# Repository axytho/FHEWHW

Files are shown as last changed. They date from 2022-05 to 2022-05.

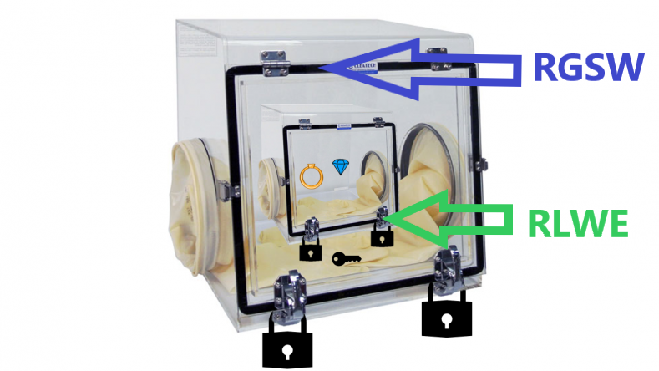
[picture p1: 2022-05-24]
ThesisProjectGit/Papers/graphicsDM/RLWERGSW.png

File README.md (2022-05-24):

# Parametric NTT/INTT Hardware

This repository provides the baseline version of Verilog code for parametric NTT/INTT hardware published in "<a href="https://ieeexplore.ieee.org/document/9171507">An Extensive Study of Flexible Design Methods for the Number Theoretic Transform</a>".

You have to set three parameters defined in `defines.v`:
* `DATA_SIZE_ARB`: bit-size of coefficient modulus *q* (constrained to the values between 8-64 for practical implementations)
* `RING_SIZE`: degree of ring polynomial, namely *n* in *x^n+1* (needs to be a power of 2)
* `PE_NUMBER`: number of processing elements (*butterfly units*) (needs to be a power of 2 and `PE_NUMBER` <= `RING_SIZE`/2)

Other versions of the hardware generator and documentation will be available soon.

If you use this work in your research/study, please cite our work:

```
@ARTICLE{9171507,
  author={A. C. {Mert} and E. {Karabulut} and E. {Ozturk} and E. {Savas} and A. {Aysu}},
  journal={IEEE Transactions on Computers}, 
  title={An Extensive Study of Flexible Design Methods for the Number Theoretic Transform}, 
  year={2020},
  volume={},
  number={},
  pages={1-1},
  doi={10.1109/TC.2020.3017930}}
```

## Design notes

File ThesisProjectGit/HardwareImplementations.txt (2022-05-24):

Hardware libraries:

Sujoy Roy's Coprocessor:
paper: https://www.iacr.org/archive/ches2014/87310183/87310183.pdf
hardware: https://github.com/sujoyetc/Ring-LWE-Cryptoprocessor

Tim Fritzmann's PQC accelerator:
paper: https://eprint.iacr.org/2020/446.pdf RISQ-V: Tightly Coupled RISC-V Accelerators for Post-Quantum Cryptography
Hardware: https://gitlab.lrz.de/tueisec/post-quantum-crypto
notes: ~10 times speedup of NewHope, 512 coefficient NTT in ~10 000 cycles

Parameterized Hardware Accelerators for Lattice-Based Cryptographyand Their Application to the HW/SW Co-Design of qTESLA
paper: https://caslab.csl.yale.edu/publications/wang2020parametrized.pdf
hardware: https://caslab.csl.yale.edu/code/qtesla-hw-sw-platform/
notes:  unified CT-GS-NTT algorithm specifically designed for polynomial multiplication (where you are doing NTT-1(NTT(A)*¨NTT(B)) )
for n=1024 and q = 343576577,  11455 cycles on ARtix-7

paper: https://ascslab.org/research/pqcp/index.html
hardware access: requesting it via e-mail

paper: http://www.cs.haifa.ac.il/~orrd/LC17/paper51.pdf
hardware access: https://www.seceng.ruhr-uni-bochum.de/research/publications/implementing-newhope-simple-key-exchange-low-cost-/

paper: https://eprint.iacr.org/2017/690.pdf
hardware access: cannot find a link, but I'll send a mail

ISA Extensions for Finite Field Arithmetic
%https://eprint.iacr.org/2020/049.pdf
source code?

FPGA-based High-Performance Parallel Architecture for Homomorphic Computing on Encrypted Data
https://github.com/KULeuven-COSIC/HEAT
HW can be requested

GPU implementation:
https://ieeexplore.ieee.org/stamp/stamp.jsp?tp=&arnumber=8855710
https://ieeexplore.ieee.org/stamp/stamp.jsp?tp=&arnumber=7245720

and full introduction on the NTT algorithm:
http://etd.lib.metu.edu.tr/upload/12625145/index.pdf

High performance NTT's!!!!! 
https://digitalcommons.wpi.edu/cgi/viewcontent.cgi?article=8433&context=mqp-all
THIS IS INTERESTING

Reuse one CRT block of the FV HEWS paper 			Check... (talk about it)
Modular reduction									check

Make look-up table which rotates through the accumulator  	check

Cut on the FV part.											check

Make clear that FV has bootstrapping but 								check
Just say you used SEAL and struggled a bit but don't go into detail.	check

Focus on the NTT diagram				check
Make mathematical part smaller			check
Focus on high level operation			check
No mathematical details					check

2 LWE cipher texts, you get another LWE.														uhm... somewhatcheck. 
You implement this by initializing a Look up table and then rotate this Look up table.			check
Cut slides.

One big table instead of slides																	check
Introduction slide of what NTT does and why it does don't explain Cooley Tukey: NTT is FFT on finite field. We need a very efficient 
Not going to do it from scratch																			check
These are open source, we will select one and impelement it
One final slide for plan, write a plannign table
Put changed planning on slide.

Present FHEW and don't talk about parameters yet
In the slides where you do matrix vector multiplication, these should be the parameters.
These are large polynomials, we need efficient polynomial multiplication

Don't show full algorithm!!! it makes no sense!
Look up tables. You rotate with matrix vector multiplication. At the end you'll have the correct value.
Focus on high-level.
Don't read from the paper.

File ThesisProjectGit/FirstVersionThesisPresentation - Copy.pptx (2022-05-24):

## Fastest Homomorphic Encryption in the West Hardware Acceleration

Master thesis presentation Jonas Bertels

## Selecting the scheme: (B)FV vs. FHEW

- Second Generation vs. Third generation

Faculty of Engineering Sciences, ESAT, COSIC

## Somewhat homomorphic encryption

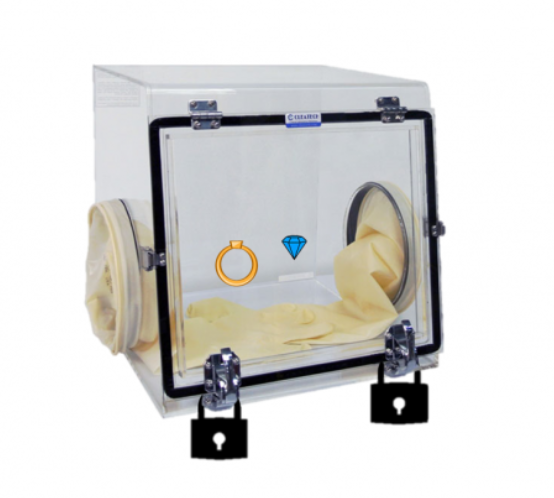
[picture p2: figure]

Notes: NOTE: IF EVERYONE KNOWS HOW HOMOMORPHIC ENCRYPTION WORKS, SKIP
The first major component of this thesis was selecting what homomorphic encryption scheme to implement. Before I go on, I first have to ask, is everyone here familiar with the basics of homomorphic encryption and bootstrapping?
If not:
Homomorphic encryption means encryption on which functions can still be executed. In 2009 Gentry showed that Fully Homomorphic encryption, doing an arbitrary amount of operations on encrypted data is possible. He later explained this using an analogy: imagine a jeweler Alice who wants to let her workers work on precious gems without them being able to steal the gems. She creates a box that allows the workers to manipulate the jewels, like this one. This box would Somewhat Homomorphic Encryption, because while the workers can do some operations, eventually the gloves break down and the workers have to bring the box back to Alice so that she can unlock the box, retrieve the finished jewels.

## Fully Homomorphic encryption: bootstrapping

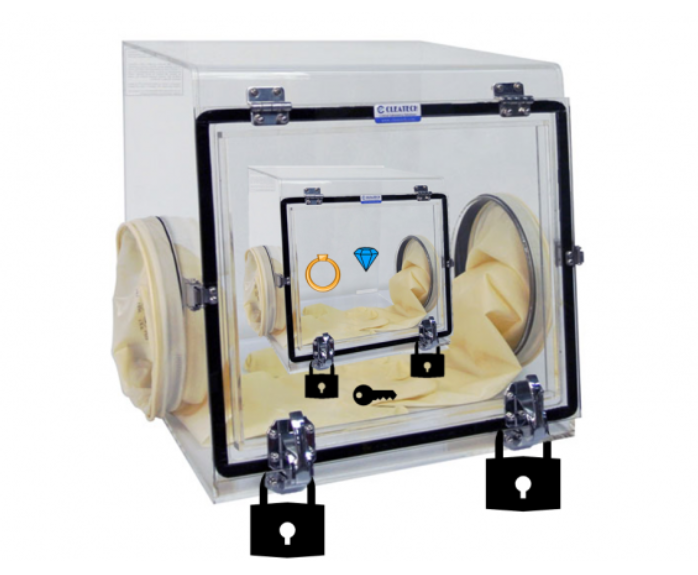
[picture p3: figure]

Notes: The idea behind bootstrapping is to turn Somewhat Homomorphic Encryption in to Fully homomorphic encryption by performing the decryption, i.e. the unlocking of the box, while everything is under another encryption. In our analogy, this would be like locking our box, in another box which already has a key for our box inside of it. (Since we using public/private key encryption, we place things into a locked box with the public key). Then our workers can open the inner box and continue working on the jewels. For an arbitrary amount of boxes, we can thus compute an arbitrary amount of functions on data that stays encrypted. The fact that gloves wear out in our analogy is representative of the fact that the homomorphic encryption schemes uses some form of numerical noise to mask the message. As we do addition, and especially multiplication, the amount of noise increases. At some point, decryption (whose last step is usually a sort of rounding operation to remove noise) will no longer return the correct answer.

## (R)LWE

For many vectors (ai,bi) ϵ (Rq, Rq), bi = ai * s+ ei with
- ei being a randomly sample error term
- s being our secret key
- ai being a randomly sampled but known vector
… it is not possible to find s (“not computationally feasible” (Roy et al.))
So good public key

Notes: Just for clarity, I am going to call the person with secret key who encrypted the data originally the user, and the person executing the function on the encrypted data the server.

An example of homomorphic encryption can be seen in the Fan-Vercauteren scheme. This is based on the Ring Learning With Errors Problem, which states the following. For many vectors (ai,bi) ϵ (Rq, Rq), bi = ai * s+ ei with ei being a randomly sample error term and s being our secret key and ai being a randomly sampled but known vector, it is not possible to find s (“not computationally feasible” (Roy et al.))

So in other words, we can use this term as a good public key for s since we can’t reverse engineer the secret from the public key. And this is the case if the server spends all day requesting public keys from the user to be able to guess the secret key.

## Scheme (simplified)

- Public key: ((-a*s-e)modq, a)
- Cipher text: ((-a*s-e)modq)*u+e1+m, a*u+e2) with u randomly sampled
- Then decryption can be done by multiplying the second part of the cipher text with s and adding it to the first part.

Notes: Now this is an extremely simplified version of the Fan Vercauteren scheme, just to give an idea: we generate our cipher text from our public key and our message, in such a way that we can get our message back by multiplying the second part of the cipher text with s and adding it to the first part.

## Homomorphic addition/multiplication

- Ct1 + ct2 = (2*(-a*s-e)modq)*u+e11+e12+m1+m2, 2*a*u+e21+e22) = m1+m2, with some error to be rounded off
- A multiplication also gives:
- The correct result + large error term + some factors multiplied by q.
- Now the result usually needs to be rescaled
- And polymial*polynomial = larger order polynomial, so linearization is necessary

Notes: Now why do we use this scheme? Because if we add the 2 ciphertexts or multiply the 2 cipherteksts, we still get the correct value after decryption! (if we’ve taken our modulus high enough).
Addition is the most straightforward: when we add, we add the 2 errors of the ciphertexts together and error growth is minimal.
Multiplication is much less straightforward. I did not write down all the terms of the multiplication, but to summarize: afterwards we need to rescale with a certain factor, and relinearize.

## Homomorphic multiplication

- As we’ve multiplied (cp1[0], cp1[1]) and (cp2[0], cp2[1]) together (remembering that cp1[0] + cp1[1]*s = message), can see m1 *m2 = cp1[0]*cp2[0] + cp1[0] *cp2[1]*s + cp1[1]*cp2[0]*s + cp1[1]*cp2[1] *s²
- So now a method to remove s² is also required
- And bootstrapping with this algorithm is not practical…

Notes: We need to rescale because the actual algorithm is scaling with a certain factor, and if you multiply 2 values scaled with a factor delta, the result will be scaled by a factor delta² and thus we need to divide back by delta to get our original scaling.
Secondly, we need to be able to remove the secret key squared term from our result. We call this the linearization step, but I will not go into details here.

## FV in SEAL

- Microsoft SEAL is a homomorphic encryption library that contains FV
- Tried implementing Arcsin(X/1500) *1/2 with arcsin(x) = x+x^3/6+3x^5/40
- Bootstrapping is not a thing, so not trivial to implement

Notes: To understand how FV actually worked and get an idea for the size of the parameters I was going to be working with, I installed micrsoft SEAL, a library for homomorphic encryption. I tried implementing a simple function (for calculating the angle you have to fire something at to reach a certain distance, which means calculating an arcsin, which can be approximated using a taylor expansion). Because there is no bootstrapping, it is necessary to determine in advance what size of polynomial coefficients will be for every multiplication done to calculate the polynomial series. Additionally, as the TA’s told me and I also found out by trying, it is hard to floating point operations with integers, when rescaling has to be done after every multiplication, requiring another multiplication with a constant factor.

## CKKS steps

- Choose coefficient
- Choose scale
- Generate public, private and relin keys

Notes: Therefore I switched to CKKS, which can be seen as a similar scheme designed for floating point operations.
To give an idea of what needs to be done: Firstly, the coefficient modulus of the polynomials must be chosen, so that there is enough noise budget to allow for the function that you want to execute. Then the scale (i.e. the precision of the floating point numbers) must also be chosen. Then public, private and realinerisation keys must be generated. Finally we can start doing multiplications and addition, but after every multiplication we must rescale and relinearize, and we need to do modulus switching as we go through the list of coefficient modulus primes that we generated to do our calculation.

## CKKS?

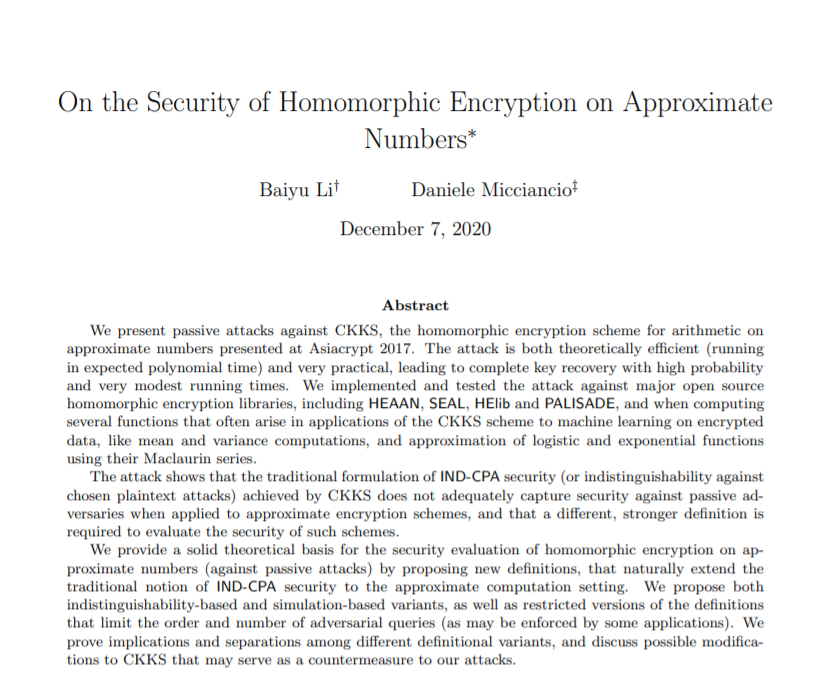
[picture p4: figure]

## Summary

- Good for SIMD
- Not good for depth of multiplications
- Somewhat inflexible

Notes: This required about a 100 lines of code for a rather simpel formula. It executed fairly quickly, and both FV and CKKS are good at allowing Single Instruction, Multiple Data, but as can be seen from this example, they only allow for a limited amount of computations, and algorithms that are already out there and require a lot of instructions will thus not easily translate in to programs that can homomorphically execute data.

They are however good at doing homomorphic encryptions for a given, low-depth application. This can also be seen in a hardware acceleration for the Fan-Vercauteren scheme done by COSIC in 2018. This implementation could do FV very quickly, at 400 homomorphic multiplications per second, but is limited to a multiplicative depth of 4. This is enough for a lot of applications, but can limit its flexibillity in a general role.

## FHEW (Fastest Homomorphic Encryption in the West)

- One NAND gate
- Bootstrap immediately
- 137ms for 128 bit security for 1 NAND + bootstrap
- No limit on function execution

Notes: FHEW, called that way as a reference to the Fastest Fourier Transform in the West library, is part of the so-called third generation schemes. It attempts to tackle the long length of the bootstrapping process by only executing one NAND gate (other simple gate functions are also possible) and then immediately bootstrapping.This makes it a true fully homomorphic scheme, as the bootstrapping can actually be done within a reasonable amount of time, namely 137miliseconds for NAND + bootstrap for 128 bit security on a intel i7. In other words, while only one NAND gate can be done at a time (later papers show parellisation is possible), there is no limit on the depth of our circuit, and as all functions can be written as a combination of logic gates, no limit on the functions that can be executed.

## Based on RLWE (from Ducas/Micciancio)

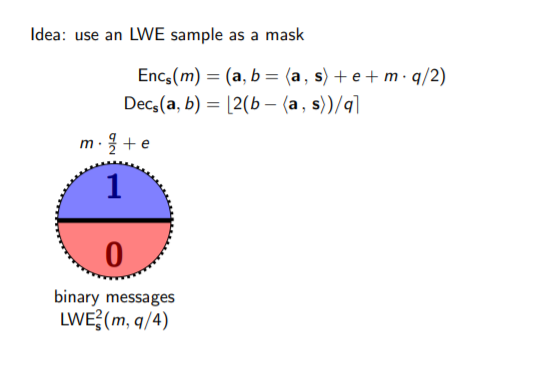
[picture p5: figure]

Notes: FHEW is also based on RLWE. The slides I’m about to show are taken from a excellent, very visual presentation by the creators of FHEW, Léo Ducas and Daniele Micciancio. Our message is a single bit. If it is 0, we could represent it as some error, if it is 1, we could represent it as 256 with some error added to it. (512 is a usual value for q). In this case our maximum error is equal to +/- 128.

## Based on RLWE (from Ducas/Micciancio)

- q = 512 so you can look at this as: if m = 0, we are in the lower half with e, if m=1, then we are in the upper half with 256 + e

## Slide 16

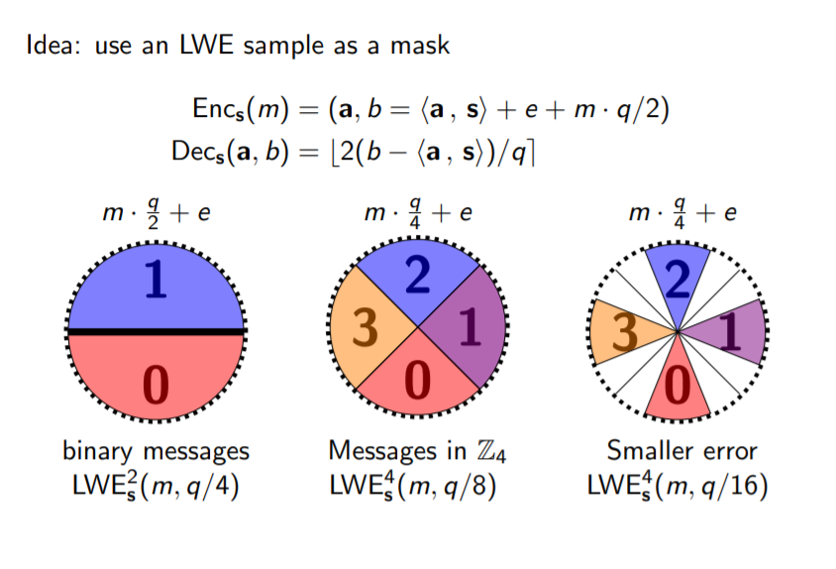
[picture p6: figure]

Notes: Now the representation that we use is one where there are 4 possible messages, with the message being multiplied by 128, or ¼ of the modulus q. We also have a smaller error of value 64 or q/8, so that there are values that are never reached by a given message and error. (these white spaces).

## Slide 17

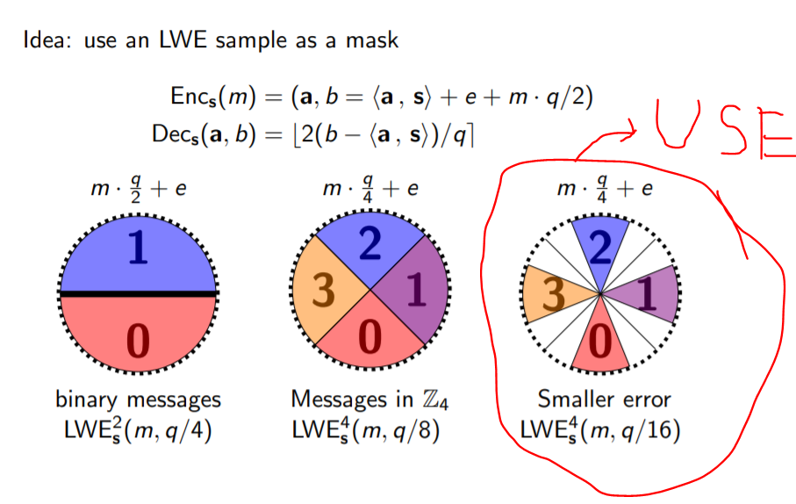
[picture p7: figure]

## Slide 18

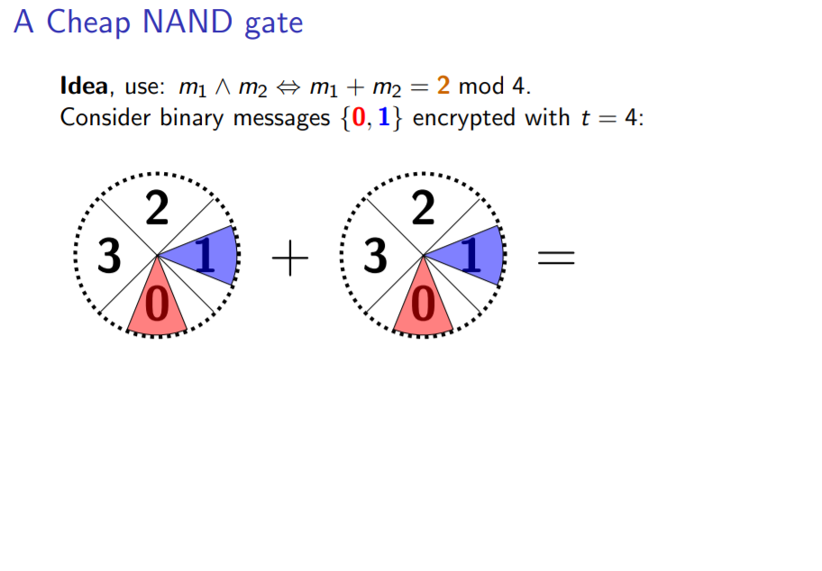
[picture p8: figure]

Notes: We can use this for addition. As you can see, the result now has more error than the beginning. Now if we consider every on the top left to be 1 and everything on the bottom right to be 0, we have a AND gate. To make this a NAND, we rotate by 5q/8, in other words we consider the bottom right to be 1 and the other 0 and this results in the results that we expect from a NAND gate for given input values.

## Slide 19

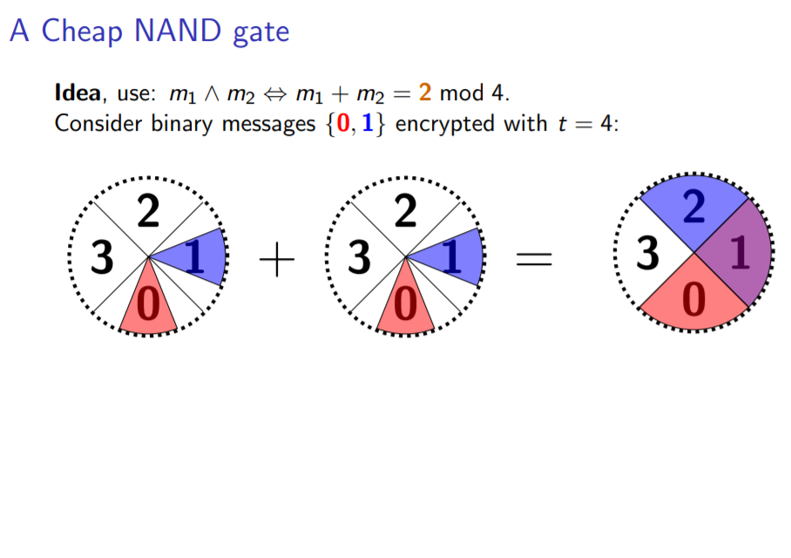
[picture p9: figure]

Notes: We can use this for addition. As you can see, the result now has more error than the beginning. Now if we consider every on the top left to be 1 and everything on the bottom right to be 0, we have a AND gate. To make this a NAND, we rotate by 5q/8, in other words we consider the bottom right to be 1 and the other 0 and this results in the results that we expect from a NAND gate for given input values.

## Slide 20

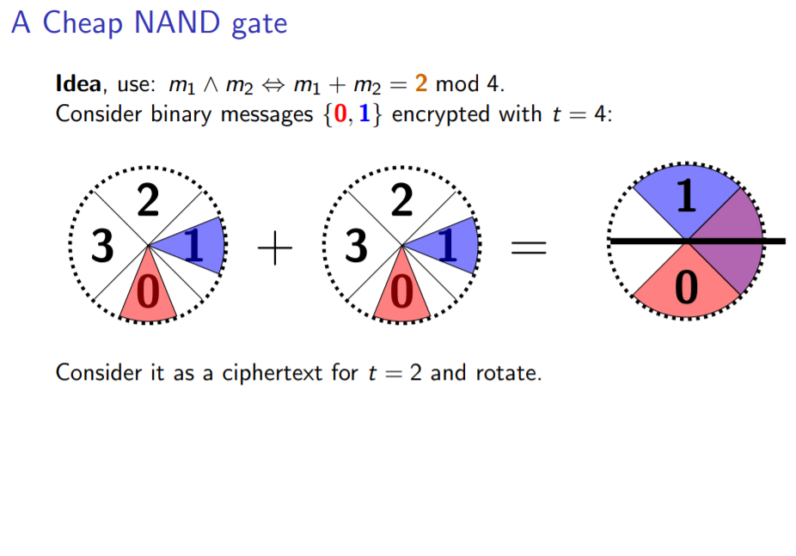
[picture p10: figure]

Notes: We can use this for addition. As you can see, the result now has more error than the beginning. Now if we consider every on the top left to be 1 and everything on the bottom right to be 0, we have a AND gate. To make this a NAND, we rotate by 5q/8, in other words we consider the bottom right to be 1 and the other 0 and this results in the results that we expect from a NAND gate for given input values.

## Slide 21

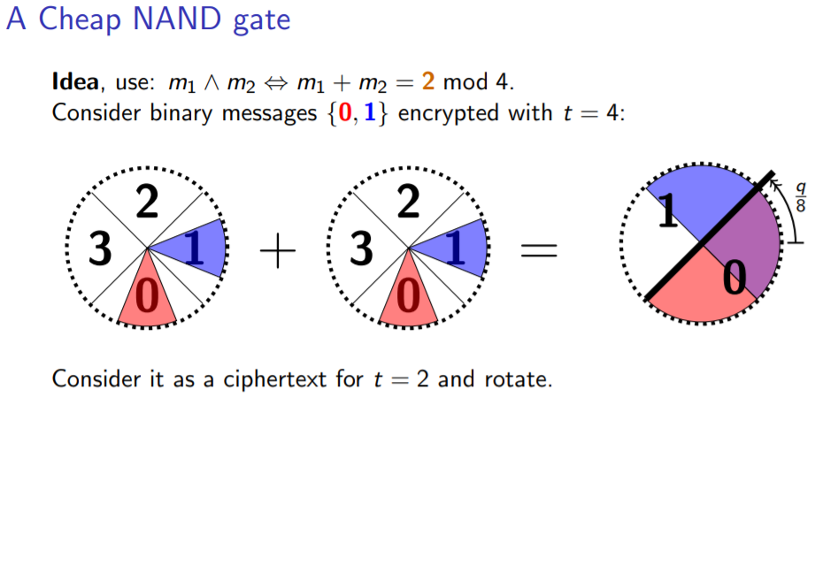
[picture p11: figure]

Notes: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

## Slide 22

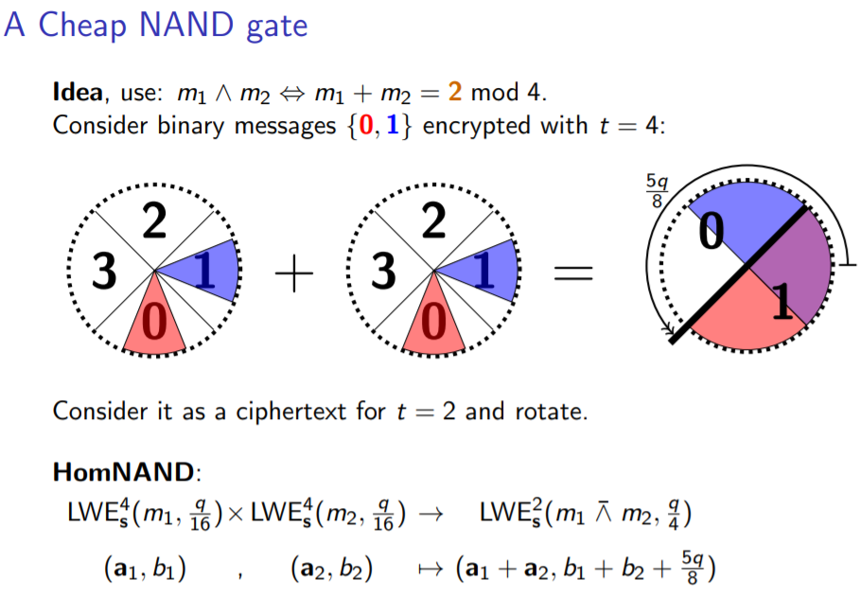
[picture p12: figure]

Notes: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

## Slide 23

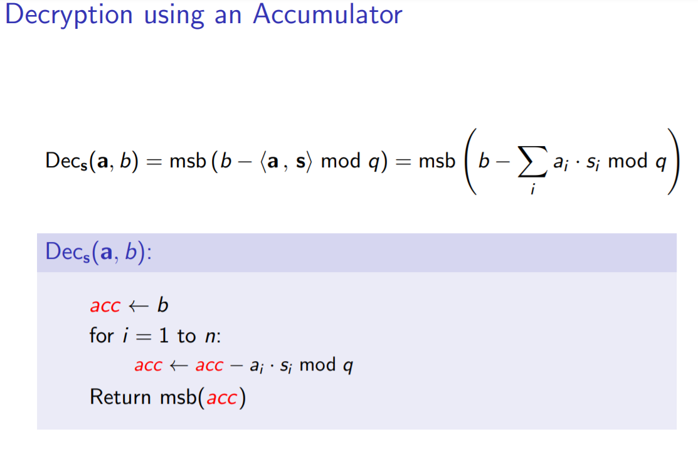
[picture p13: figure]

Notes: Then we need to bootstrap: remember, bootstrappping is doing decryption operations homomorphically, i.e. doing the decryption operations with an encrypted secret key. This reduces the noise back down to the original level, completing our algorithm.

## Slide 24

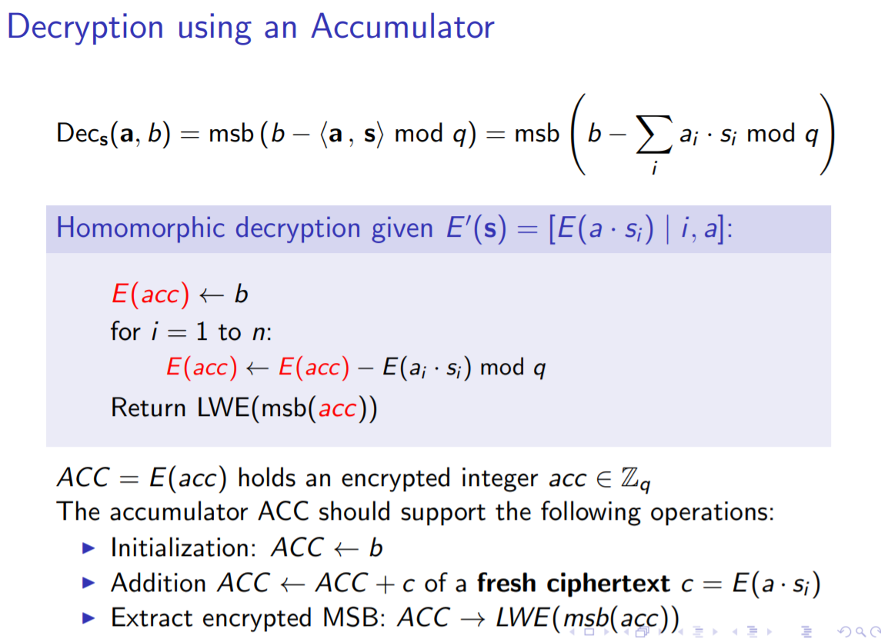
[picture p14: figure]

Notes: Then we need to bootstrap: remember, bootstrappping is doing decryption operations homomorphically, i.e. doing the decryption operations with an encrypted secret key. This reduces the noise back down to the original level, completing our algorithm.

## Intermezzo: why am I choosing this?

- Flexible because fully homomorphic
- Speed up is necessary
- No hardware implementation yet (for FHEW or TFHE)
- GPU implementations have been made

## LWE

- LWE ciphertexts: (a, b) with
- With q = 512 and n = 512, so a is a 512x1 vector with elements modulo 512 and b is an integer modulo 512

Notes: LWE ciphertexts look as follows and standard parameters are given. If we simply wanted to decrypt, we would calculate b-<a,s> and retreive our message through rounding, but this requires a secret key and gives us our result, which the server isn’t supposed to have.

## LWE decryption

- Now we want to decrypt our message (to remove noise)… BUT (decryption is b-a*s)
- We still want our message to be a secret so we need to do the decryption under another encryption, which does not have to be the same scheme

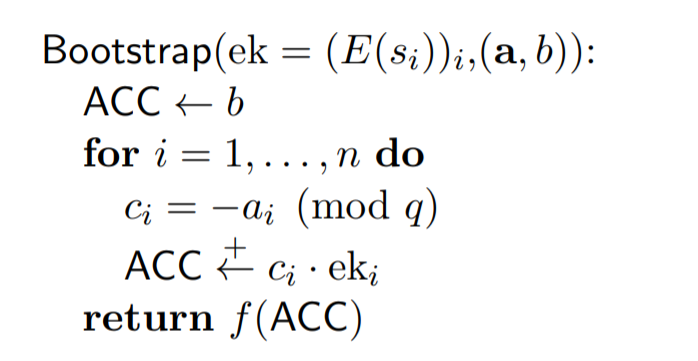
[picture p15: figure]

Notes: Instead, we want to encrypt this scheme under another scheme so we can decrypt the LWE ciphertext and gain the benefits, namely noise removal from our ciphertext due to rounding, without making security pointless. Remember

## Change LWE input to RLWE

- RLWE is more efficient so we take our LWE input → RLWE
- Our Secret Keys are encrypted in yet another scheme: RGSW

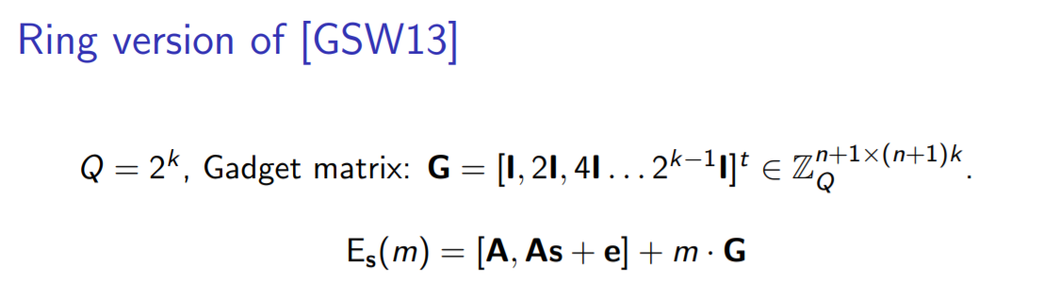
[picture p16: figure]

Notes: Now LWE is less efficient than RLWE so we take the input and turn it into RLWE. We also encrypt our secret keys using RGSW, which is a scheme that encrypts a message as 27 RLWE encryptions of 0, with message multiplied with shifted unity matrix 27 times. Q is a 27 bit prime. In our scheme, rather than multiplication with 2, we are multiplying with Br =23, but this is simply an optimization and you can forget that.

## Initialization

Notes: If our input is a LWE value called v, then it becomes an encrypted X^v RLWE value. To compute a rounding function f (which also does our rotation for our NAND), we store all the function output for given the function inputs 0 to 255, and we choose our rounding function so that the output for a value more that 255 is equal to the negative output of value minus 255. Then we can initialize our accumulator to a polynomial with the function outputs as coefficients.

## Initialization (q=512), m=0 or 1

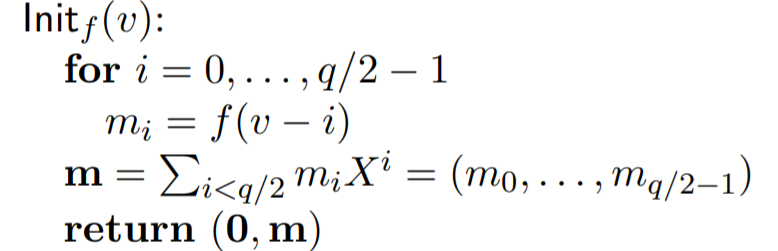
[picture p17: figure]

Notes: What we return, namely (0, m) is a noiseless RLWE with an a that’s equal to 0. But it is an RLWE encryption so we can do operations with this and add noise.

## Accumulation

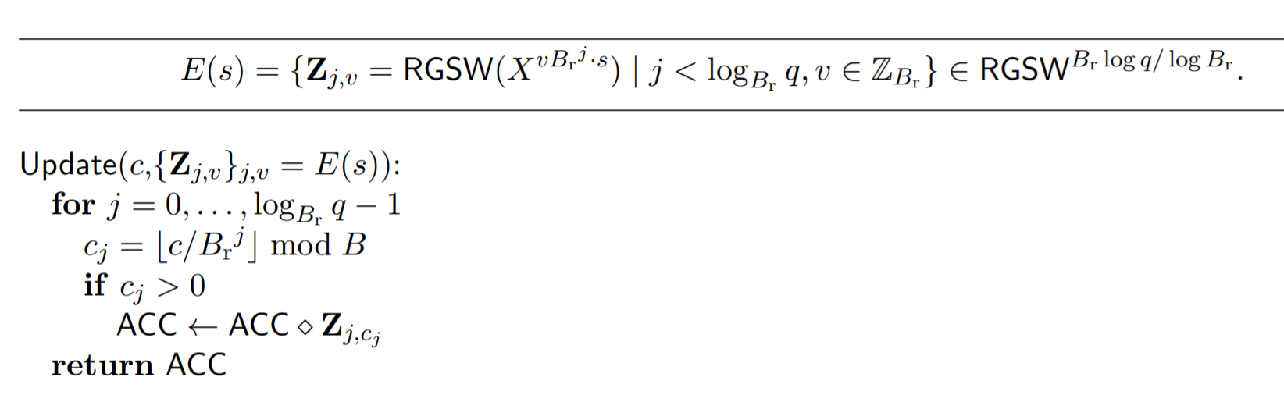
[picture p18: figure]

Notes: Now we come to accumulation. Seen from the LWE standpoint, we’re now going to subtract the inner product of a*s from our b. a is public and in plaintext, but we are allowed to multiply a RGSW value by a plaintext a. We then “subtract” this ai*si to our Accumulator by multiplying the RGSW and RLWE encryptions together. This is done via a special multiplicatio which returns an RLWE encryption of the Accumulator which, from a RLWE standpoint, rotates the functions by ai*si , and which, from a LWE standpoint, looks like an subtraction with ai * si. We then extract our result by taking the first value of our rotated functions, which is going to be our decrypted LWE whose error has been rounded of by our functions (and which has been rotated as required in advance). We would then have to do a key switching operation to complete our algorithm but… (continued)

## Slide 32

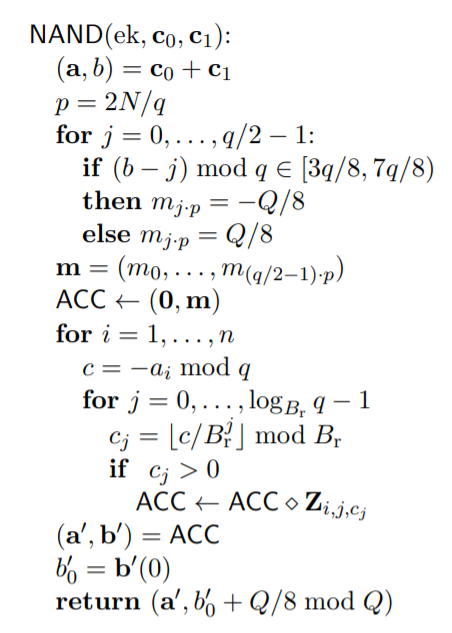
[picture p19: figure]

NAND->

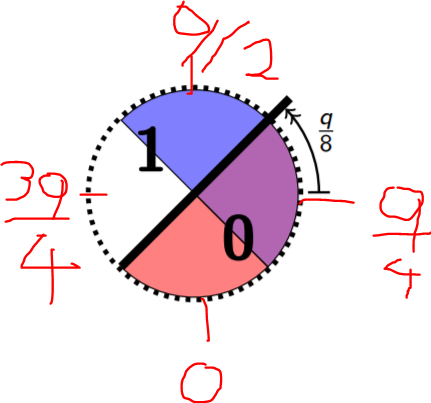
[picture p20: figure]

q = 512
Q ~ 2^27
Br = 23

Noiseless RLWE ->

LWE decrypted, but encrypted as RLWE->

Return LWE of RLWE (not under same key)>

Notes: The most performance challenging part for the server is of course the accumulation step. Every RLWE times RGSW operation is a vector times matrix operation.

## NTT multiplication

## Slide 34

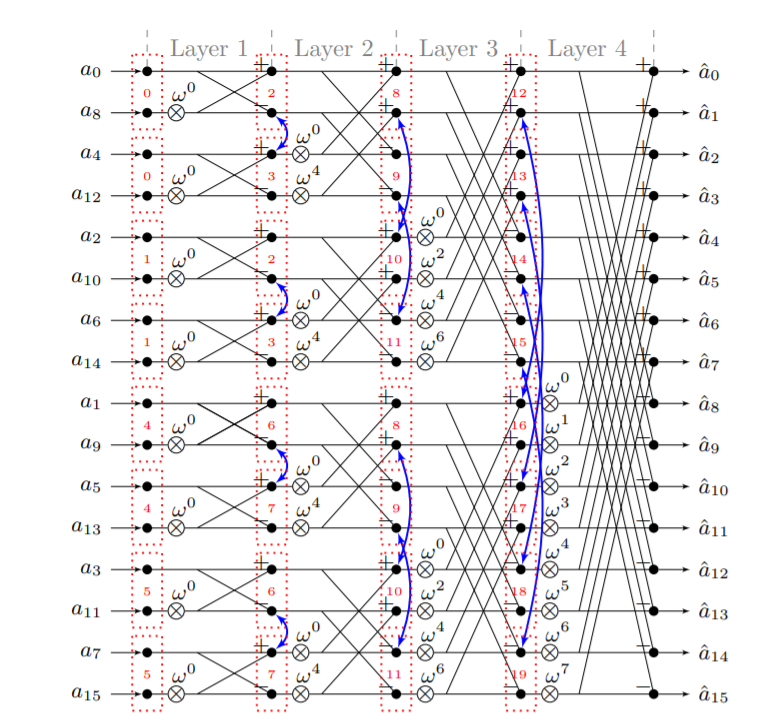
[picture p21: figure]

## Parameterized Hardware Accelerators for Lattice-Based Cryptography and Their Application to the HW/SW Co-Design of qTESLA (2020)

- Artix-7
- CS-NTT and GS-NTT⁻¹ but unify in one HW block
- n/2 · log2 (n) per NTT
- (n, q)= (1024, 343576577)
- 11, 455 cycles @ 126 MHz for 1 polynomial multiplication

## Parameterized Hardware Accelerators for Lattice-Based Cryptography and Their Application to the HW/SW Co-Design of qTESLA

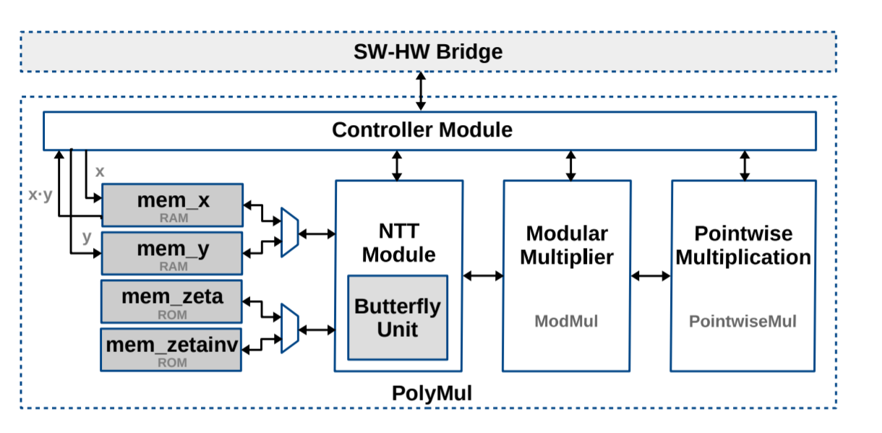
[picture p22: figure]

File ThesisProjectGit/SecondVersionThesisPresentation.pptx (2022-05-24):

## Fastest Homomorphic Encryption in the West Hardware Acceleration

Master thesis presentation Jonas Bertels

## Selecting the scheme: (B)FV vs. FHEW

- Second Generation vs. Third generation

Faculty of Engineering Sciences, ESAT, COSIC

## Somewhat homomorphic encryption


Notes: Somewhat Homomorphic encryption explanation

## Fully Homomorphic encryption: bootstrapping


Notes: Fully homomorphic encryption explanation

## (R)LWE

For many vectors (ai,bi) ϵ (Rq, Rq), bi = ai * s+ ei with
- ei being a randomly sample error term
- s being our secret key
- ai being a randomly sampled but known vector
… it is not possible to find s (“not computationally feasible” (Roy et al.))
So good public key

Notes: So in other words, we can use this term as a good public key for s since we can’t reverse engineer the secret from the public key. And this is the case if the server spends all day requesting public keys from the user to be able to guess the secret key.

## Second generation schemes (FV)

- Addition: simple
- Multiplication: not so simple
- The correct result + large error term + some factors multiplied by q.
- Now the result usually needs to be rescaled
- And polymial*polynomial = larger order polynomial, so linearization is necessary

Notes: Now why do we use this scheme? Because if we add the 2 ciphertexts or multiply the 2 cipherteksts, we still get the correct value after decryption! (if we’ve taken our modulus high enough).
Addition is the most straightforward: when we add, we add the 2 errors of the ciphertexts together and error growth is minimal.
Multiplication is much less straightforward. I did not write down all the terms of the multiplication, but to summarize: afterwards we need to rescale with a certain factor, and relinearize.

## FV in SEAL

- Microsoft SEAL is a homomorphic encryption library that contains FV
- Tried implementing Arcsin(X/1500) *1/2 with arcsin(x) = x+x^3/6+3x^5/40
- Went to CKKS

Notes: To understand how FV actually worked and get an idea for the size of the parameters I was going to be working with, I installed micrsoft SEAL, a library for homomorphic encryption. I tried implementing a simple function (for calculating the angle you have to fire something at to reach a certain distance, which means calculating an arcsin, which can be approximated using a taylor expansion). Because there is no bootstrapping, it is necessary to determine in advance what size of polynomial coefficients will be for every multiplication done to calculate the polynomial series. Additionally, as the TA’s told me and I also found out by trying, it is hard to floating point operations with integers, when rescaling has to be done after every multiplication, requiring another multiplication with a constant factor.

## Summary

- Good for SIMD
- Not good for depth of multiplications
- Somewhat inflexible
- Bootstrapping exists, but not practical to implement (i.e. bootstrapping in less than a second does not seem to exist for second generation)

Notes: This required about a 100 lines of code for a rather simpel formula. It executed fairly quickly, and both FV and CKKS are good at allowing Single Instruction, Multiple Data, but as can be seen from this example, they only allow for a limited amount of computations, and algorithms that are already out there and require a lot of instructions will thus not easily translate in to programs that can homomorphically execute data.

They are however good at doing homomorphic encryptions for a given, low-depth application. This can also be seen in a hardware acceleration for the Fan-Vercauteren scheme done by COSIC in 2018. This implementation could do FV very quickly, at 400 homomorphic multiplications per second, but is limited to a multiplicative depth of 4. This is enough for a lot of applications, but can limit its flexibillity in a general role.

## FHEW (Fastest Homomorphic Encryption in the West)

- One NAND gate
- Bootstrap immediately
- 137ms for 128 bit security for 1 NAND + bootstrap
- No limit on function execution

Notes: FHEW, called that way as a reference to the Fastest Fourier Transform in the West library, is part of the so-called third generation schemes. It attempts to tackle the long length of the bootstrapping process by only executing one NAND gate (other simple gate functions are also possible) and then immediately bootstrapping.This makes it a true fully homomorphic scheme, as the bootstrapping can actually be done within a reasonable amount of time, namely 137miliseconds for NAND + bootstrap for 128 bit security on a intel i7. In other words, while only one NAND gate can be done at a time (later papers show parellisation is possible), there is no limit on the depth of our circuit, and as all functions can be written as a combination of logic gates, no limit on the functions that can be executed.

## LWE

- LWE ciphertexts: (a, b) with
- With q = 512 and n = 512, so a is a 512x1 vector with elements modulo 512 and b is an integer modulo 512
- Start with 2 LWE ciphertexts, end with 1 LWE

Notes: LWE ciphertexts look as follows and standard parameters are given. If we simply wanted to decrypt, we would calculate b-<a,s> and retreive our message through rounding, but this requires a secret key and gives us our result, which the server isn’t supposed to have.

## High level explanation

- We start with a ciphertext encrypted under a certain scheme (like LWE)
- We decrypt the scheme to remove the noise (rounding removes noise)
- But while we decrypt, we encrypt it under another scheme (RLWE) using encrypted secret keys

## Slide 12


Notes: Then we need to bootstrap: remember, bootstrappping is doing decryption operations homomorphically, i.e. doing the decryption operations with an encrypted secret key. This reduces the noise back down to the original level, completing our algorithm.

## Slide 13


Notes: Then we need to bootstrap: remember, bootstrappping is doing decryption operations homomorphically, i.e. doing the decryption operations with an encrypted secret key. This reduces the noise back down to the original level, completing our algorithm.

## Intermezzo: why am I choosing this?

- Flexible because fully homomorphic
- Speed up is necessary
- No hardware implementation yet (for FHEW or TFHE)
- GPU implementations have been made (NNT implementations: 0.35 ms/bit for TFHE)

## RGSW (a matrix)

- Our Secret Keys are encrypted in yet another scheme: RGSW


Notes: Now LWE is less efficient than RLWE so we take the input and turn it into RLWE. We also encrypt our secret keys using RGSW, which is a scheme that encrypts a message as 27 RLWE encryptions of 0, with message multiplied with shifted unity matrix 27 times. Q is a 27 bit prime. In our scheme, rather than multiplication with 2, we are multiplying with Br =23, but this is simply an optimization and you can forget that.

## Initialize as encrypted Look-up table

9 | 8 | 7 | 6 | 5 | 4 | 3 | 2 | 1 | 0
0 | 0 | 0 | 0 | 0 | -f(4) | f(0) | f(1) | f(2) | f(3)

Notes: Our function f is a rounding function that also computer part of the NAND gate before it rounds. We create a look-up table which represents our function. , so we can still do operations on the table such as rotations.

The v that you see here is the LWE value that we are decrypting.

## Accumulation

9 | 8 | 7 | 6 | 5 | 4 | 3 | 2 | 1 | 0
0 | 0 | 0 | 0 | 0 | -f(4) | f(0) | f(1) | f(2) | f(3)

9 | 8 | 7 | 6 | 5 | 4 | 3 | 2 | 1 | 0
0 | 0 | -f(4) | f(0) | f(1) | f(2) | f(3) | 0 | 0 | 0

We rotate the RLWE encryption of the LUT by multiplying with the secret key matrix.

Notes: What we return, namely (0, m) is a noiseless RLWE with an a that’s equal to 0. But it is an RLWE encryption so we can do operations with this and add noise.

## Parameters

- Most challenging: matrix-vector polynomial ring multiplication
- Matrix: 1025x(3075)
- Vector: 1025
- Modulus Q: 27 bit prime
- A case for NTT (2*(1-1/23)*512*2*(3+1)) = 7836 NTT’s

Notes: With the matrix in this case having dimension 1025*6150 and the vector having dimension 1025. The only way to do this efficiently is to use the numerical fourier transform and the modulus of the values we’re multiplying being 27 bit.

The Br in this slide might become larger, as it increases the size of the bootstrapping key and the memory overhead from the bootstrapping key might become more important than the impact of doing a few more NTT. (If questions: dr = log(q)/log(Br) and dg = log(dg) / log(Bg)

## Hardware implementation changes

- “SignedDigitDecompose is a bottleneck operation”
- As an optimization, FHEW can decompose RGSW in base Br = 23 or another base
- Base Br breaks integers mod Q into digits
- Easier in HW with Br = 2^n
- Lower Br means lower size bootstrapping key but more NTT’s
- The tradeoff will shift after NTT becomes faster, so set Br = 2

## NTT multiplication

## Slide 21


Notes: Numeric-Theoretic Transform is a number theory variant of the fast fourier transform that allows us to do polynomial multiplications in n/2log(n) time.

## Latest NTT hardware implementations

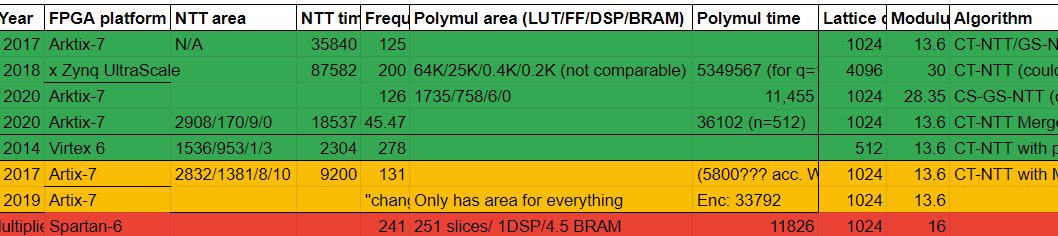
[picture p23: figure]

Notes: We’re looking for a lattice constant of 1024

Not going to do it from scratch
These are open source, we select the one which works for a modulus constant large enough, namely 28.65 bit, and implement that

## Parameterized Hardware Accelerators for Lattice-Based Cryptography and Their Application to the HW/SW Co-Design of qTESLA (2020)

- Artix-7
- CS-NTT and GS-NTT⁻¹ but unify (no bit reversal)
- n/2 · log2 (n) per NTT
- (n, q)= (1024, 343576577)
- 11, 455 cycles @ 126 MHz for 1 polynomial multiplication
- Uses Roy’s 2014 memory optimization
- Very parametrized, so allows be used for multiple parameter sets

## Parameterized Hardware Accelerators for Lattice-Based Cryptography and Their Application to the HW/SW Co-Design of qTESLA

- Modulus reduction can be optimized (works for any q = 1mod 2n, uses Montgomery reduction)
- Used 32 bit memory interface bus (very conservative)
- “users can also improve the performance further by using a specialized bus or interconnect”

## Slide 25

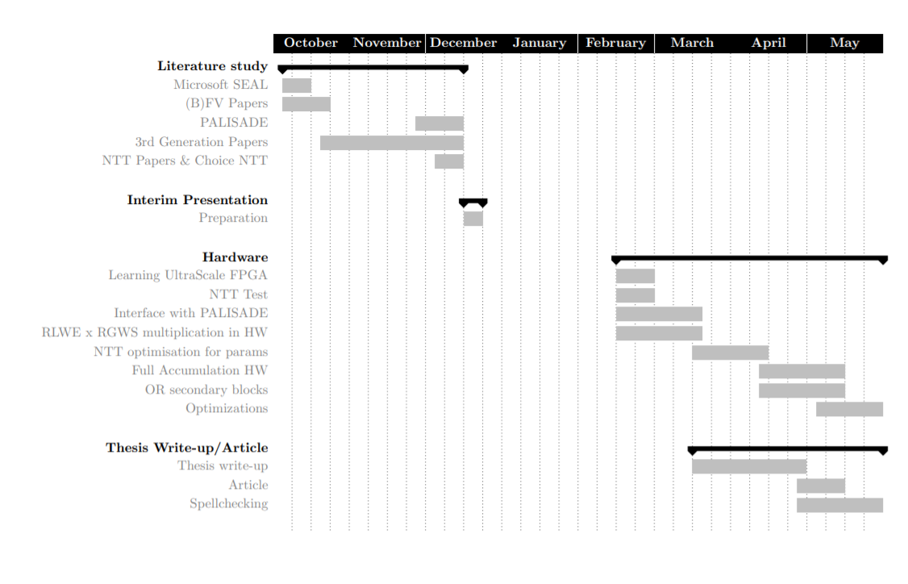
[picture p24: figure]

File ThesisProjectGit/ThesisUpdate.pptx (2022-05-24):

## Compact Ring-LWE Cryptoprocessor

Jonas Bertels

## My Design

- Protecting the channel and considering the user to also be the attacker

Faculty of Engineering Sciences, ESAT, COSIC

## The old model: but attacker has quantum computer

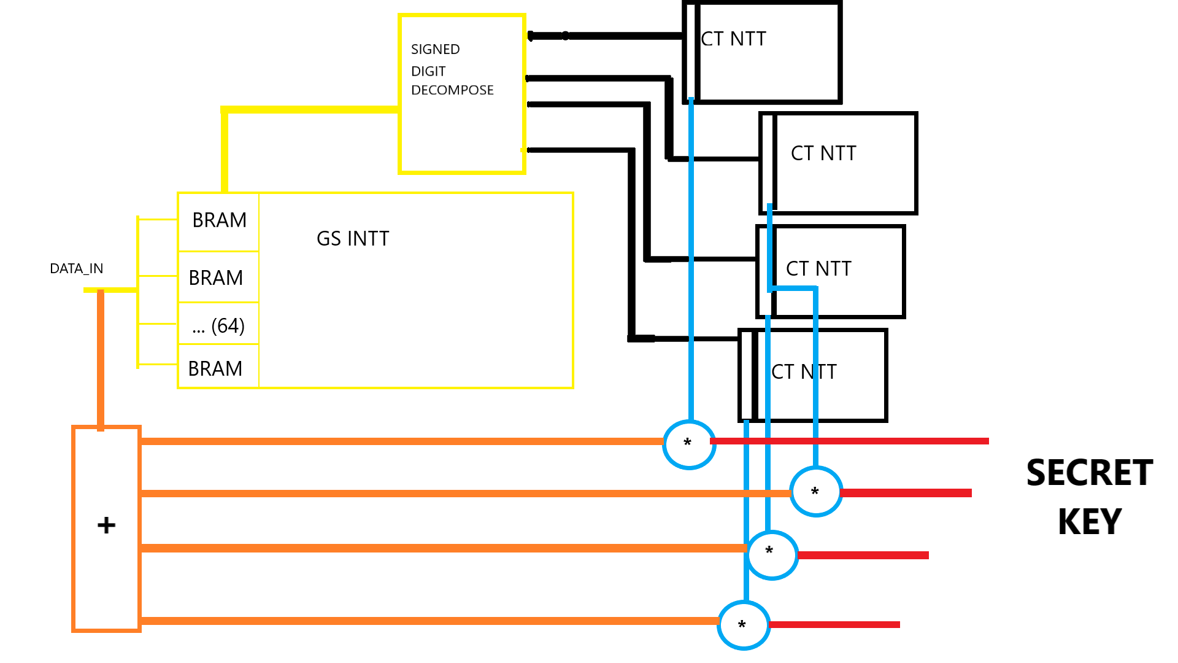
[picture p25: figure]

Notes: 2 big reasons for RLWE right now:

1) RLWE is resistant to attacks by quantum computers, as opposed to classical cryptographic schemes, where this is not the case. It can be proven that to break cryptography based on LWE or RLWE, an attacker would also be able to break other more fundamental problems, and we assume that since the latter cannot be broken the former can also not be broken.£

Don’t prove hardness, but prove that it is equally hard as some know hard problem.

Examples are NewHope. We call these application Post-Quantum cryptography because they are meant to guarantee the future of crypto after quantum computers become strong enough to break standard cryptograpy.

## BRAM TWICE AS LARGE?

## BRAM: 1 PE, RINGT_DEPTH=3


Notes: We use a variant of LWE called Ring LWE, because this provides more efficient calculations.

The problem we are now faced with when using LWE is that we need to do very large polynomial multiplications.

If we want our fancy cryptography schemes to be used in the real world, we need to make them energy efficient and fast.
The hardware designers here will now that to make something efficient you can trade off the flexibility of a CPU for the efficiency of a custom coprocessor.
This allows you to benefit maximally from the inherent parallelism of doing operations like multiplication with large polynomials.

In this case the coprocessor was implemented on a FPGA.

## BRAM: 2 PE’s: RING_DEPTH = 3


## BRAM itself?


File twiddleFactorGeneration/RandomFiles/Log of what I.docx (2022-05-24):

# Log of what I’m doing:

# Got Working license:


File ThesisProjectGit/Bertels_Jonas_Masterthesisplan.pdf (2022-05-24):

# Planning and Timeline for my Master Thesis on Hardware Acceleration of Homomorphic Encryption

Jonas Bertels

October 2020

## 1 Introduction

This document lays out the planning for my master thesis on hardware acceleration of Homomorphic Encryption.

”Fully homomorphic encryption (FHE) is a class of encryption algorithms that support any computation on encrypted messages without revealing anything about these messages in unencrypted form except for their maximal size. Using FHE, a party that owns private data can securely outsource computations on this data to another party. Due to this functionality, FHE finds many applications both in practice (e.g. cloud computing) and in the design of new cryptographic algorithms.” [1]

However, current algorithms are not efficient enough to be truly applicable which is why there is significant interest in hardware acceleration of these FHE schemes.

## 2 Planning

The thesis proposal suggested the following distribution of work:
- 20% on literature
- 20% on theoretical work
- 60% on the hardware implementation

In terms of my Individual Study Program (ISP), 9 study points were allocated to the first semester and 15 to the second semester. The FPGA on which the hardware implementation will be created will only be available in the second semester, and obviously most of the literature and theoretical work should be done before the hardware implementation. More specifically, these are the main tasks that must be finished:

1

### 2.1 Milestones

1. Determination of the scheme (by 26-10-2020) Before being able to implement a scheme, the scheme (or part of a scheme) that is to be implemented must be chosen. Therefore several papers on the available schemes must be read, both theoretical papers and papers outlining how these schemes can be implemented into hardware.
2. Deeper investigation into the chosen scheme (by 09-11-2020) After the scheme or part of the scheme to be accelerated is chosen, the different parts of the scheme must be broken down into modules that can be implemented piece by piece. This can only be done properly after the scheme is chosen, but for the purpose of this planning, we have assumed we would implement the FV scheme.
3. Hardware (by 03-05-2020) This can be broken down into several parts: learning to work with the UltraScale+ architecture, building the hardware modules, simulating to verify correctness and writing the required SW part. Once the FPGA is available, the design can then be implemented.
4. Thesis write-up (written by 01-05-2020, spell-checked by 31-05-2020) As the thesis will mirror my work done, this could be broken down in a literature survey, theoretical work and hardware section, but should mainly feature the latter.
5. Article (written by 16-05-2020, spell-checked by 31-05-2020) Writing the article after the thesis is finished should be a relatively straightforward task. While the article is being written, time can also be spent on the last milestone, namely further optimizing the HW and SW implementation.
6. Further optimizations (by 31-05-2020)

## 3 Gantt Chart

2

3

Literature study; Microsoft SEAL; (B)FV Papers; PALISADE; 3rd Generation Papers; Deeper investigation; Sorting modules in SW/HW; High-level module design; Interim Presentation; Preparation; Hardware; Learning UltraScale FPGA; HW block 1 sim. (i.e. NTT); HW block 2 sim. (i.e. Lift); HW block 1 impl. (i.e. NTT); HW block 2 impl. (i.e. Lift); Secondary HW blocks sim/impl; SW part 1; Optimizations; Thesis Write-up/Article; Thesis write-up; Article; Spellchecking

October November December January February March April May

4

## References

[1] Ilia Iliashenko. Optimisations of fully homomorphic encryption. PhD thesis, KU Leuven, May 2019.

5

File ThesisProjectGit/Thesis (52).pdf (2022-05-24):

Jonas Bertels; Thesis supervisor:; Mentors:; Academic year 2021 – 2022

Fastest Homomorphic Encryption in the
West Made Faster

Thesis submitted for the degree of

Master of Science in

Electrical Engineering, option
Electronics and Chip Design

Prof. dr. ir. Ingrid Verbauwhede

Ir. Michiel Van Beirendonck

Ir. Furkan Turan

Ir. Jose Maria Bermudo Mera
Dr. ir. Angshuman Karmakar

© Copyright KU Leuven

Without written permission of the thesis supervisor and the author it is forbidden to reproduce or adapt in any form or by any means any part of this publication. Requests for obtaining the right to reproduce or utilize parts of this publication should be addressed to Departement Elektrotechniek, Kasteelpark Arenberg 10 postbus 2440, B-3001 Heverlee, +32-16-321130 or by email info@esat.kuleuven.be.

A written permission of the thesis supervisor is also required to use the methods, products, schematics and programmes described in this work for industrial or commercial use, and for submitting this publication in scientific contests.

# Preface

I’d like to extend many thanks to Michiel van Beirendonck for the patient explanations, insights and corrections he made over the course of this year. His help accelerated my insight into the algorithm I set out to accelerate. Secondly, many thanks to Furkan Turan for explaining the many ways to interface, for his help with the hardware aspects of the thesis and for his general guidance on working with the relevant hardware. Many thanks go to Angshuman Karmakar and Jose Maria Bermudo Mera for providing feedback on this thesis, and to Prof. dr. ir. Ingrid Verbauwhede for providing me with this interesting topic.

Jonas Bertels

i

# Contents

Preface | i
Abstract | iv
List of Abbreviations | v
1 Introduction to Homomorphic Encryption | 1
1.4 Encryption Libraries and Homomorphic Encryption Schemes . . . . | 5
2 Preliminaries | 9
3 The Number Theoretic Transform | 21
4 Hardware Implementation | 31
5 Conclusion | 47

ii

Contents

A FHEW Algorithm flowchart | 51
B Paper | 53
Bibliography | 61

iii

# Abstract

Fully Homomorphic Encryption is encryption that allows operations to be done on encrypted data indefinitely. It is often considered the holy grail of cryptography for its wide-ranging applications. Both Fully Homomorphic and Somewhat Homomorphic schemes exist and are already in somewhat limited use, but the slow computation time, especially of Fully Homomorphic Encryption schemes, limits their adoption. More specifically, Fully Homomorphic Encryption schemes are often based on schemes such as Learning With Errors, where messages are masked by adding numerical noise. This noise grows as operations are performed, and bootstrapping removes it, but usually at a steep computational cost.
In this thesis, we accelerate FHEW bootstrapping in hardware. By modifying a fast hardware NTT implementation [23], we were able to increase the execution speed of FHEW bootstrapping by a factor of 7.5, provided that a fast interface to the FHEW bootstrapping key is available.

iv

# List of Abbreviations

## Abbreviations

ASIC | Application Specific Integrated Circuit
BRAM | Block RAM
CC | Clock Cycle
CT | Cooley-Tukey
FFT | Fast Fourier Transform
FHEW | Fastest Homomorphic Encryption in the West
FPGA | Field Programmable Gate Array
FV | Fan-Vercauteren
GS | Gentleman-Sande
INTT | Inverse NTT
LWE | Learning With Errors
NTT | Number Theoretic Transform
(R)GSW (Ring) Gentry-Sahai-Waters
TFHE Fully Homomorphic Encryption over the Torus

v

# Chapter 1

# Introduction to Homomorphic Encryption

## 1.1 An Introduction to Encryption

Let’s say it’s 1943 and you are the head of a resistance movement that helps downed pilots escape. To get the pilots out of Europe, you need to communicate with Great Britain to be able to arrange a pick-up in Spain. The only way to do this quickly and reliably is via radio. However, you are met with a serious problem: anyone can listen in to your broadcast. Therefore you need to send your message in a code. The British Special Operations Executive provided booklets called "one-time pads". These contained long rows of letters, as seen in Figure 1.1 and were used to turn the message, which we call "plain-text" into a jumble of seemingly meaningless letters. This process of turning plain-text messages into messages that cannot be understood by eavesdroppers is called encryption. Only the receiver in Britain, with the only copy of the one-time pad in the world, would be able to turn the encrypted message back into the original message.

What has been described is called symmetric key encryption, because both the sender and receiver are using the same booklet, which is called a "key" in cryptography. The use of it in WW2 posed certain problems: records were kept of all intercepted messages by the occupying forces, even when they were not understood. This way, when a radio operator and his one-time pad were captured, earlier messages could still be deciphered. Secondly, some way had to be found to provide radio operators with the one-time pad booklet, and a new booklet had to be created for every radio operator.

How to provide a user with a key without accidentally giving an eavesdropper the opportunity to acquire this key has always been a problem. To solve this, public-key cryptography was created. In public-key cryptography, there is both a secret and a public key. The receiver (we’ll call her Alice) makes her public key available to anyone who wants it, including potential eavesdroppers. However, the public key

1

1. Introduction to Homomorphic Encryption


Figure 1.1: One Time Pad [32]

can only be used to encrypt the data. Once a potential sender (we’ll call him Bob) has encrypted his message using the public key, he cannot reverse this process.

It is as if Alice had sent every person in the world a safe with a lock but without a key. If someone like Bob wants to send Alice a message, they simply take the safe, place their message inside of it, and lock the safe. Bob can’t unlock the safe anymore, but he can send the safe to Alice. Alice has a key that fits for all the safes she sent out, so she can unlock the safe and retrieve Bob’s message, without an eavesdropper (who we’ll call Eve from now on) being able to read the message, even if Eve has full access to the safe which contains Bob’s message.

## 1.2 An Introduction to Learning With Errors

Because there are many uses for cryptography, from securing messages to securing bank accounts, there are many cryptographic schemes, i.e., ways of encrypting and decrypting information. As previously mentioned, public/secret key schemes need to have a public key (i.e., a safe in which a sender can store information) and a secret key (i.e., a key to that safe that the receiver can use). If you are the receiver and you’ve chosen a secret key, you should be able to create a public key from this secret key. However, the opposite should obviously be impossible. After all, the public key is being given away to anyone and should not give (much) information about the secret key. Given enough time, you might be able to reverse engineer the public key into a secret key, so we call a scheme "secure" (i.e., good enough) if it takes so long and requires so many resources that it might as well be impossible. Impossible meaning that the required time to break the secret key is in the order of a small country dedicating all its computers for millennia for high enough security needs.

2

1.3. Homomorphic Encryption

These schemes have been in use for the past 50 years. However, quantum computers, which may become a commercial reality in the future, could speed up the process of breaking these schemes massively. This means that there is a pressing need for new schemes that are based on public keys that cannot be reverse-engineered into their secret keys.

Learning With Errors is a basis for many of these new schemes. In addition to being resistant to quantum attacks, LWE has another interesting feature: it can be used for Homomorphic Encryption.

## 1.3 Homomorphic Encryption

Homomorphic encryption means encryption where we can still do operations on encrypted data. If you encrypt the value 3 and you encrypt the value 5, you can send both these encrypted values to a server and ask the server to add them together, then return the result. Normally, the decrypted result would be some useless random value. Under a homomorphic encryption scheme, however, the result after decryption would actually be 8. Fast-working homomorphic encryption would have a wide-ranging impact on the financial sector, the web services sector and many other sectors in which a company in need of computation cannot trust the providers of computation to access their data.

There are two types of homomorphic encryption: Leveled Homomorphic Encryption and Fully Homomorphic Encryption. Leveled Homomorphic Encryption allows for a limited number of computations, Fully Homomorphic Encryption allows for an infinite number of computations. In 2009 Gentry [14] showed that Fully Homomorphic Encryption, i.e., doing an arbitrary amount of operations on encrypted data, is possible.

Gentry explained this using an analogy: imagine a jeweler, Alice, who wants to let her workers work on precious gems without them being able to steal the gems [1]. She creates a box that allows the workers to manipulate the jewels. This box represents Leveled Homomorphic Encryption, because while the workers can do some operations, eventually the gloves stop working (so that the workers can no longer continue the work, although the jewels are still safe). Thus, the workers have to bring the box back to Alice so that she can unlock the box and retrieve the finished jewels. If the workers haven’t finished their work yet, she must take the half-finished jewels from the box with the “worn” gloves and place them in a box with new gloves so that the workers can continue their work.

The “box” in this analogy is of course our encryption scheme “Learning With Errors”. “Alice” is the user while the workers represent a server that can do operations

3

1. Introduction to Homomorphic Encryption


Figure 1.2: The jewel box [1]

(such as addition, multiplication or others) on the encrypted data without being able to access it. The fact that gloves wear out in our analogy is representative of the fact that the homomorphic encryption schemes use some form of numerical noise to mask the message. As we do addition, or multiplication, the amount of noise increases. Multiplication increases the noise at a much greater rate than addition. Due to this noise increase, decryption of the data (whose last step is usually a sort of rounding operation to remove noise) will at some point no longer return the correct answer. At that point, our “worker” (i.e., the server which is doing the operations) has to stop or the output he gives will be wrong.

The idea behind "bootstrapping" is to turn Leveled Homomorphic Encryption into Fully Homomorphic Encryption. This can be done by performing the decryption, i.e., the unlocking of the box, while everything is encrypted under another encryption. In our analogy, this would be like locking our box in another box that already has a key for our box inside of it. (Since we are using public/secret key encryption, we can place things into a locked box with the public key without having to unlock said box. This is a feature of public-key encryption).

We call this unlocking while keeping the box locked under a different box "bootstrapping". We call it "bootstrapping" because it allows us to keep working on the encrypted message. Our workers can open the inner box using the secret key which is taped to the inside of the outer box and continue working on the jewels (see Figure 1.2). For an arbitrary amount of boxes, we can thus compute an arbitrary amount of functions on data that stay encrypted.

4

1.4. Encryption Libraries and Homomorphic Encryption Schemes

## 1.4 Encryption Libraries and Homomorphic Encryption Schemes

Several software libraries have been created to provide software developers with the tools required to use schemes in their messenger apps, database programs, financial application software, ...

We can split the homomorphic schemes that are currently the focus of most research into three generations. The first generation consists of older schemes that are so inefficient they are no longer being used. The second generation consists of schemes like the Fan-Vercauteren (FV) [10] scheme, the Brakerski-Gentry-Vaikuntanathan
[2] scheme and the Gentry-Sahai-Waters [15] scheme, which are primarily used for Leveled Homomorphic Encryption. The second-generation schemes allow for multiplication and addition but have a very compute-intensive bootstrapping process. The third-generation schemes such as FHEW [7] and THFE [3] only allow for 1 gate (such as a AND/OR gate), and bootstrap immediately, but the bootstrapping happens relatively fast (≈100ms)[24]. In this master thesis, one of these third-generation schemes is accelerated, namely Fastest Homomorphic Encryption in the West (FHEW) but it is still worth to first consider the Fan-Vercautren scheme.

### 1.4.1 Fan-Vercauteren: Leveled Homomorphic Encryption

FV has been the subject of hardware acceleration by multiple groups [25, 38, 35]. It is also implemented in the homomorphic encryption libraries SEAL [6] and PALISADE
[5] among others.
The problem with the second-generation schemes as previously mentioned is that bootstrapping takes so long the schemes usually forgo the bootstrapping for practical reasons. This means that any user of the libraries has a limited number of multiplications to work with (as we have seen, the limited noise growth of additions is usually negligible). This imposes constraints on the programmer.

In summary then: second-generation schemes execute fairly quickly, and as such schemes like FV are good for a certain class of programs with a limited amount of operations but a large amount of data. However, they only allow for a limited number of computations, and algorithms that are already out there and require a lot of instructions will thus not easily translate into programs that can homomorphically execute data. This can also be seen in a hardware acceleration for the Fan-Vercauteren scheme done by COSIC in 2019 [35]. This implementation could do FV very quickly, at 400 homomorphic multiplications per second, but is limited to a multiplicative depth of 4. Although this is enough for a lot of applications, it can limit its flexibility in a general role.

5

1. Introduction to Homomorphic Encryption

## 1.5 FHEW (Fastest Homomorphic Encryption in the West)

FHEW (the name is a reference to the Fastest Fourier Transform in the West library [11]) is part of the so-called third-generation schemes[7, 3]. It attempts to tackle the long length of the bootstrapping process by only executing one NAND gate (other simple gate functions are also possible) and then immediately bootstrapping. This makes it a true fully homomorphic scheme, as the bootstrapping can be done within a reasonable amount of time, namely 137 milliseconds for NAND + bootstrap for 128-bit security on an Intel(R) Core(TM) i7-9700 CPU [24]. In other words, while only one NAND gate can be done at a time (later papers show parallelisation is possible), there is no limit on the depth of our circuit, and as all functions can be written as a combination of logic gates, there is no limit on the functions that can be executed.

Because of its flexibility, a FHEW implementation that operated fast enough would have a large advantage in usability over a Leveled Homomorphic Encryption scheme. Programmers using FHEW do not need to worry about the noise growth of the scheme they are using, or when they should return their data to the client. The entire FHEW scheme provides the programmer with the basic binary gates, and as such, the programmer only has to worry about building their program from these binary gates. The programmer does not have to worry about the internal noise growth when using a Fully Homomorphic Scheme. It is for this reason that this scheme was chosen to be accelerated.

## 1.6 Hardware Acceleration

We have previously mentioned the term Hardware Acceleration when talking about an implementation of Fan-Vercauteren. Hardware acceleration means building a specialized electronic circuit to make a certain function run faster (in less time) or using less energy. Electronics built for one function only are faster than electronics built to execute software. The reason for this is simple: Specialized circuits can dedicate all their resources to executing very specific operations and as such the surfeit of resources can be dedicated to doing as many operations in parallel as possible. This increasing parallelism means increasing speed, as long as the algorithm itself can be implemented in parallel. In this thesis, we use an FPGA, which is a form of programmable electronics, where different electrical components are wired together according to a netlist that can be programmed from a computer. The other option for hardware acceleration would be to create an ASIC, which is an Application Specific Integrated Circuit. An ASIC can provide much higher speed gains than an FPGA, but it is significantly more expensive to create, as new hardware has to be physically created for it, and it is also much less flexible. Once created, in most cases it cannot be reprogrammed.

The main advantage of FPGAs is that they can provide a speed-up of a factor

6

1.6. Hardware Acceleration

10 to a factor 100 for a scheme like FHEW.[35] This is a smaller speed-up than an ASIC implementing the same algorithm would provide, as an ASIC does not dedicate resources to reprogrammability, but it is still a great improvement. Nonetheless, FPGAs are still specialized electronics. Once an implementation is shown to work well and is accepted to be worth it, an ASIC based on the FPGA’s implementation might one day end up in a consumer device, such as a laptop, a smartphone, or in the case of homomorphic encryption, a server, but this is unlikely to occur soon and requires significant investment.

In other words, Hardware Acceleration requires a new chip to become part of the server hardware when we use an ASIC, or for cloud servers to already contain an FPGA. Additionally, the encryption schemes which are hardware accelerated are still in flux, and there is no guarantee that a much faster scheme isn’t just over the horizon, rendering the investments in a specially built ASIC pointless. Software is much easier to deploy and requires no expensive investment. However, recently web hosting companies such as Amazon Web Services have started making servers with programmable FPGAs available [37], which makes deploying hardware almost as easy as deploying software. Given that the computational bottlenecks for Homomorphic Encryption schemes mainly lie at the server-side, hardware acceleration becomes a perfect solution to the speed problems faced by the Homomorphic Encryption schemes.

7

# Chapter 2

# Preliminaries

## 2.1 Definitions

We define Zq as the ring of integers modulo q, and Z
n

q as n elements x so that x ∈ Zq. Lattice-based cryptography uses polynomial rings for various optimizations. The polynomials rings we use are defined as R = Z[x]/f(x). In practice, a popular choice for f(x) is the 2d-th cyclotomic polynomial, with f(x) = x

d + 1 and d = 2m with
m ∈ N. We also define Rq = R/qR = Zq[x]/f(x), where again f(x) = x
d + 1 and
d = 2m.

We consider the discrete Gaussian sampling function DZ,σ. From this Discrete Gaussian function, we can sample values χ = Dd
Z,σ.

We define as the element-wise multiplication between two different vectors or polynomials.

## 2.2 Learning With Errors

In this section, we consider LWE, which is the basis for many homomorphic encryption schemes [31].

### 2.2.1 Definition of LWE

Three parameters are used : the dimension n, the message modulus t ≥ 2 and the ciphertext modulus q. We also define a randomized rounding function χ : R → Z with error with e being a randomly sampled error term from χ [8]. The secret key s is a vector and the secret key space is Z
n
q

, and the secret key may be chosen uniformly from this space.

We now define the LWE distribution (a, b) by defining (a, b) ∈ Z
n

q × Zq, with a
being a randomly sampled but known vector, and:
b = a s + e | (2.1)
| 9

2. Preliminaries

There are primarily two problems based on LWE [29]: search-LWE and decision-LWE. From k independent samples (ai

, bi) ∈ Z
n

q × Zq, it is not computationally feasible to find s. This is the search-LWE problem, which is thus hard. If we consider the problem from the case of the server: we cannot reverse engineer (a, b) into s, even if we have a very large quantity of a’s and b’s. The decision-LWE problem attempts to distinguish between a uniformly sampled vector and a valid LWE-distribution (a, b) given k independent samples (ai

, bi) ∈ Z
n

q × Zq which can be either. This problem is also hard. A symmetric encryption scheme can then be based on these problems.

### 2.2.2 LWE Symmetric Encryption Scheme

Our actual message m is a bit, not an integer. To encrypt a message m from the plaintext space Zt

, we first encode m into the ciphertext space Zq as m˜ =

q
t

∗ m with
q as always our modulus (=512, see parameter set STD128 in Table 2.5 [24]) and t being dependent on which LWE scheme we use (we therefore use the notation LWEt
s

).

Using these definitions for the message, we define the LWE encryption of a message bit m, so that q∗m
t = m˜ ∈ Z
n
q with a secret key s and a parameter t as: [24]

LWEt
s

( ˜m, E) = LWEt
s

(

q ∗ m
t
, E) = (a, a s + e + ˜m) = (a, b + ˜m) | (2.2)

with a ← Z
n
q

randomly sampled and e ← χ < E with χ as previously defined, a discrete Gaussian distribution with σ as parameter. The secret key s can be sampled from Z
n
q or from a smaller distribution. For the purpose of this work, we focus on Gaussian (i.e., the most general) secret keys.

Figure 2.1 shows a representation of such a message. From the representation, it is immediately obvious that the error should not exceed q
4 = 128.
We can now define our decryption function as:

LWE⁻¹
s
(a, b + ˜m) = b + ˜m − a ∗ s = ˜m + e | (2.3)

We can then recover m from m˜ by multiplying with t
q

and rounding the error away.

### 2.2.3 RLWE

We also define RLWE, for a message m˜ ∈ Rq under a secret key s ∈ R as [24]:

RLWEs( ˜m) = (a, as + e + ˜m) | (2.4)

with a ← Rq (chosen uniformly at random) and e ← χ.

We define RLWE because it is more efficient [21]. Lyubashevsky, Peikert and Regev [21] list two reasons. First of all, each product in RLWE contains d "simultaneously pseudorandom values" over Zq, as opposed to the one scalar given

10

2.2. Learning With Errors

in LWE. However, because the product is the result of polynomial multiplication, the computational cost is only on the order of O(n log(n)). Secondly, a sample (a, as + e + ˜m) ∈ Rq × Rq from RLWE can replace d samples of (a, b) ∈ Z
n

q × Zq.

### 2.2.4 Homomorphic Addition and Multiplication

We briefly consider a simplified Fan-Vercauteren scheme as an example of a homomorphic scheme which supports addition and multiplication and is created using RLWE [10].

We again form the RLWEs( ˜m) ciphertext as:

ct = RLWEs( ˜m) = (a, b = a · s + e + ˜m) | (2.5)

with
a ← Rq, s ← Rq and e ← χ | (2.6)

We can add two ciphertexts encrypted under the same secret key:

ct⁰ = HomAdd(ct0, ct1) = (ct0[0] + ct1[0], ct0[1] + ct1[1])

= (a0 + a1,(a0 + a1) · s + (e0 + e1) + ( ˜m0 + ˜m1))

(2.7)

Such that RLWE⁻¹
s

(ct⁰
) = ( ˜m0 + ˜m1) + (e0 + e1). When we multiply two ciphertexts, we take their tensor product.

ct⁰ = HomMul(ct0, ct1) = (ct0[0] · ct1[0], ct0[0] · ct1[1] + ct0[1] · ct1[0], ct0[1] · ct1[1]) (2.8)
It can then be shown [10] that ct⁰
is a ciphertext encrypting the product of m˜ 0 and m˜ 1. Note that because m˜ =

q
t

∗ m, our product m˜ 0 · m˜ 1 = q

2/t²
- m0m1. Each
multiplication will thus increase the size of the message we are encrypting. We would prefer to encrypt q/t · m0m1. Secondly, our ciphertext ct⁰ has three elements as opposed to the original two elements of ct0 and ct1. To solve these issues, second-generation schemes like FV have a rescaling and relinearisation option, respectively. FHEW takes a different approach, which we will focus on in this thesis.

### 2.2.5 RLWE’ and RGSW

We now introduce two more definitions based on RLWE, which we need when discussing FHEW. RLWE’ is defined as [8] [24]:

RLWE⁰
s
(m) = (RLWEs(m), RLWEs(Bg ∗m), RLWEs(B

2
g ∗m), ..., RLWEs(B

k−1
g | ∗m))
| (2.9)
with Bk
g = q. (In our parameter set, Bg = 128 = 2⁷
). The reason for this definition is that we want a system that creates as little noise as possible when operations are
| 11

2. Preliminaries

completed. By breaking RGSW into bases, less noise is generated ([24], see section 5.1). Multiplications with a d ∈ Rq so that d =
P

i Bi
gdi are defined as:

() : R×RLWE⁰ → RLWE : d ∈ R, c ∈ RLWE⁰ : d(c0, ..., ck−1) = X

i

dici (2.10)

We can extend this multiplication definition to a multiplication that results in RLWE’:

(

0

) : R×RLWE⁰ → RLWE⁰
: dC = ((B

0
g ∗d)C,(B

1
g ∗d)C, ...,(B

k−1
g | ∗d)C)
| (2.11)
And finally, using these definitions, the RGSW scheme can also be defined, which will allow multiplication of ciphertexts. We need this ability if we want to run the RLWE decryption while everything is encrypted under RGSW (this will be explained in-depth in the bootstrapping section).

RGSWs(m) = (RLWE⁰
s

(−s ∗ m), RLWE⁰
s
(m)) | (2.12)

To be able to use our secret key s encrypted under RGSW, we can multiply an RGSW ciphertext RGSW(m1) = (c, c’) with an RLWE’ ciphertext RLWEs(m0, e0) = (a, b) and get a result that when decrypted gives the product of the 2 messages [24]:

(a, b) (c, c’) = h(a, b),(c, c’)i = a c + b c

0 | (2.13)
= a RLWE’s(−s ∗ m1) + b RLWE’s(m1) | (2.14)
= RLWEs((b − a ∗ s) ∗ m1) = RLWEs((m0 + e0) ∗ m1) | (2.15)

This RGSW×RLWE⁰ → RLWE can be turned into a RGSW×RLWE⁰ → RLWE⁰
In Chapter 4 in Algorithm 3, we will see how this multiplication is implemented. We will also see how the RGSWs(m) = (RLWE⁰
s

(−s ∗ m), RLWE⁰
s

(m)) is created
through Algorithm 4. Briefly, each coefficient of the polynomial is broken down through a signed digit decomposition. Then a multiplication with an RLWE’ vector occurs. As mentioned at the start of the section, using RLWE’ instead of RLWE for the multiplication reduces the generated noise. Once the multiplication is completed, the results are summed.

## 2.3 FHEW (Fastest Homomorphic Encryption in the West)

We now consider, FHEW, the algorithm for which we design a hardware accelerator. FHEW uses LWE²
s

(see equation 2.2), where our original message is a single bit. If it is 0, we could represent it as some error, if it is 1, we could represent it as q
| 2 (= 256)
with some error added to it, as shown in Figure 2.1. For LWEt
s with t = 2, our
maximum error is equal to ±

q
2t = 128. We can now present LWE⁴
s

(see equation 2.2).
This representation allows for 4 possible messages, with the message being multiplied by q

t = 128, which is q
4

(Figure 2.2). Our maximum error value, in this case, is

12

2.3. FHEW (Fastest Homomorphic Encryption in the West)


Figure 2.1: Binary Message representation of m ∗

q
2 + e in LWE²
s

(m,

q
4

) (taken
| from[9])


Figure 2.2: Messages in LWE⁴
s

(m,

q
8

) [9]


Figure 2.3: Messages in LWE⁴
s

(m,

q
16 ) with smaller error [9]

13

2. Preliminaries
Result of the Sum | 0 | 1 | 2 | 3
Result of a AND gate | False (0) | False (0) | True (1) | N/A

Table 2.1: Creating an AND gate from the sum of 2 bits


Figure 2.4: Result of the addition [9]


Figure 2.5: Creating an AND gate [9]

±

q
8

(= 64). This is written as LWE⁴
s

(m, q/ ˜ 8). The error can be reduced further, as can been seen on the right of Figure 2.3, so that there are values that are never reached by a given message and error (white space in Figure 2.3). This is written as LWE⁴
s

( ˜m, q/16).

We can use LWE⁴
s

(m, q/ ˜ 16) messages for addition (Figure 2.4) (again, see equation 2.2). After addition, the result now has more error than the beginning, because the noise adds up.

Our interest lies in making a functional binary gate, such as a NAND gate. The NAND gate is a universal gate, from which arbitrary circuits can be created. For a NAND gate, consider Table 2.1. We first create an AND gate from the addition of 2 encrypted messages. If the resulting sum’s error stays small enough to decrypt correctly (i.e., if the colours of Figure 2.4 do not shade into each other), we can map a result of 2 to a True outcome of the AND gate, and a result of 0 or 1 to a False outcome of the AND gate.

If we consider everything on the top left to be 1 and everything on the bottom right to be 0, we have an AND gate (Figure 2.5 and Table 2.1). To make this a NAND, we rotate by q
2

, in other words, we consider the bottom right to be 1 and the other half to be a 0, and this results in the results that we expect from a NAND gate for the given input values (Figure 2.6).

14

2.4. Bootstrapping


Figure 2.6: The final NAND gate [9]

If we look at the result of our NAND gate, we immediately see a lot less white space than previously. As previously mentioned, the noise has increased. We originally had two LWE⁴
s

(m, q/ ˜ 16) inputs, and now we have one LWE²
s

(m, q/ ˜ 8) output. Clearly, if we were to use this output as the input of our next binary gate, it is possible that we would no longer decrypt the correct result. As such we need to find some way of reducing the noise.

## 2.4 Bootstrapping

As mentioned in the introduction, the FHEW scheme is motivated by the need for fast bootstrapping [8]. This fast bootstrapping is necessary for "practical" Fully Homomorphic Encryption.

### 2.4.1 Introduction to Bootstrapping in FHEW

What we’ve discussed until now is the underlying encryption system. If we go back to our analogy from the introduction, the LWE scheme is the box that the workers use to assemble the jewels. As we have seen, the gloves on this box are one-use-only (we only do one NAND gate, or a similarly small binary gate operation to go from LWE⁴
s

(m, q/ ˜ 16) to LWE²
s

(m, q/ ˜ 8)). The workers now need a larger box in which they can put this LWE box, so that they can unlock the LWE box and put the jewels in a new (small, LWE) box with new gloves (in other words, with reduced maximum error q/16). This (larger) box will be provided by RGSW. By encrypting our secret keys under RGSW, we can safely send them to the server without breaking security by giving the server the means to decipher the LWE ciphertext into plain text.

As mentioned before this process is called bootstrapping. Bootstrapping is done by executing decryption operations homomorphically, i.e., doing the decryption operations with an encrypted secret key. This reduces the noise back down to the original level, completing our algorithm.

### 2.4.2 Bootstrapping Algorithm

We now turn our attention to the bootstrapping process itself, first formally using the algorithm described in [24]. The bootstrapping consists of 3 steps: Initialization (see Algorithm 1), Accumulation (Algorithm 2) and Extraction (which simply consists of

15

2. Preliminaries


Figure 2.7: The LWE ciphertext is encrypted under an RGSW ciphertext so that it can be decrypted using LWE secret keys, which themselves have been encrypted under RGSW

taking the first value of the second part of the RGSW result).

Algorithm 1: Initialization[24]
Data: b such that (a, b) = c0 + c1 with c0 and c1 encrypted input of NAND Result: ACCf [b] = RLWEPq/2−1
i=0 f(b − i) ∗ Xi
∈ R²
q

### 1 begin 2 for i = 0, 1, ...q/2 − 1 do

3 mi = f(b − i);

### 4 Note that f is our lookup table 5 end 6 m =

P

i<q/2 mi ∗ Xi = (m0, m1, ..., mq/2−1 );
7 Return (0, m);

### 8 end

Initialisation

We implement the rounding function and NAND gate described in the previous section as a lookup table. In a lookup table, the result of an input i is stored at index i and executing the function thus simply requires looking at the value at index
i. For example, we can turn a NAND gate into a lookup table by first calculating the sum of the 2 inputs, a and b. For index a+b, we then have the results in Table 2.2.

In FHEW, a polynomial is used as a lookup table. The value at index i in the table is given by the coefficient of Xi
in the polynomial. To explain our scheme, we will use tables rather than polynomials, and reduce the length of the table/polynomial from n = 512 to n = 8.

16

2.4. Bootstrapping

Algorithm 2: A Single Accumulation Step[24]
Data: ACC, an RGSW ciphertext and E(s) = {Zj,v = RGSW(Xv∗Bs
r ∗s
|j <
logBr

(q), v ∈ ZBr } ∈ RGSWBr∗logBr

(q)
Result: ACC, updated with ai ∗ si

### 1 begin 2 for j = 0, 1, ... logBr

(q) − 1 do

### 3 cj = bc/Bj

r

c mod B;

### 4 if cj > 0 then 5 ACC ← ACC Zj,cj

;

### 6 end 7 end

8 Return ACC;

### 9 end

a + b = 3 (not possible) | a + b = 2 | a + b = 1 | a + b = 0
N/A | 0 | 1 | 1

Table 2.2: Initial polynomial for v=1 and n=8

Index of Coefficient | 7 | 6 | 5 | 4 | 3 | 2 | 1 | 0
Value of Coefficient | 0 | 0 | 0 | 0 | f(-2) = f(2) | f(-1) = f(3) | f(0) | f(1)

Table 2.3: Initial polynomial for v=1 and n=8

Our lookup table is initialized to the formula seen in Algorithm 1 (see Table 2.3). This LUT is an implementation of our binary gate (our NAND for instance) and our rounding function (which is the final step in a LWE decryption, after the subtraction of ai

- si for all i). The only operation that we will from now on perform on this lookup table is to rotate the indices. With rotation, we mean that we change the lookup table so for index i
i → i + r (mod LUT size) | (2.16)

Rotating a lookup table is the same as adding or subtracting from the input index of the lookup table. It does not affect the function that the lookup table represents, only the index.

When we initialize our lookup table, we give it an initial rotation, so that the result of g(LWEt
s

(m, q ˜ )), with g(x) our combined NAND and rounding function, is found under the index 0. We can also see this LUT as an RLWE ciphertext, as described in Algorithm 1. That the LUT is also an RLWE ciphertext is important in the accumulation step.

| 17

2. Preliminaries
Index of Coefficient | 7 | 6 | 5 | 4 | 3 | 2 | 1 | 0
Value of Coefficient | 0 | 0 | f(-2) = f(2) | f(-1) = f(3) | f(0) | f(1) | 0 | 0

Table 2.4: Results after subtraction by ai ∗ si = 2

n | q | N | Q | Bg | Br
512 | 512 | 1024 | 27 134215681< 2 | 128 | 23

Table 2.5: Parameters for STD128

Accumulation

Another way to look at the LUT is as a noiseless RLWE encryption of a polynomial. In this case the coefficients are the results of the rounding+NAND function (Table 2.3). A rotation of the lookup table by a value is an addition of that value to the index. Addition on the LWE level is then performed using multiplication on the RGSW level. The reason for this is again our lookup table. When we rotate the lookup table leftward, from the LWE perspective we are subtracting aj ∗ sj from the index (which was originally v). From an RGSW or RLWE perspective, a rotation by a value aj · sj is a multiplication of the polynomial with a value Xaj ·sj

Now that we know we can do additions on the LWE⁴
s

(m, q/ ˜ 8), we know we can decrypt it. So, we simply perform a series of RGSW ⁰ RLWE⁰ → RLWE⁰ multiplications to perform the decryption b − a ∗ s. Table 2.4 shows one rotation through a lookup table.

Extraction

After extracting the correct value from the polynomial (i.e., the coefficient of X⁰ ),
which is the constant term or the rightmost value in our table, a key-switching step occurs to change from the keys used in the Accumulator back to the keys of the RLWE. This step does not concern this thesis as we are mainly interested in resolving the bottleneck operation of FHEW, which is in the accumulator loop.

The full bootstrapping algorithm can be found in flowchart form in Appendix A. The parameters for which our hardware implementation was designed are given in Table 2.5.

## 2.5 Notes on Previous Optimisations

The version that is accelerated in this thesis is an optimized variant ([24]) of the FHEW scheme originally introduced in 2014 [8]. The only optimisation paper on this scheme yet was an effort to make FHEW run on multicore CPU and GPU’s, where

18

2.6. Conclusion

they achieved a speed-up of about 2.2 using CUDA on the 2015 version of FHEW [18].

Another optimisation paper introduced NuFHE [26], which uses another third-generation scheme called TFHE with GPU acceleration and succeeded in executing about a 100 times faster than the original scheme, bringing the cost of homomorphic encryption down to 0.13 ms/bit for binary gates (for FFT implementation). For implementations using the NTT, it is 0.35 ms/bit. However, this scheme implemented full adders and took advantage of the fact that multiple bits can be packed into one cipher text, then divided the total bootstrapping speed by the number of bits in one adder. No attempt at packing is made in this thesis.

## 2.6 Conclusion

By understanding the working of the FHEW scheme, it is possible to understand the bottleneck operations, and from this gain understanding of how to best accelerate the scheme. The accumulation, which consists of n RGSW × RLWE⁰ → RLWE multiplications, is the bottleneck of the FHEW algorithm. Therefore, it is best to focus on the acceleration of this part. More specifically, an efficient multiplication module will be key to accelerating FHEW. An important algorithm for efficient polynomial multiplication, the Number Theoretic Transform, will be explained in the next chapter.

19

# Chapter 3

# The Number Theoretic Transform

## 3.1 Introduction to Number Theoretic Transform

The Number Theoretic Transform [4] [20] [30] is an algorithm for performing polynomial (ring) multiplication. Multiplying two polynomials is effectively a convolution between two coefficient vectors. Consider that we take a polynomial a and a polynomial b with coefficients a0, a1, ..., aN , b0, b1, ..., bN . We can define these as a vector a and b so that a[i] = ai and b[i] = bi
. We define a vector c so that:

c[i] =

N

X⁻¹

k=0

ak ∗ bi−k | where bl = 0 for all 0 ≤ l < N | (3.1)

If we now define a polynomial c so that ci = c[i], we see that this polynomial is the product of polynomial multiplication between a and b. We also see that the process for calculating the full multiplication will take N² multiplications.
To reduce the cost of polynomial multiplication, we can use the Discrete Fourier Transform, which has the following property:
FT(c) = FT(a) FT(b) | (3.2)

where is the pointwise multiplication.

Most variants of NTT are almost identical to the Fast Fourier Transform, which is a form of the Fourier Transform that executes quickly (in O(

N
2
| log N) time). The
idea of using the algorithm is thus to transform a polynomial into a form that allows polynomial multiplication to be done as point-wise multiplication, which executes in linear time. Then the result is transformed back into polynomial form. Given that executing the addition of one ai ∗ si secret key to our accumulator requires dr ∗ 2 ∗ dg(= 16) NTT’s, and we perform this step n = 512 times, it is obvious why high performance for the NTT implementation is necessary.
| 21

3. The Number Theoretic Transform


Figure 3.1: Cooley Tukey FFT/NTT butterfly [4]


Figure 3.2: Gentleman Sande FFT/NTT butterfly [4]

### 3.1.1 Mathematics Behind NTT

We can see the NTT as a Discrete Fourier Transform with the twiddle factor changed from a complex number so that ω

N = 1 to a ω ∈ ZQ with again ω n = 1, where ω is
a primitive root of unity (ω

N/2 = −1)
The discrete Fourier is given by the expression ([4], equation 3.1).

Xr =

N

X⁻¹

l=0

xlω

rl | (3.3)

As always, N is our ring size (=1024 for our parameters) and Q is the modulus of the coefficients (= a 27-bit number)). The expression for the NTT is identical, but with ω ∈ Zq. We also define our N-th root of unity as ωN = ω, because as previously mentioned, ω

N
N = 1.

There are now 2 methods that we consider for performing the radix-2 FFT/NTT: The Cooley-Tukey and the Gentleman Sande. We show how these work via two butterfly diagrams (Figure 3.1 and Figure 3.2).

22

3.1. Introduction to Number Theoretic Transform

The Cooley-Tukey Butterfly

First we split equation 3.3 into an even and an odd part:

Xr =

N
2X⁻¹

k=0

x2kω

2rk
N + ω

r
N

N
2X⁻¹

k=0

x2k+1ω

2rk
N | (3.4)

Let us define the following:

Yr =

N
2X⁻¹

k=0

ykω

rk
N
2
, yk = x2k | (3.5)

Zr =

N
2X⁻¹

k=0

zkω

rk
N
2
, zk = x2k+1 | (3.6)

As such we can write the equation as:

Xr = Yr + ω

r
N ∗ Zr | (3.7)

Now we can consider the result of this equation for 2 cases: for the case that r ∈ [0,

N
2 − 1] and r ∈ [

N
2

, N − 1]. In the first case, the equation does not vary, in the

second case, because ω

r+N/2
N = −ω

r
N and because ω

r+N/2
N
2

= ω

r
N
2

so that Yr+N/2 = Yr

and Zr+N/2 = Zr ,we can write the following:

Xr+N/2 = Yr+N/2 + ω

r+N/2
N | ∗ Zr+N/2 = Yr − ω

r
N ∗ Zr | (3.8)

Note that we use ω

2
instead of ω for calculating these NTT’s.

The Gentleman-Sande Butterfly

The Gentleman-Sande works by splitting 3.3 into a first half and second half:

Xr =

N
2X⁻¹

k=0

xkω

rk
N +

N

X⁻¹

k= N
2

ω

rk
N =

N
2X⁻¹

k=0

(xk + xk+ N

2

ω

r

N
2

N )ω

rk
N | (3.9)

For even r = 2 ∗ l, we have ω

r

N
2
N = ω

2∗l∗

N
2
N = 1, so this equation becomes:

X2l =

N
2X⁻¹

k=0

(xl + xl+ N

2

)ω

2kl
N | (3.10)

and for odd r = 2 ∗ l + 1 we have ω

r

N
2
N = ω

(2∗l+1)∗

N
2
N | = −1 so:

X2l+1 =

N
2X⁻¹

k=0

(xl − xl+ N

2

)ω

(2l+1)k
N | (3.11)

23

3. The Number Theoretic Transform

### 3.1.2 The Polynomial Multiplication

To perform the polynomial multiplication, we must not just perform an NTT but also an INTT. Luckily, the INTT is defined as: [4]

Xr = N

−1

N

X⁻¹

l=0

xlω

−rl | (3.12)

Therefore, the INTT can be performed as an NTT by simply changing the ω’s to their inverse and performing multiplication with the modular inverse of N. (N ⁻¹ ∗ N = 1 (mod q)).

Most implementations of NTT result in an output with bit-reversed indices [4]. This means that to find the correct value, it is necessary to take the index of that value, write it in binary form for log2 N, and "flip" this index in such a way that for example 1010000000 become 0000000101. Then we use this flipped index to find the correct value. Indeed, in the PALISADE library’s implementation, the NTT implementation takes a normally-order polynomial and returns a bit-reversed, transformed polynomial. The INTT does the opposite. As such, in the PALISADE library implementation, there is no need for extra steps to undo this bit-reversal.

### 3.1.3 Negative Wrapped Convolution

In a standard polynomial multiplication of two polynomials with ring size N using NTT, we use two polynomials of ring size 2N with half of the inputs being zeros. This way we can do our coefficient-wise multiplication after our NTT, which is followed by a reduction step of the polynomial modulo XN + 1 [30].
There is however an optimisation that can be applied to avoid the reduction step and do the multiplication with polynomials of size N instead. This optimisation is the negative wrapped convolution [30], where we use a ψ so that ψ

2 = ω (mod q),
and we calculate

â = (a[0], a[1] ∗ ψ, a[2] ∗ ψ

2
, ..., a[n − 1] ∗ ψ

n−1
) | (3.13)

and
ˆb = (b[0], b[1] ∗ ψ, b[2] ∗ ψ
2
, ..., b[n − 1] ∗ ψ

n−1
) | (3.14)

We can then calculate

cˆ = INTT(NTT(â) ◦ NTT(

ˆb)) | (3.15)

and it turns out that for

c = a ∗ b (mod XN + 1) | (3.16)

we have
c = (ĉ[0], cˆ[1] ∗ ψ

−1
, cˆ[2] ∗ ψ

−2
, ..., cˆ[n − 1] ∗ ψ
−(n−1)) | (3.17)

24

3.2. Hardware Implementations of NTT

This multiplication with ψ or ψ

−1
can be integrated in our multiplication with the ω factors [30]. How this is done depends on how the algorithm is implemented, and as such, we first have to determine which implementation of NTT to choose from.

## 3.2 Hardware Implementations of NTT

Because the NTT is widely used in cryptographical applications, there are many papers discussing hardware designs of the NTT. As such, there is no point in creating a new NTT hardware accelerator from scratch. Additionally, many hardware papers make their source code available. Table 3.1 lists open-source implementations (in green), but closed source implementations (in red) can also be interesting as they often describe the optimisations that make them successful.

The table was compiled to find the NTT implementation that would best fill the needs of a FHEW hardware accelerator. For each design, it lists the platform on which it was created (we are designing for the UltraScale family, but most should be interchangeable). It also lists either the area the NTT implementation took up or the area the full polynomial multiplication implementation took up. Likewise, the number of clock cycles required to complete either, and the clock frequency are listed. Finally, we list the parameters for which the NTT was designed. The design parameters of our implementation are N = 1024 and Q = 27. NTT implementations that don’t exactly match our modulus size aren’t automatically excluded, as the modulus size is usually parametric, but using a design with a different ring size would be more difficult.

### 3.2.1 NTT Execution Time

The primary purpose of our hardware acceleration is to accelerate. Therefore it is vital that the FHEW is performed faster than the 137 ms currently achieved on an Intel-i7.

The design that stands out for this characteristic is Mert et al.’s [23] parametric NTT implementation, with its 250 clock cycle run-time at 125 MHz for the largest implementation parameters that the paper lists and for the design parameters set that we are targeting. If only one NTT core is used, this means our run time would be (for the 10240 NTT’s that must be executed):

Trun =

250 ∗ 10240
125 ∗ 10⁶
= 20.5ms | (3.18)

This run-time is in the order to be fast enough to justify hardware acceleration. Moreover, the design is highly parametric, so the run-time can be decreased further at the cost of increasing area.

25

# 3. The Number Theoretic Transform Author Year FPGA NTT Area #CC NTT Frequency

c

=

a

b Area #CC

c

=

a

b

### N log2 Q

Oder et al. 2017 Arktix-7 N/A 35840 125 1024 13.6
Roy et al. 2018 UltraScale 87582 200 64K/25K/0.4K/0.2K 5349567 4096 180

Wang et al. 2020 Arktix-7 126 1735/758/6/0 11,455 1024 28.35
Fritzmann et al. 2020 Arktix-7 2908/170/9/0 18537 45.47 36,102 1024 13.6

Roy et al. 2014 Virtex 6 1536/953/1/3 2304 278 512 13.6

Kuo et al. 2017 Artix-7 2832/1381/8/10 2616 131 1024 13.6

Rashmi et al. 2019 Artix-7 0.1 no area for NTT 33792 1024 13.6
Du et al. 2016 Spartan-6 241 251slice/1/4.5 11826 1024 16

Hartshorn et al. 2020 Virtex 7 9233/8585/128/8 1294 179 1936 1024 N/A
Mert et al. 2019 Virtex 7 211.5 1208/556/14/14 7970 1024 32

Mert et al. 2020 Virtex-7 575/0/3/11 5160 125 1024 14

Mert et al. 2020 Virtex-7 2584/0/24/16 680 125 1024 14

Mert et al. 2020 Virtex-7 17188/0/96/48 200 125 1024 14

Mert et al. 2020 Virtex-7 38093/0/224/48 250 125 1024 29

Table 3.1: Hardware implementations of NTT (green is open source, yellow is open source (to be released) and red is closed source)

26

3.2. Hardware Implementations of NTT
Name | Paper | Source
Oder et al. | [28] | [27]
Roy et al. (2018) | [39] | [33]
Wang et al. | [41] | [40]
Fritzmann et al. | [13] | [12]
Roy et al. (2014) | [36] | [34]
Mert et al. | [23] | [22]

Table 3.2: Paper and code Source for the HW implementations

If we used the next fastest implementation instead (Liu et al’s [19], which is closed source), it would take 1294 clock cycles at 179 MHz to perform one NTT. For 10240 NTT’s, this means:

Trun =

1294 ∗ 10240
179 ∗ 10⁶
= 74 ms | (3.19)

If Liu et al’s implementation were to be used, the final execution time would be less than half of simply running FHEW on (unoptimized) software. The reason for this slow execution speed of many NTT implementations is that area is often an important concern. Since the bootstrapping algorithm for FHEW runs on large servers, and any hardware acceleration is likely to be done on large data center accelerator cards, such as the Alveo U280 FPGA, the primary concern when accelerating FHEW is the execution time, not the area taken up by the design.

In our previous calculation, we have assumed all NTT’s are done in series. During FHEW, we are able to perform certain NTT’s (up to 2 INTT’s and 2 ∗ dr(= 8) forward NTT’s) in parallel. Taking full advantage of this with Mert’s implementation would give an execution time of 8.2 ms, which is almost 20 times faster than the 137 ms time on an Intel i7. Moreover, Mert’s design is open source, and the execution time and area listed in Table 3.1 are given for a modulus size close to the one we are targeting.

### 3.2.2 Number of NTT’s per Data Accelerator Card

While the first concern of any hardware acceleration is to accelerate the algorithm in question, it is also important to consider how much area the implementation takes up, because, for small implementations, we can run many instances in parallel. Nonetheless, it is better to have a design that takes up twice as much area but runs twice as fast, than having two designs running in parallel. They both have the same throughput, but the former has a latency that is twice as good as the latter. Therefore, we should only go for a lower area implementation if the area scales down significantly faster than the NTT execution time.
To be able to judge the merits of the different implementations for their use in the

27

3. The Number Theoretic Transform
Resource Name | LUT | FF | DSP | BRAM
Amount | 1304000 | 2607000 | 9024 | 1490

Table 3.3: Resources for the U280

Name | Year | log2 Q | N | Figure Of Merit
Wang | 2020 | 28.35 | 1024 | 12.1
Fritzmann | 2020 | 13.6 | 1024 | 181.8
Roy, Vercauteren | 2014 | 13.6 | 512 | 3.3
Kuo | 2017 | 13.6 | 1024 | 26.8
Hartshorn | 2020 | N/A | 1024 | 20.5
Mert | 2019 | 32 | 1024 | 35.4
Mert | 2020 | 14 | 1024 | 61.0
Mert | 2020 | 14 | 1024 | 11.7
Mert | 2020 | 14 | 1024 | 10.3
Mert | 2020 | 29 | 1024 | 12.9

Table 3.4: FOM’s for the different implementations when considering the U280 as target (lower is better)

Alveo U280, the following figure of merit was devised:

C ∗ maxi(µi)
fc/(200MHz)

(3.20)

Here, C is the number of clock cycles to perform 1 NTT. µi

is the ratio of the
resources one NTT implementation takes up (for example 48 BRAMS), to the total amount of BRAMS available on a U280 (1490 BRAM’s). fc is the clock frequency of the NTT implementation, which is normalized to 200 MHz in our figure of merit. The total amount of resources given in Table 3.3.

Our FOM for the different implementations is then given in Table 3.4. The figure of merit effectively measures how many cycles it would take on average to do 1 NTT if the hardware implementations scaled up perfectly, with the frequency being normalized to 200 MHz to give a fair comparison.A lower FOM is better.
We see that Roy et al’s 2014 NTT implementation scores very well, but this is because it works for only half the ring size. The required area or required number of cycles will more than double with a doubling of the ring size because the NTT is a O(n
2

log n) process. Mert et al’s implementation doesn’t just achieve fast execution but is very area-efficient as well.

## 3.3 Conclusion

As the efficiency of the multiplication is key to the efficiency of the overall hardware implementation, a good understanding of the Number Theoretic Transform and how

28

3.3. Conclusion

it can be used in fast polynomial multiplication is important. Using the information, an NTT hardware implementation that would succeed in accelerating the FHEW accumulation step was chosen, and used in our hardware implementation.

29

# Chapter 4

# Hardware Implementation

The current FHEW (software) implementation provided in the PALISADE library can execute one binary gate in approximately 140 ms [24]. For many applications, 7 binary gates per second is too slow to be practical, especially when an entire CPU must be dedicated to one binary gate. In comparison, ENIAC, a very early digital computer built in 1945, could do 5000 additions or subtractions per second [16]. This motivates the hardware acceleration done in this thesis.

## 4.1 Hardware Acceleration

Hardware Acceleration is the creation or modification of a special-purpose circuit for the purpose of reducing the execution time of a given algorithm. The special-purpose circuit used in this thesis is an FPGA. We target Xilinx’s Zynq Ultrascale+ FPGA found on Xilinx’s ZCU102 Development Board. The algorithm we specifically accelerate in hardware is the accumulation step given by Algorithm 2. The rest of the FHEW scheme is then performed in "software". Just as the exact "hardware" targeted differs on the device, so does the "software". On the ZCU102, the "software" runs on the Arm Cortex-A53.

### 4.1.1 Hardware Acceleration Device Choice

The device targeted for this thesis was the ZCU102 prototype board, although an Alveo U280 data center accelerator card would be more suitable for applications using FHEW. The former was chosen because it simplified design and implementation. The ZCU102 is powerful enough to allow for a significant, almost 8-fold, speed-up of the accumulation algorithm. However, this requires a fast DDR4 (memory) interface to provide the bootstrapping key (which is the RGSW encryption of the secret key) in time with the hardware implementation. The latter was not implemented in this thesis as the focus lay on creating the general processing logic rather than a memory interface for a specific device.

31

4. Hardware Implementation

### 4.1.2 Hardware and Software

As mentioned in Chapter 1, the bootstrapping step takes up 137 ms on an "Intel(R) Core(TM) i7-9700 CPU @ 3.00GHz and 64 GB of RAM, running Ubuntu 18.04 LTS" [24]. The second most computationally intensive step (i.e., the step which takes the second most execution time for our purposes) is the key-switching step, which takes slightly less than 1 ms on the same processor. For this reason, we focus on the hardware acceleration of the bootstrapping only. In fact, we don’t accelerate the full bootstrapping process, but only the accumulation step, as the initialisation step and extraction step take up a negligible amount of execution time [24].

To understand our hardware implementation, it is easier to consider the PAL-ISADE source code [5], which we have written in pseudo-code in Algorithm 3, rather than Algorithm 2 [24]. Algorithm 2 is the more abstract accumulation algorithm found in Micciancio et al.’s paper comparing FHEW and TFHE [24].

## 4.2 An Overview of the Hardware Implementation

We now consider Algorithm 3, which is also described in flow chart form in Appendix
A. We can split the flow of the algorithm into 2 parts: the outer RLWE loop (lines 1-5 in Algorithm 3), and the inner RGSW loop (lines 6-22).

### 4.2.1 The Outer Control Loop

The outer LWE loop is fairly trivial to implement in hardware, and one modular subtraction (see line 4 in Algorithm 3) is computed in software for 1024 values. From both an area and performance perspective, it makes barely any difference whether one sends the n(= 512) values of a (each log2

(q)(= 9) bits) to the accelerator core, or the n ∗ dr values of cj (line 4) (each log2

(Br) = log2

(23) = 5 bits). These values are thus calculated in advance, and will only be used for determining which part of the bootstrapping key is used to rotate the RGSW Accumulator.

### 4.2.2 The Inner Control Loop

The most performance-sensitive part of the algorithm lies in the inner control loop (lines 6-22). The inner loop can be broken up into 4 parts: two INTT’s (line 7), Signed Digit Decomposition (line 8), eight (= 2 ∗ dg) NTT’s (line 10) and RGSW bootstrapping key multiplication (line 17).

Counter-intuitively, the INTT is performed first. The reason for this is that we start with an accumulator on which the NTT has already been performed. We start this way because we wish to begin and end with ciphertext that allows for easy polynomial multiplication ("EVALUATION" state in the PALISADE library). After performing this INTT to bring the accumulator back to the "normal" state("COEFFICIENT"

32

4.2. An Overview of the Hardware Implementation

Algorithm 3: Accumulation described in Algorithm 2 from an implementation perspective
Note: This describes the full algorithm, and is equal to Algorithm 2 being executed n (= 512) times
Data: ACC, made up of 2 vectors size N, secretKey, an array of drBr ∗ 2 ∗ (2dg) values, a = {a0, a1, ..., an−1}
Result: ACC, updated with ai ∗ si for i = 0...n − 1

### 1 begin 2 for i = 0, 1, ...n − 1 do 3 for j = 0, 1, ... logBr

(q) − 1 do

### 4 cj = bai/Bj

r

c mod B;

### 5 if cj > 0 then 6 for k = 0, 1 do

7 CoefACC[k] = INTT(ACC[k]);
8 {dcmp[k][dg],.., dcmp[k][1], dcmp[k][0]} = SignedDigitDecompose(CoefACC[k]);

### 9 for l = 0, 1, ...dg do

10 evalACC[k][l] = NTT(dcmp[k][l]);

### 11 end 12 end 13 for k = 0, 1 do

14 ACC[k] = 0;

### 15 for l = 0, 1, ...dg − 1 do 16 for m = 0, 1 do 17 secretProduct = evalACC[m][l] *

secretKey[k][l][m];
18 ACC[k] = ACC[k] + secretProduct;

### 19 end 20 end 21 end 22 end 23 end 24 end

25 Return ACC;

### 26 end

33

4. Hardware Implementation

state in the PALISADE library), we perform the signed digit decompose (see Algorithm 4). This is a simple algorithm that breaks the values of the Accumulator into values between [−Bg/2, Bg/2). This creates 2 ∗ dg = 2 ∗ logBg

(Q) = 2 ∗ 4 polynomials.
Doing our bootstrapping key multiplication in this fashion decreases the noise growth [24], as shown in Chapter 2. Thirdly, an NTT is performed to bring the polynomials back to the "EVALUATION" form. This allows us to in the last step multiply with the bootstrapping key, resulting in 2 ∗ 2 ∗ dg = (16) multiplications, and 2 ∗ dg additions for each new RGSW part, for a total of 2 ∗ 2 ∗ dg = 16 additions. (See Appendix A and lines 16-19 in Algorithm 3).

Algorithm 4: Signed Digit Decompose
Data: CoefACC, a vector of size N
Result: dcmp[dg], ..., dcmp[1], dcmp[0], which is the signed decomposition of each value in CoefACC

### 1 begin 2 for i = 0, 1, ...N − 1 do

### 3 if CoefACC[i] ≥ Q/2 then

4 d = CoefACC[i] − Q ;

### 5 end 6 else

7 d = CoefACC[i];

### 8 end 9 for j = 0, 1, ...dr do

10 r = d (mod B)g;

### 11 if r ≥ Bg/2 then

12 r = r − Bg ;

### 13 end

14 d = d − r;
15 d = bd/Brc;

### 16 if r ≥ 0 then

17 dcmp[j] = r ;

### 18 end 19 else

20 dcmp[j] = Q − r ;

### 21 end 22 end 23 end

24 Return ACC;

### 25 end

34

4.3. Mert et al.’s NTT Implementation


Figure 4.1: Diagram of the RGSW accumulator implementation

## 4.3 Mert et al.’s NTT Implementation

### 4.3.1 Implementation Advantages and Disadvantages

To the best of our knowledge, Mert et al.’s design is the only open-source hardware implementation with high enough performance for the FHEW implementation (see Chapter 3). It can provide this because the design is customizable with a parameter set. In other words, if required, one could also create a very low-area implementation using the exact same implementation. However, this comes at a flexibility cost: only the Gentleman Sande version of the NTT algorithm is implemented [11], with outputs using bit-reversed indices compared to the inputs (see Chapter 3). This means that the resulting coefficients of the NTT should be re-organized in memory before they can be used in the following INTT operation. Note that the reorganization in memory (=an index bit-reversal step), is costly in software, and is also difficult to achieve efficiently in hardware, especially when the coefficients are contained in multiple, separate, BRAMs with single read/write ports for each BRAM.

A second disadvantage of Mert et al’s design is that there is no support for the negatively wrapped convolution described in Chapter 3. Thirdly, there is only one Q (= 27)-bit input port to the NTT module and Q (= 27)-bit output port. So, while the NTT (or INTT) is executed in 250 clock cycles, it takes N(= 1024) cycles to

35

4. Hardware Implementation


Figure 4.2: Mert et al.’s datapath [23]

load values into the BRAMs and N(= 1024) cycles to output. Using Mert et al’s design without modification would result in a 2250 CC execution time, where most of the time is spent on data transfers rather than calculations.

Finally, under the original design, the values would have to be output after executing every NTT or INTT, then placed back into the design, each step taking N clock cycles. The reason for this is that the output coefficients and input coefficients are stored in a different manner in the BRAMs. How the storage of inputs and outputs differs is explained in detail later.

### 4.3.2 Implementation Details

Before continuing to discuss this implementation, the basics of Mert et al.’s design must be considered. It allows for 3 parameters to be set:

- Ring Size N = 1024
- Modulus Size Q < 2

27

- Processing Elements P E = 32

The ring size and modulus size are found in the parameter set STD128 (see Table 2.5). The number of processing elements determines the speed and (to a degree) the area of the design.

For the purpose of this implementation, we chose a PE number of 32, but we kept everything parametric to the greatest extent possible. In hindsight, it would have been slightly more optimal to have chosen a PE number of 16 for the ZCU102 (with a PE number of 32, the design cannot fully fit on the ZCU102) and a PE number of 64 or higher for the U280. The number of 32 was chosen because it was the largest parameter set mentioned in [23].

For each PE element, there are 2 BRAMs to store the coefficients which will go through the GS datapath, and 1 BRAM to hold the twiddle factors (Figure 4.2).

36

4.4. Leveraging the NTT for FHEW


Figure 4.3: Mert et al.’s implementation of GS NTT and INTT for a ring size N of 8

Under the original design, the twiddle factors have to be loaded in at runtime as well, but to reduce the complexity of interfacing, and to save some area, the BRAMs for the twiddle factors were implemented as ROMs, the content of which is initialized at design time.

As we have 64 BRAMs for storing the coefficients for each NTT accelerator, there are logically N/(2 ∗ P E) = 16 values in each (coefficient) BRAM at the start of the execution. The Gentleman-Sande NTT algorithm has multiple stages (log2 N = 10 )[30]. After each stage, the values must be written back to new BRAMs, as a PE block can only use the 2 BRAMs adjacent to it to calculate the results for a given stage.

A stage is the execution of one butterfly on every pair of elements in the polynomial. In Figure 4.3, we can see an example of log2

(N) =3 stages with a ring size of N = 8. The twiddle factors which are used in the original multiplier are given by:

ω

2

(stage)∗k
(4.1)

with k being a counter modulo 2

(2−stage)

## 4.4 Leveraging the NTT for FHEW

Now that we have seen what Mert et al.’s design provides, we will discuss how we modified this design to support FHEW. These modifications can be split into three logical parts: the modification of the GS INTT to support negatively wrapped convolution and index bit-reversal, the modification of Mert et al.’s GS design into a CT design, and the integration of the bootstrapping key multiplication into this CT

37

4. Hardware Implementation


Figure 4.4: Poppelmann et al.’s representation of the GS and CT NTT [30]

design.

Note that these modifications are done for two reasons: Firstly, Mert et Al.’s design does not support the execution of more than one NTT or INTT by itself. Secondly, naive modifications to extend this support would be very inefficient, as noted in the previous section.
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

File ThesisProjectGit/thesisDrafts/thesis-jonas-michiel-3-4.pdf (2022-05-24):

Jonas Bertels; Thesis supervisor:; Mentors:; Academic year 2020 – 2021

Fastest Homomorphic Encryption in the
West Made Faster

Thesis submitted for the degree of

Master of Science in

Electrical Engineering, option
Electronics and Chip Design

Prof. dr. ir. Ingrid Verbauwhede

Ir. Michiel Van Beirendonck

Ir. Furkan Turan

Ir. Jose Maria Bermudo Mera
Ir. Angshuman Karmakar

© Copyright KU Leuven

Without written permission of the thesis supervisor and the author it is forbidden to reproduce or adapt in any form or by any means any part of this publication. Requests for obtaining the right to reproduce or utilize parts of this publication should be addressed to Departement Elektrotechniek, Kasteelpark Arenberg 10 postbus 2440, B-3001 Heverlee, +32-16-321130 or by email info@esat.kuleuven.be.
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

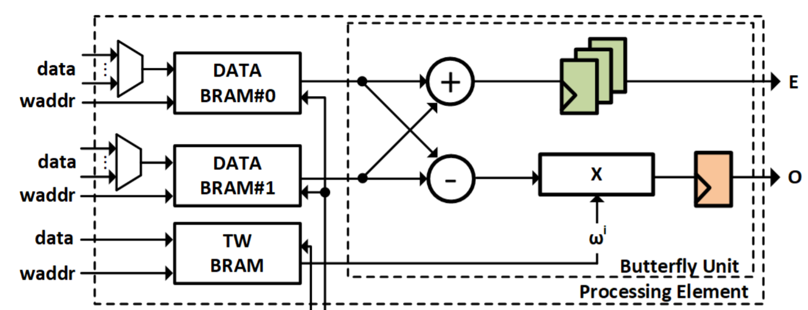
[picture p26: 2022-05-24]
ThesisProjectGit/Papers/graphicsDM/MertDatapath.PNG

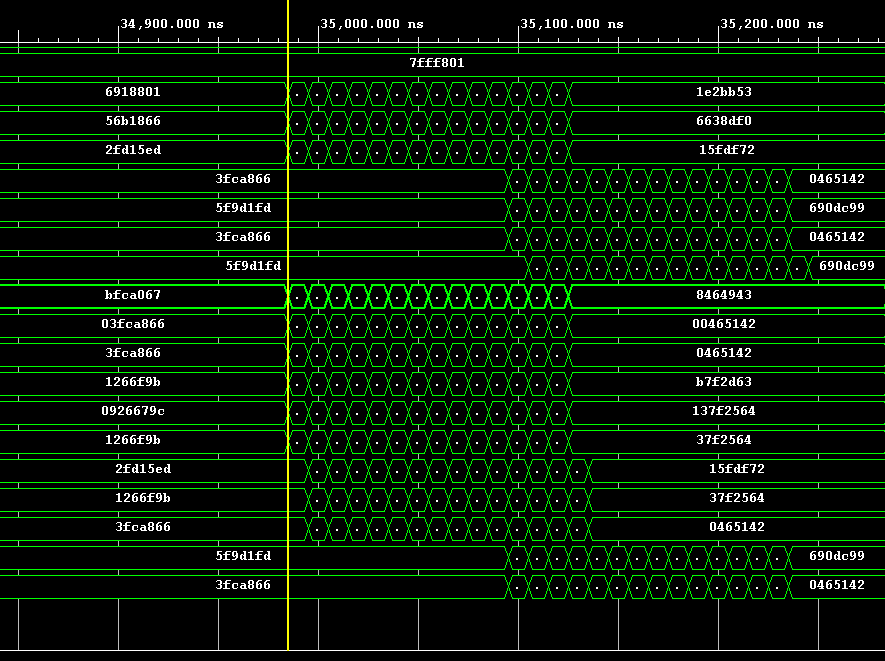
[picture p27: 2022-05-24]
ThesisProjectGit/waveForms/NTT2.PNG

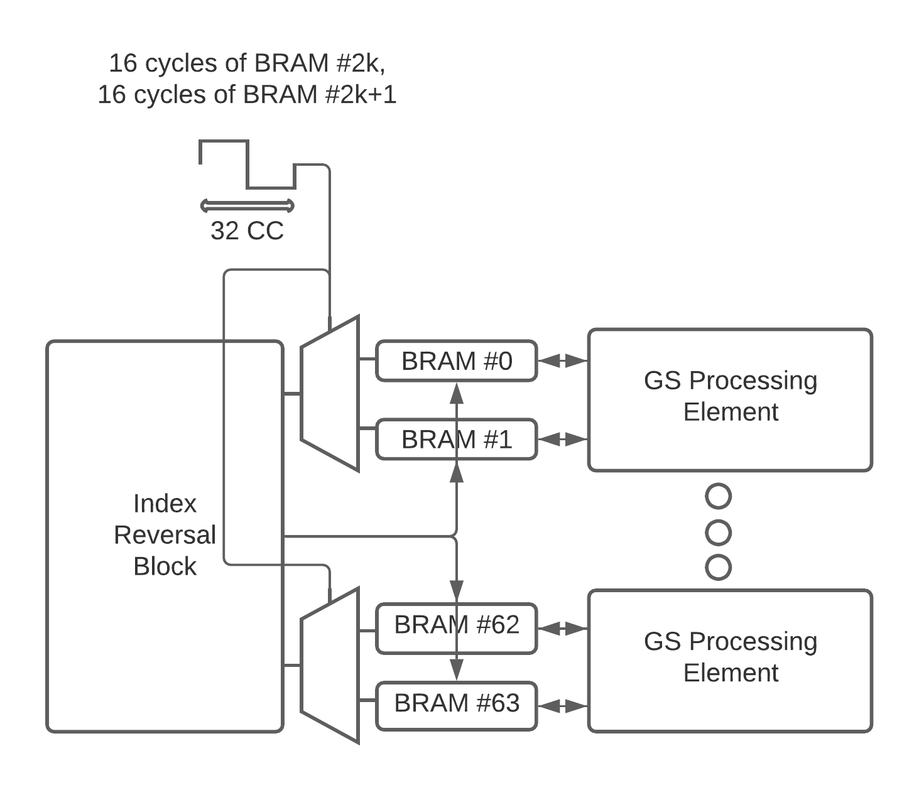
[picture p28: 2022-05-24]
ThesisProjectGit/Papers/graphicsDM/GSINTTLatex.png

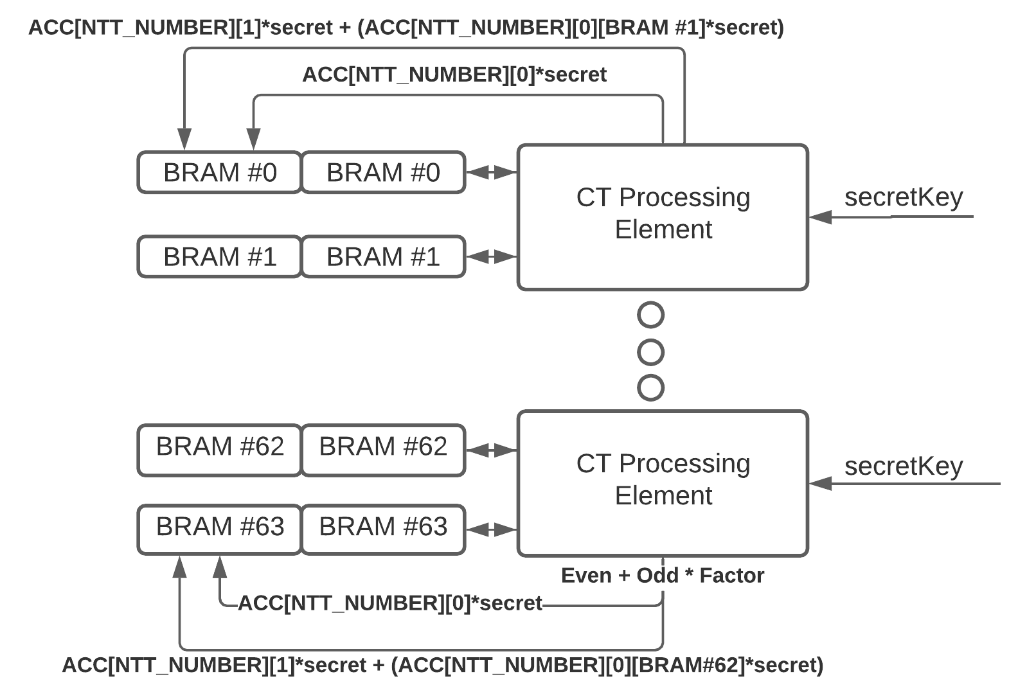
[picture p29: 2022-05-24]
ThesisProjectGit/Papers/graphicsDM/CTNTT_LATEX.png

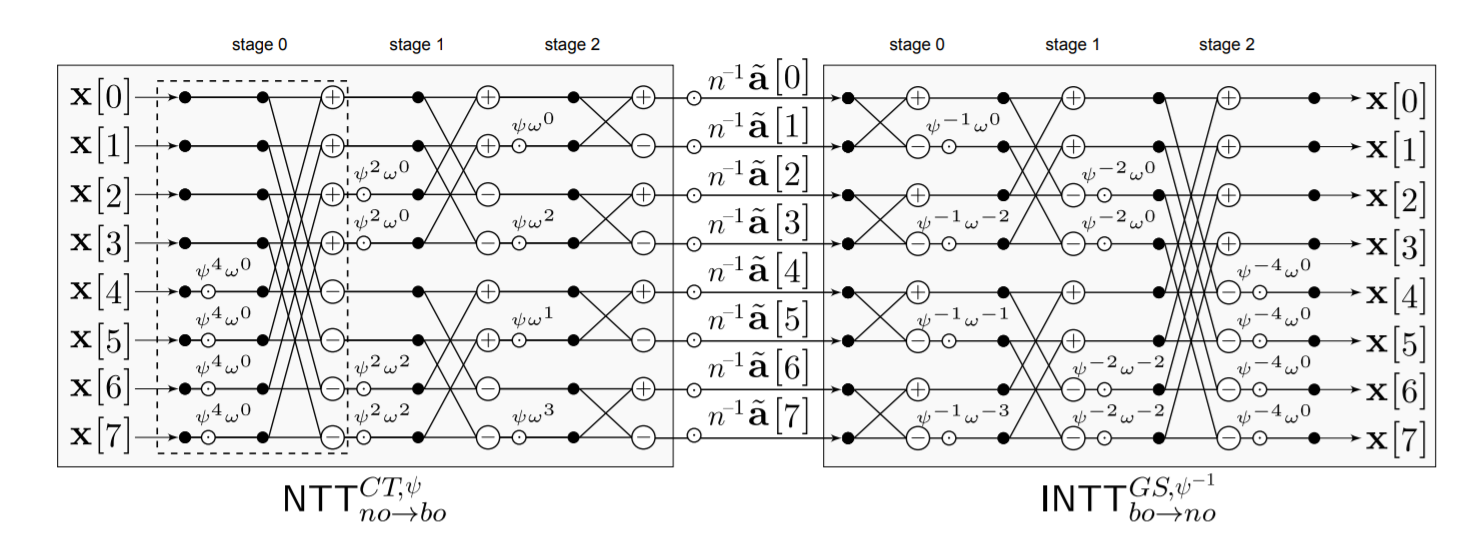
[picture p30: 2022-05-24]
ThesisProjectGit/Papers/graphicsDM/PoppelmannNTT.PNG

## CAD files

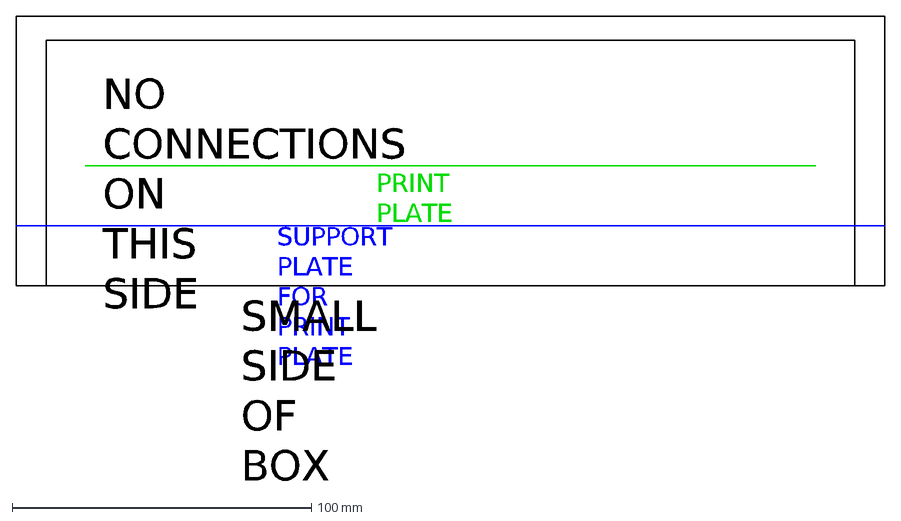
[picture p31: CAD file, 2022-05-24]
ThesisProjectGit/TechnicalIssueScreenshots/SmallSideDrawingAndHeightPrintPlate.dxf
SUPPORT PLATE FOR PRINT PLATE
SMALL SIDE OF BOX
PRINT PLATE
NO CONNECTIONS ON THIS SIDE

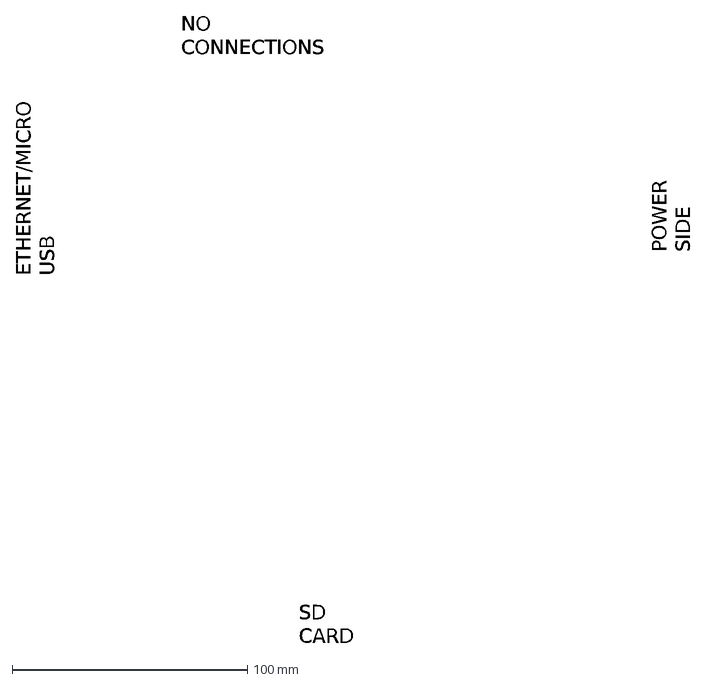
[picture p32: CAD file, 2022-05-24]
ThesisProjectGit/TechnicalIssueScreenshots/drawing.dxf
POWER SIDE
ETHERNET/MICRO USB
NO CONNECTIONS
SD CARD

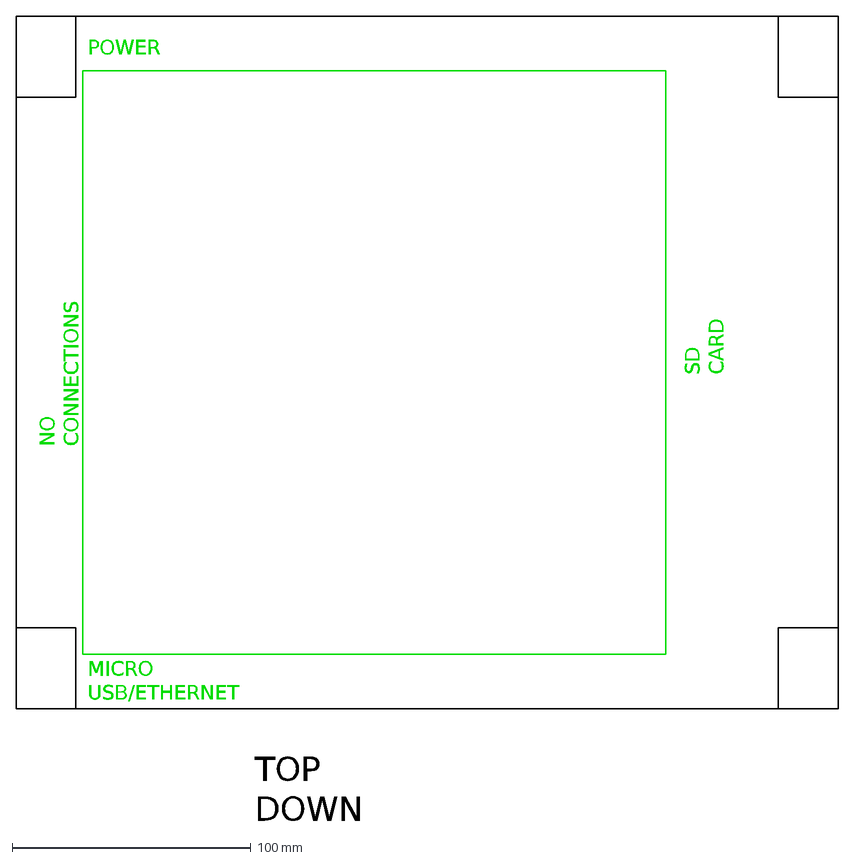
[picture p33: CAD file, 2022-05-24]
ThesisProjectGit/TechnicalIssueScreenshots/topDownDrawing.dxf
TOP DOWN
MICRO USB/ETHERNET
POWER
NO CONNECTIONS
SD CARD

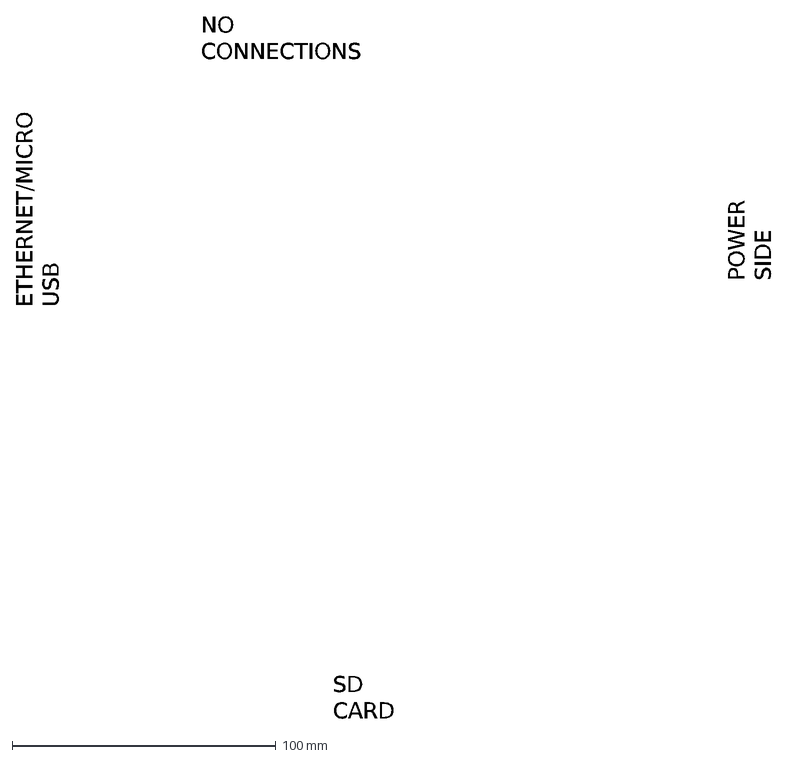
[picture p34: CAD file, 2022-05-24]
ThesisProjectGit/TechnicalIssueScreenshots/UndersideAttachmentToBox.dxf
POWER SIDE
ETHERNET/MICRO USB
NO CONNECTIONS
SD CARD

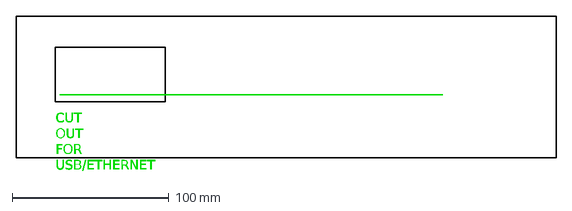
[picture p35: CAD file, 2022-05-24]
ThesisProjectGit/TechnicalIssueScreenshots/USBEthernetSide.dxf
CUT OUT FOR USB/ETHERNET

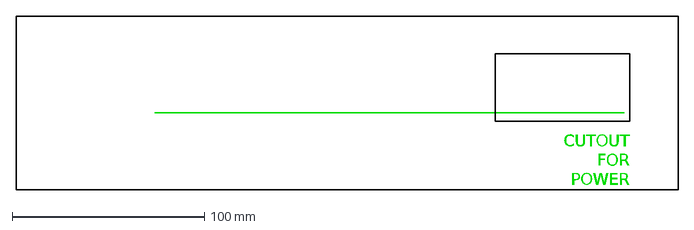
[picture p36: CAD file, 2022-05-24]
ThesisProjectGit/TechnicalIssueScreenshots/PowerSide.dxf
CUTOUT FOR POWER

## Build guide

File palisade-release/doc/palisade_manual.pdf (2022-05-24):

# PALISADE Lattice Cryptography Library User Manual (v1.10.5)

### Yuriy Polyakov¹,2, Kurt Rohloff¹,2, Gerard W. Ryan²

### , and Dave Cousins¹,2

1Duality Technologies, Newark, NJ, 07102, USA.

### {ypolyakov,krohloff,dcousins}@dualitytech.com

2Cybersecurity Research Center, New Jersey Institute of Technology (NJIT),

### Newark, NJ, 07102, USA. {polyakov,rohloff,dcousins}@njit.edu

### October 1, 2020

Abstract

This document is the manual for the PALISADE lattice cryptography library. This manual provides an introduction to the library by describing the library architecture and cataloging its capabilities. We focus on the PALISADE library’s ability to support homomorphic encryption capabilities to evaluate arithmetic operations on data while encrypted. We do not explicitly provide an introduction to lattice cryptography, but we provide an overview of notation and terminology necessary to use the PALISADE library. In addition to providing code samples for the use of the PALISADE library, we also discuss the library programming style for developers who wish to read library code or even add to the library. We also provide an overview of common pitfalls in the use of PALISADE.

## Contents

1 Document Overview | 5
2 Introduction | 6
3 A Brief Overview of Lattice Cryptography | 8
4 Library Architecture | 10
5 Capabilities | 13
6 PALISADE Directory Structure | 20
7 Terminology and Notation | 22
8 Sample Implementations: PKE Module | 31

8.4 Decryption | | 40
8.5 Re-Encryption | | 41
8.6 Serialization and Deserialization | | 42
8.7 Homomorphic Addition of Ciphertexts | | 43
8.8 Homomorphic Multiplication of Ciphertexts | | 45
9 Sample Implementations: FHE | 47
9.1 Integer arithmetic | | 47
9.2 Real-number arithmetic | | 47
9.3 Boolean Circuit Arithmetic | | 49
10 Sample Implementations: ABE | 50
10.1 Creating an ABEContext | | 50
10.2 Generating Master Keys | | 50
10.3 Creating Access Policies | | 50
10.4 Key Generation | | 51
10.5 Encryption | | 52
10.6 Decryption | | 52
11 Sample Implementations: Digital Signature | 53
11.1 Creating a SignatureContext | | 53
11.2 Key Generation | | 53
11.3 Signing | | 53
11.4 Verification | | 54
12 Building and Installing PALISADE | 55
13 Programming Style | 56
Appendix A PALISADE License | 57
Appendix B Support | 58

## Listings

1 | Directory structure for PALISADE source code | | 20
2 | Values in Plaintext | | 26
3 | Creating a CryptoContext with parameters | | 32
4 | Creating a CryptoContext with parameter generation | | 34
5 | Creating a preconfigured CryptoContext | | 34
6 | Creating a CryptoContext using standard paranerers | | 36
7 | Creating a CryptoContext from a serialization | | 36
8 | Creating a Scalar Plaintext | | 37
9 | Creating an Integer Plaintext | | 37
10 | Creating a Fractional Plaintext | | 38

11 | Creating a CoefPackedEncoding Plaintext | | 38
12 | Creating a PackedEncoding Plaintext | | 39
13 | Creating a CKKSPackedEncoding Plaintext | | 39
14 | Creating a String Plaintext | | 39
15 | Encrypting | | 40
16 | Decrypting | | 40
17 | Re-Encrypting | | 42
18 | Adding Ciphertexts | | 44
19 | Multiplying Ciphertexts | | 46
20 | List of arguments of CKKS context generation method | | 48
21 | Creating a CKKS plaintext | | 48
22 | Creating a ABEContext with Security Level | | 50
23 | Creating a ABEContext with Parameters | | 50
24 | Generating Master Public Key Pair with ABEContext | | 50
25 | Creating a User Identifier with GPV IBE ABEContext | | 51
26 | Creating a User Attribute Set/Access Policy with CP-ABE ABEContext . . | 51
27 | Generating a Secret Key with ABEContext | | 51
28 | Generating a Secret Key with ABEContext (Offline Phase - Perturbation Gen-
| eration) | | 51
29 | Generating a Secret Key with ABEContext (Online Phase - Key Generation) | 52
30 | Encryption with CP-ABE ABEContext | | 52
31 | Decryption with CP-ABE ABEContext | | 52
32 | Decryption with GPV IBE ABEContext | | 53
33 | Creating a SignatureContext with Parameters | | 53
34 | Key Generation with SignatureContext | | 53
35 | Signing with SignatureContext | | 54
36 | Signing with SignatureContext (Offline Phase - Perturbation Generation) . . | 54
37 | Signing with SignatureContext (Online Phase - Signing) | | 54
38 | Verification with SignatureContext | | 55

## 1 Document Overview

This manuscript is a working document to introduce users to the PALISADE lattice cryptography library. The most recent copy of this document is available for download from the PALISADE library website. (https://palisade-crypto.org) Copies of this document may be available for download from PALISADE contributors’ websites, but the version available for download on the PALISADE library website should be considered authoritative.

The manual is organized as follows;

- An introduction to the library is provided in Section 2.
- Section 3 provides a basic introduction to lattice cryptography.
- The library architecture is discussed in Section 4.
- The library capabilities are discussed in Section 5.
- Section 6 provides an overview of the PALISADE library directory structure.
- Section 7 provides an overview of notation and terminology used in the library and this manual.
- Section 8 provides codes samples for the Public Key Encryption (PKE) module.
- Section 9 provides codes samples covering FHE for integer arithmetic, real-number arithmetic, and Boolean circuits.
- Section 10 provides codes samples for Attribute-based Encryption (ABE).
- Section 11 provides codes samples for Digital Signatures (Signature).
- Section 12 describes how to build the library in a generic Linux environment.
- Section 13 describes the programming style we maintain in the library for those users who wish to contribute code to the library.

In addition, we provide the following appendices:

- Appendix A reproduces the library’s BSD 2-clause license.
- The PALISADE library has been made possible by the generous support of our sponsors. A listing of the PALISADE library sponsors can been seen in Appendix B.

The public version of the PALISADE Lattice Cryptography library can be found on The PALISADE Git Repository. (https://gitlab.com/palisade/palisade-release)

The listed authors of this document are the current primary maintainers of the PALISADE library repository.

## 2 Introduction

Lattice cryptography has received considerable attention because of its capability to support both post-quantum public-key encryption and the ability to compute on data while encrypted via homomorphic encryption. Lattice cryptography also provides other powerful capabilities such as proxy re-encryption and attribute-based encryption. The PALISADE library provides implementations of the building blocks for lattice cryptography capabilities along with end-to-end implementations of advanced lattice cryptography protocols for public-key encryption, proxy re-encryption, homomorphic encryption and others. PALISADE provides both an experimental platform for researchers to design and evaluate new lattice cryptography capabilities, while at the same time providing implementations of known protocols that can be integrated into applications. In this manual we describe PALISADE and discuss how it can be used.

The PALISADE library is designed to address the following inherent challenges of lattice cryptography implementation:

- The complexity of algebraic constructions makes it hard for non-experts to leverage, let alone implement, algebraic constructions used as the building blocks of lattice cryptography.
- Lattice cryptography implementations are often purpose-built. Rapid deployment on new hardware systems is difficult to support with these existing implementations.
- Parameter selection for security and performance takes very sophisticated understanding, and this is nontrivial even for experts - up to a dozen parameters may be needed to be set for some schemes.
- Security assumptions are evolving, and it has been difficult to adapt prior implementations. See for example the recent sub-field lattice attacks against LTV which required re-design of libraries that previously used this scheme.
- Application integration has been challenging, without easy methods to efficiently perform operations on non-trivial data types, such as rationals, complex numbers, etc.

As a result of these identified challenges, we design PALISADE to achieve the following design goals:

- Create an extensible and adaptable library for lattice cryptography. Lattice crypto uses several computational primitives. We allow for new protocols that mix-and-match these primitives to avoid the need for expert low-level knowledge. This has been a major advance in the PALISADE library, and we are still refining these features of PALISADE as we support more capabilities.
- Provide a modular structure to mix and match components. This allows for systemoptimized arithmetic and lattice “back-ends”/plugins. We currently support multiple implementations of big integer math that have various performance trade offs and bit length limitations. Multiple sets of math back-ends can be selected at compile time. The PALISADE library is thus designed to be highly portable into commodity computing and hardware environments, including Windows, Linux, MacOS and Android environments (though Android it experimental). The ability to support multiple hardware accelerators is a work in progress in PALISADE.
- Offer (semi-)automated parameter selection. This reduces the need to tune an overwhelming number of parameters. This is still a major research topic and is a work in progress in PALISADE.
- Develop common crypto APIs. Common crypto APIs across multiple schemes and back-ends “hide” complex details of lattice constructions / parameterization from application developers, allowing developers to focus on their areas of interest while integrating and replacing components to maintain security and performance. This is another major feature of PALISADE that we continue to refine.
- Deliver good software engineering with focus on usability. This permits standardsbased design and style. Unit tests and bench-marking environments are supported for evaluation and tuning of integrated applications. We aim to provide documentation, clean code and useful examples that reduce effort for new developers.

Our identification of these goals in PALISADE is informed by industry experience integrating PALISADE into multi-organizational large software engineering projects. As a result of these identified challenges and the resulting engineering goals we set for ourselves in the design of PALISADE, we designed PALISADE to be highly modular, with a core library of lattice cryptography primitives that support multiple protocols for public-key encryption, homomorphic encryption, digital signature schemes, proxy re-encryption and program obfuscation.

## 3 A Brief Overview of Lattice Cryptography

In the following discussion, objects and functions that are directly supported by PALISADE are printed in this type.

At a high intuitive level, encryption is a computational process wherein Data is Encoded as Plaintext and then encrypted into Ciphertext according to some Encryption algorithm. Conversely, Decryption is a corresponding computational process wherein the Plaintext can be recovered from the Ciphertext through the use of a corresponding Decryption algorithm.

These algorithms use cryptographic Keys to perform the Encryption and Decryption operations. Intuitively, an encryption scheme is secure if it prevents an adversary from recovering Plaintext (or information about a Plaintext) from Ciphertext when the adversary does not have the corresponding decryption key.

A “symmetric key” protocol uses the same key to perform both encryption and decryption. A “public key” or “assymmetric” protocol uses a pair of Public and Secret keys, respectively, for encryption and decryption. A Secret key is sometimes called a Private
key .

In practice symmetric keys and secret keys are kept secret because they can be used to access protected information. Public keys are often widely distributed and often published on the open Internet. The intended use of a public key is that one can encrypt data with a downloaded public key corresponding to an intended recipient, encrypt sensitive information for the recipient with the public key, and send that encrypted sensitive information to the recipient. The recipient can use her secret key to decrypt and recover the protected information encoded in the plaintext.

Cryptographic algorithms are designed around computational hardness assumptions so that the difficulty of recovering information about plaintext is at least as hard as some provable computationally hard problem. Thus, it is theoretically possible to break such a system, but it is assumed infeasible to do so by any known practical means. Different computationally hard problems define different classes of encryption systems. PALISADE focuses on lattice-based cryptography. The security of lattice cryptography is based on the hardness of variants of the Shortest Vector Problem (SVP), Learning With Errors (LWE), and other hard problems. Lattice cryptography has both symmetric and public key variants, but we generally focus on the public key lattice cryptography variants in the PALISADE library and this manual.

Homomorphic Encryption (HE) or Fully Homomorphic Encryption (FHE) refer to a class of encryption methods envisioned by Rivest, Adleman, and Dertouzos in 1978. HE differs from basic encryption methods in that it allows computation to be performed directly on encrypted data without requiring access to a secret key. The result of such a computation remains in an encrypted form, and can at a later point be revealed by the owner of the secret key by decrypting the result.

In 2009 Craig Gentry showed the existence of lattice-based FHE capabilities. Since this initial discovery of a lattice-based FHE protocol, there has been a Renaissance in lattice cryptography, with the discovery of several other increasingly practical HE schemes and variations of HE protocols. Some of the common HE schemes include the Brakerski-Fan-Vercauteren (BFV)

1
, Brakerski-Gentry-Vaikuntanathan (BGV), Cheon-Kim-Kim-Song (CKKS), FHEW, TFHE and Stehle-Steinfeld (StSt) schemes. Other related protocols include:
- Proxy Re-Encryption (PRE), which permits delegation of ciphertext decryption, thus allowing a host to delegate access to encrypted data.
- Somewhat Homomomorphic Encryption (SHE), which permits a limited amount of computation on encrypted data.
- Leveled Somewhat Homomorphic Encryption (Leveled SHE), which permits at least a fixed depth of computation to be performed on encrypted data by using a decreasing ladder (set) of ciphertext moduli.
- Multiparty Homomorphic Encryption, which enables multiple participants to contribute data to a joint computation, without sharing access to the actual data.

The public version of PALISADE supports all of the protocols discussed above, and we are in the process of adding support for more protocols and schemes. From v1.4 and onwards, PALISADE also supports a selection of trapdoor-based schemes: a Gentry-Peikert-Vaikuntanathan (GPV) digital signature scheme, a GPV identity-based encryption (IBE) scheme, and a Zhang-Zhang ciphertext-policy attribute-based encryption (CP-ABE) scheme.

An inherent property of encrypted computing technologies, including the various protocols supported by PALISADE, is that computing on encrypted data is significantly slower and more compute-intensive than computing on plaintext data. As such, debugging the applications of encrypted computing technologies can be a frustrating, slow process. To aid developers in integrating PALISADE implementations of encrypted computing technoligies, we also provide in PALISADE a “Null” scheme which supports the same API as the BFV, BGV, and StSt implementations, but which does not encrypt data and performs all operations on unencrypted plaintext. The Null scheme implementation operates as a light-duty no-security equivalent of the encrypted computing protocols supported by PALISADE. We provide the Null scheme so developers can test the correctness their PALISADE program more easily without the overhead or frustration of testing operations with slower more compute-intensive workloads engendered by encrypted computing capabilities.

1This scheme is also frequently denoted as the FV scheme, but we choose to call it the BFV scheme.

## 4 Library Architecture

The PALISADE library implements lattice cryptography in C++. The objects that are created by and manipulated within PALISADE are instances of C++ classes.

PALISADE is designed as a layered architecture where each layer provides a set of services to the layer “above” it in the stack, and makes use of services in the layer “below” it in the stack. The interfaces between each of the layers are designed to implement a common API. This permits substituting multiple implementations at any layer for experimental purposes.

The high-level architecture of PALISADE is illustrated in Figure 1.

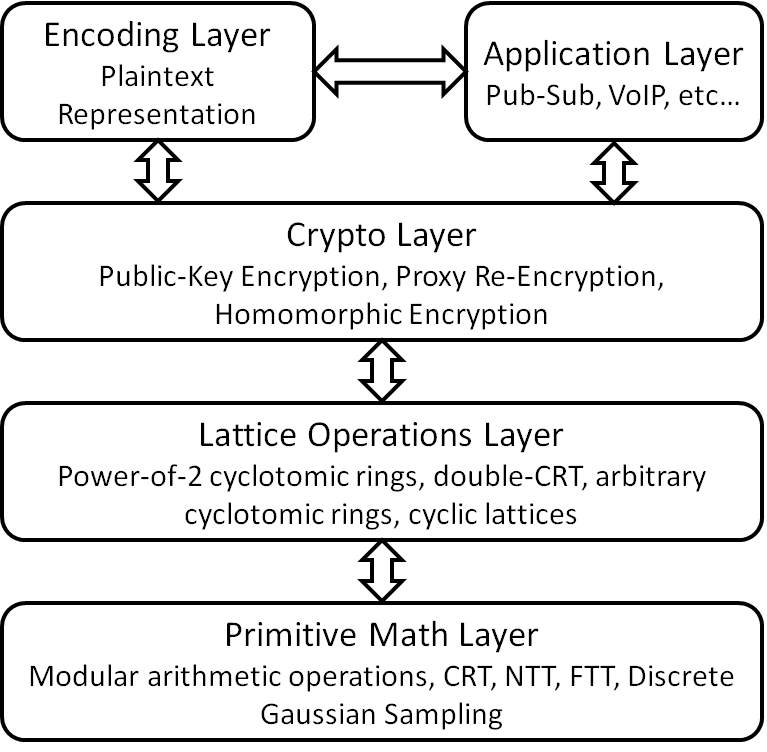
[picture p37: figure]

Figure 1: High-level PALISADE architecture

The layers in PALISADE are as follows:

1. Application: All programs that call the PALISADE library services are in this layer.
2. Encoding: All implementations of methods to encode data are at this layer.
3. Crypto: All implementation of cryptographic protocols are at this layer.
4. Lattice Operations: All higher-level lattice-crypto mathematical building blocks are in this layer.
5. Primitive Math: All low-level generic mathematical operations, such as multi-precision arithmetic implementations, are at this layer.

### 4.1 Application Layer

All programs that make use of the PALISADE library are said to be in the Application layer.

All programs at the Application layer make calls to services exposed in the PALISADE Crypto layer to gain access to PALISADE lattice cryptography functionality. The Application layer also makes use of service at the Encoding layer.

### 4.2 Encoding Layer

The Encoding layer contains all classes needed to provide for the encoding of any supported raw plaintext message data into a Plaintext object, and for decoding back to raw plaintext messages whenever necessary.

The Encoding layer is used to create Plaintext objects. These objects are sometimes created at the request of the Application layer, in which case Crypto layer methods act as a proxy for the Application layer, sometimes at the request of the Crypto layer itself. The interface for Encoding functionality is C++ methods provided by Plaintext.

### 4.3 Crypto Layer

The Crypto layer contains all classes needed to provide all available lattice cryptography functionality for specific cryptographic protocols such as public-key encryption, PRE and SHE schemes, and all included methods such as encryption and decryption, proxy re-encryption and container classes for parameters specific to those schemes.

The interface for Crypto functionality is C++ methods provided by CryptoContext. Therefore the Crypto layer provides various factory methods for creating a CryptoContext along with the context itself. The Crypto layer manipulates Plaintext and Ciphertext objects that are passed to it by the Application layer, and returns the appropriate Plaintext and Ciphertext objects to the Application. Operations on a Matrix of such objects is also provided.

Similar to CryptoContext, the library also provides BinFHEContext, SignatureContext and ABEContext for Boolean-circuit FHE, digital signature and GPV IBE/CP-ABE operations, respectively. However, unlike CryptoContext these contextes have their own implementation of ciphertexts. SignatureContext and BinFHEContext also use their own implementation of plaintexts. The Crypto layer makes use of services provided by the Lattice Operations layer.

### 4.4 Lattice Operations Layer

The Lattice Operations layer provides support for all lattice constructs, including powerof-two cyclotomic rings and arbitrary cyclotomic rings. The Double Chinese Remainder Theorem (Double-CRT) representation of cyclotomic rings is also implemented in the Lattice layer.

With the release of version 1.4.0, the lattice layer also hosts trapdoors and trapdoor sampling. Trapdoors are lattice constructs consisting of two vectors of polynomials. These structures are key parts of the newly added digital signature, identity-based encryption and ciphertext-policy attribute-based encryption schemes. These algorithms require a preimage of the information to be sampled from a discrete Gaussian over a lattice, which is done using the trapdoor sampling algorithms.

The Lattice layer is used to provide an implementation of the various Poly classes, including Poly, NativePoly, and DCRTPoly. These objects are used as building blocks in Plaintext and Ciphertext. The interface for Lattice functionality is the C++ methods provided by the Poly classes.

The Lattice layer performs lattice operations by decomposing operations into primitive arithmetic operations on integers, vectors, and matrices. The Lattice layer makes use of the Primitive Math layer to perform these operations.

### 4.5 Primitive Math Layer

The Primitive Math layer provides support for basic modular arithmetic operations, including multi-precision arithmetic. This layer also includes efficient algorithms for Number-Theoretic Transform (NTT), Fermat-Theoretic Transform (FTT), and discrete Gaussian samplers, among others. The interface for Math functionality is the C++ methods provided by both custom multi-precision libraries, and external imported libraries such as NTL.

### 4.6 Utilities

PALISADE also provides a cross-cutting Utilities module for common utility functions used by all the layers. The primary contents of this layer are tools for basic hashing, serialization and deserialization of objects, efficient memory allocation, debugging, and exception handling.

## 5 Capabilities

One of the goals of PALISADE is to provide straightforward mechanisms to select 1) an encryption protocol, 2) an encryption scheme to support that protocol, 3) encoding mechanisms to represent data with that scheme, 4) math back-ends to support efficient computational operations over that data for the scheme and 5) configuration parameters for that protocol, encoding mechanisms and math back-end. PALISADE provides a broad set of selections for each of these choices, and provides the user with the ability to add their own schemes, encodings, operations, etc. Furthermore, the user of PALISADE can select from multiple lattice layer implementations and math layer implementations, can easily mix-and-match, and can even provide their own implementations at different layers. In this section we describe these choices we make available in PALISADE.

At the highest level, the PALISADE library groups encryption protocols into a set of capabilities that can be selectively enabled by the user at run time. Enabling a particular capability turns on several functions in support that capability. Some capabilities imply other capabilities, such as how SHE, for example, implies PKE capabilities. Thus, in these scenarios, some capabilities are turned “on” automatically.

Capabilities and functions currently supported by PALISADE are listed in Tables 1–5. More detailed information on each function can be found in the PALISADE API specifications published in the gitlab repository (the API specifications are generated using Doxygen).

Table 1: Non-FHE PALISADE Capabilities and Functions
Capability | Description | Functions Supported | Also Enabled
ENCRYPTION | Public/Symmetric Key Encryption | KeyGen Encrypt Decrypt
PRE | Proxy Re-Encryption | ReKeyGen ReEncrypt | PKE

Once an encryption protocol is selected, a user of PALISADE can select from one of multiple schemes:

- BFV variants

– BFV: “textbook“ Fan-Vercauteren variant of Brakerski’s scale invariant scheme [Bra12, FV12, LN14]

– BFVrns: Halevi-Polyakov-Shoup full RNS variant of the BFV scheme [HPS18, BPA⁺18]

– BFVrnsB: Bajard-Eynard-Hasan-Zucca full RNS variant of the BFV scheme [BEHZ16, BPA⁺18]

- BGV variants

– BGV: Brakerski-Gentry-Vaikuntanathan scheme [BGV14, GHS12]

– BGVrns: A full RNS variant of the BGV scheme [KPZ20]

- CKKS: 2 full RNS variants of the Cheon-Kim-Kim-Song scheme [CKKS16] with various RNS optimizations from [CHK⁺18, BGP⁺19, HK19, KPP20]
- StSt: Stehle-Steinfeld scheme [SS11]
- FHEW: FHEW and extended TFHE schemes [DM14, CGGI18, MP20]
- Null: A system with all encryptions removed and all math operations done on Plaintext for development. Emulates BFV* and BGV* schemes (integer arithmetic operations).

Table 6 maps which schemes support which capabilities.

Starting with version 1.7, PALISADE also supports FHEW [DM14, MP20], a scheme for evaluating arbitrary Boolean circuits that runs bootstrapping for each binary gate evaluation. This scheme has very specialized functionality for working with boolean operations. Details on FHEW capabilities are provided in Table 5. Starting with release 1.8, PALISADE also supports FHEW with Gama-Izabachene-Nguyen-Xie (GINX) bootstrapping [GINX16], which is considered as an extended version of the TFHE scheme [MP20].

In addition to the homomorphic encryption schemes, PALISADE supports the following trapdoor-based schemes

- GPV Signature: Gentry-Peikert-Vaikuntanathan Digital Signature Scheme [GPV08, GPR⁺17]
- GPV IBE: Gentry-Peikert-Vaikuntanathan Identity-based Encryption Scheme [GPV08, GPR⁺17]
- CP-ABE: Zhang-Zhang Ciphertext-policy Attribute-based Encryption Scheme [ZZG12, GPR⁺17]

The functions for these schemes are listed in Table 7.

Table 2: PALISADE Operations/Functions included in the SHE capability (the Stehle-Steinfeld scheme is not included here as it supports only very limited/shallow computations). Note: BFV* and BGV* indicate all variants of BFV and BGV, respectively.
Functions Supported | Schemes Supported
EvalAdd
EvalAdd (Scalar)
EvalAdd (Plaintext)
EvalAddMutable(All)
EvalMult
EvalMult (Scalar)
EvalMult (Plaintext)
EvalMultMutable (All)
EvalMultAndRelinearize
EvalSub
EvalSub (Scalar)
EvalSub (Plaintext)
EvalSubMutable (All)
EvalNegate
EvalLinearWSum(Mutable)
EvalAutomorphism
EvalAtIndex
EvalFastRotation
EvalSumRows
EvalSumCols
EvalSum
EvalMerge
EvalAddMany(InPlace)
EvalMultMany
EvalInnerProduct
EvalLinRegression
EvalLinRegressBatched
EvalCrossCorrelation
EvalRightShift

KeySwitch
Relinearize
KeySwitchGen
EvalMultKeyGen
EvalAutomorphismKeyGen
EvalAtIndexKeyGen
EvalSumKeyGen
EvalSumRowsKeyGen
EvalSumColsKeyGen
AdjustLevelWithRescale
EvalFastRotationPrecompute AddRandomNoise

BGV*, BFV*, CKKS
CKKS
BGV*, BFV*, CKKS
CKKS, BGVrns
BGV*, BFV*, CKKS
CKKS, BGVrns
BGV*, BFV*, CKKS
CKKS, BGVrns
BFV*, BGVrns, CKKS
BGV*, BFV*, CKKS
CKKS
BGV*, BFV*, CKKS
CKKS, BGVrns
BGV*, BFV*, CKKS
CKKS, BGVrns
BGV*, BFV*, CKKS
BGV*, BFV*, CKKS
CKKS, BGVrns
CKKS
CKKS
BGV*, BFV*, CKKS
BGV*, BFV*, CKKS
BGV*, BFV*, CKKS
BGV*, BFV*, CKKS
BGV*, BFV*, CKKS
BGV*, BFV*, CKKS
BGV*, BFV*, CKKS
BGV*, BFV*, CKKS
BGV*, BFV*, StSt

BGV*, BFV*, CKKS
CKKS, BGVrns
BGV*, BFV*, CKKS
BGV*, BFV*, CKKS
BGV*, BFV*, CKKS
BGV*, BFV*, CKKSl
BGV*, BFV*, CKKS
CKKS
CKKS
CKKS
CKKS, BGVrns
BGV*, BFV*, CKKS

Table 3: PALISADE Operations/Functions included in the LeveledSHE capability. Note: BGV* indicates all variants of BGV
Functions Supported | Schemes Supported
ModReduce Rescale LevelReduce Compress EvalPoly | BGV*
| CKKS
| CKKS
| BGVrns, CKKS
| CKKS

Table 4: PALISADE Operations/Functions included in the MULTIPARTY (Threshold FHE) capability. Note: BFV* and BGV* indicate all variants of BFV and BGV, respectively
Functions Supported | Schemes Supported
MultiKeySwitchGen
MultiEvalAutomorphismKeyGen
MultiEvalSumKeyGen
MultiEvalAtIndexKeyGen
MultiAddPubKeys
MultiAddEvalKeys
MultiMultEvalKey
MultAddEvalSumKeys
MultiAddEvalAutomorphismKeys MultiAddEvalMultKeys

MultipartyDecryptLead
MultipartyDecryptMain
MultipartyDecryptionFusion

BGV*, BFV*, CKKS
BGV*, BFV*, CKKS
BGV*, BFV*, CKKS
BGV*, BFV*, CKKS
BGV*, BFV*, CKKS
BGV*, BFV*, CKKS
BGV*, BFV*, CKKS
BGV*, BFV*, CKKS
BGV*, BFV*, CKKS

BGV*, BFV*, CKKS
BGV*, BFV*, CKKS
BGV*, BFV*, CKKS
BGV*, BFV*, CKKS

Table 5: PALISADE Capabilities and Functions for Boolean-Circuit FHE (performs bootstrapping for each binary gate evaluation)
Capability | Description | Functions Supported
FHEW | FHE Scheme for Arbitrary Boolean Circuits | KeyGen BTKeyKeyGen Encrypt Decrypt Bootstrap EvalNOT EvalBinGate(OR) EvalBinGate(AND) EvalBinGate(NOR) EvalBinGate(NAND) EvalBinGate(XOR) EvalBinGate(NXOR) EvalBinGate(XOR_FAST) EvalBinGate(NXOR_FAST)

Table 6: PALISADE Implemented Capabilities Matrix
Function/Scheme CKKS | StSt | BGV* BFV* Null
ENCRYPTION | Y | Y | Y | Y | Y
PRE | Y | Up to 2 hops | Y | Y | Y
SHE | Y | Up to 2 levels | Y | Y | Y
LeveledSHE | Y | | Y | | Y
Multiparty | Y | Limited | Y | Y | Y

Table 7: Other PALISADE Capabilities and Functions
Capability | Description | Functions Supported | Also Enabled
CP-ABE | Ciphertext-Policy Attribute-Based Encryption | Setup KeyGen KeyGenOfflinePhase KeyGenOnlinePhase Encrypt Decrypt
GPV Signature | Digital Signature | KeyGen Sign SignOfflinePhase SignOnlinePhase Verify
GPV IBE | Identity-Based Encryption | Setup KeyGen KeyGenOfflinePhase KeyGenOnlinePhase Encrypt Decrypt

After the selection of the scheme, a user can then select how to represent polynomials, among the following polynomial types:

- Poly, which corresponds to representing polynomial coefficients in a multiprecision integer format.
- DCRTPoly, which corresponds to representing polynomial coefficients in a Residue Number System (RNS), a.k.a. Chinese Remainder Theorem (CRT), format using single-precision integers.
- NativePoly, which corresponds to representing polynomial coefficents in a single-precision format (only works up to the word size of 60 bits).

We generally recommend using the DCRTPoly representation of polynomials for performance on commodity computing environments. We include the multiprecision polynomial representation Poly primarily for advanced users and implementers of new schemes who wish to do an initial implementation using the simpler, less efficient Poly representation.

Similar to the polynomial representations, PALISADE also supports multiple big integer math back-ends. The user selects which of the various math back-ends are included at build or compile time 2
. Currently supported multi-precision math back-ends include:
- Multi-precision with fixed bitwidth sizing (MATHBACKEND 2) supporting bit widths up to 3500 by default (this limit can be changed in a header file). This is the default back-end.
- Multi-precision with dynamic bitwidth sizing (MATHBACKEND 4). This back-end is slightly slower than MATHBACKEND 2, but allows for extremely large integers.
- NTL and GMP based multi-precision with variable sizing and optimization for various
platforms (MATHBACKEND 6)

3

Note the numbering of back-ends is due to historical reasons, as various back-ends have been deprecated over time.

Native data types are always available (and used for NativePoly and single-precision integers in DCRTPoly), and we currently support native 64-bit and 128-bit word sizes. This limitation may be lifted in future releases, allowing PALISADE to be used on 32-bit architectures.

2Math back-end selection is controlled at build setup time by adding a cmake flag, e.g.,

-DMATHBACKEND=4, or at compile time by editing src/core/lib/math/backend.h.
3We include the minimum required version of the GMP and NTL distribution with our release.

## 6 PALISADE Directory Structure

The directory structure of the PALISADE source code is shown in Listing 1 and Table 8.

|- benchmark
|- build
|- doc
|- src
| | |- binfhe
| | | | |- include | -- Boolean-circuit FHE header files
| | | | |- lib | -- Boolean-circuit FHE source files
| | |- core
| | | | |- include | -- PALISADE core header files
| | | | |- math
| | | | |- lattice
| | | | |- encoding
| | | | |- util
| | | | |- lib | -- PALISADE core source files
| | | | |- math
| | | | |- lattice
| | | | |- encoding
| | | | |- util
| | |- abe
| | | | |- include | -- Attribute-based encryption crypto layer header files
| | | | |- lib | -- Attribute-based encryption crypto layer source files
| | |- pke
| | | | |- include | -- Homomorphic scheme header files
| | | | |- scheme
| | | | |- bfv -- Original BFV (integ. arithm. - slower than RNS variants)
| | | | |- bfvrns -- HPS RNS variant of BFV scheme (integer arithmetic)
| | | | |- bfvrnsb -- BEHZ RNS variant of BFV scheme (integer arithmetic)
| | | | |- bgv -- BGV scheme (integer arithmetic)
| | | | |- bgvrns -- full RNS variant of BGV scheme (integer arithmetic)
| | | | |- ckks -- CKKS scheme (real-number arithmetic)
| | | | |- null -- NULL scheme (integer arithemtic)
| | | | |- stst -- Stehle-Steinfeld scheme (limited | HE operations)
| | | | |- lib | -- Public key encryption crypto layer source files
| | | | |- scheme
| | | | |- bfv -- Original BFV (integ. arithm. - slower than RNS variants)
| | | | |- bfvrns -- HPS RNS variant of BFV scheme (integer arithmetic)
| | | | |- bfvrnsb -- BEHZ RNS variant of BFV scheme (integer arithmetic)
| | | | |- bgv -- BGV scheme (integer arithmetic)
| | | | |- bgvrns -- full RNS variant of BGV scheme (integer arithmetic)
| | | | |- ckks -- CKKS scheme (real-number arithmetic)
| | | | |- null -- NULL scheme (integer arithemtic)
| | | | |- stst -- Stehle-Steinfeld scheme (limited | HE operations)
| | |- signature
| | |- include | -- Signature crypto layer header files
| | |- lib | -- Signature crypto layer source files
|- test | -- Test software scripts
|- third-party | -- External third-party software

Listing 1: Directory structure for PALISADE source code

All of the src/core, src/pke. src/binfhe, src/abe and src/signature contain subdirectories for header files (include), library source files (lib), unit tests (unittest) as well as

Table 8: PALISADE Library File Structure Directory Description
benchmark Code for benchmarking PALISADE library components.
build | Binaries and build scripts (this folder is created by the user).
doc | Documentation of library components, including doxygen.
src | Library source code.
test | Google unit test code.
third-party Code provided by an external third party.

subdirectories for main examples (examples) that exercise most common capabilities of PALISADE and additional examples (extras) for less common scenarios.

## 7 Terminology and Notation

In this section we provide a glossary of terminology that we use in PALISADE.

PALISADE provides a framework for using lattice cryptography.

If a Scheme supports the ENCRYPTION Capability, encrypt and decrypt methods are available for use. The encrypt and decrypt methods are provided as part of the implementation of the ENCRYPTION Capability in the Scheme being used. A Plaintext can be encrypted into a Ciphertext through the use of an encrypt method. A Ciphertext can be used to generate a Plaintext through the use of a decrypt method. The library supports several formats of Plaintext and methods to create a Plaintext for use in PALISADE.

If a Scheme supports the PRE Capability, a re-encrypt method is available.

If a Scheme supports the SHE and/or LeveledSHE Capability, then there is support for homomorphic operations on pairs of Ciphertext as well as mixed-mode operations between a Ciphertext and a Plaintext. These operations are supported by using C++ operator overloading. For example, multiplication of two instances of a Ciphertext, A and B, can be simply written as A * B.

PALISADE also includes support for several Matrix operations. It is possible to create several Matrix of Plaintext, encrypt them, perform operations on them, and then decrypt
back into a Matrix of Plaintext.

### 7.1 Typing

All PALISADE operations are strongly typed. A Plaintext that is passed to encrypt will create a Ciphertext that is aware of the underlying format of the Plaintext, as well as the particular key that was used to encrypt the Plaintext. The decrypt operation will fail in cases where an improper key is used. A successful decrypt will produce a new Plaintext whose underlying format matches the initial Plaintext that was passed to encrypt. Homomorphic operations between Ciphertexts, and mixed-mode operations between a Ciphertext and a Plaintext will only be permitted for operands with formats and keys that match.

The underlying data inside of PALISADE is an Element in lattice space. Within PAL-ISADE, all Plaintexts are encoded into an Element. Every Ciphertext contains one or more Element objects, and all operations are mathematical operations on these
Elements.

There are several formats of Element available: a Poly, which represents the encoded Plaintext as a polynomial; a NativePoly, which uses a polynomial with coefficients with a maximum size of 64 bits (when the native backend is set to use 64-bit integers); and a DCRTPoly, which represents the encoded Plaintext as a stack of decomposed NativePoly polynomials using the Double Chinese Remainder Theorem.

### 7.2 CryptoContext

A CryptoContext in PALISADE is the class that provides all PALISADE encryption functionality. All objects used in a PALISADE implementation are created by a CryptoContext and can be considered to “belong to” the CryptoContext that they were created with.

Any and all operations on PALISADE objects must be on objects that belong to the same CryptoContext. The high-level use of the CryptoContext to encrypt a Plaintext to generate a Ciphertext is as follows:

1. Choose a set of ElementParams to define parameters for the Element to be used.
2. Choose a set of EncodingParams to define parameters for encoding.
3. Select a Scheme that you wish to use for lattice cryptography.
4. Construct a CryptoContext for your selected scheme, ElementParams and EncodingParams, in which all operations shall take place. The construction of a CryptoContext involves selecting parameters for security and performance. There are potentially multiple mechanisms to generate the Scheme parameters needed for this construction.
5. Select which Capability are used with the CryptoContext. Note that not every Scheme will support every possible Capability.
6. Use CryptoContext methods to create Keys.
7. The user may also perform homomorphic operations on Ciphertext and Plaintext objects if that Capability has been enabled and if the Scheme supports the operations.
8. Encrypt a Plaintext into a Ciphertext.
9. Decrypt a Ciphertext back to a Plaintext.

Each CryptoContext is uniquely identified by its Scheme, Element type, ElementParams and EncodingParams. When we say that an object "belongs to" a CryptoContext, we are actually saying that it is associated with a CryptoContext with a particular Scheme,
Element type, ElementParams and EncodingParams.

PALISADE incorporates the standard security tables developed during the Homomorphic Encryption standardization process described at
http://homomorphicencryption.org. Users of the library can construct a CryptoContext by specifying the parameter sets defined in the standard.

It follows that if one creates a CryptoContext on two different computers, each with the
same Scheme, Element type, ElementParams and EncodingParams, then those two CryptoContexts are the same, and objects created on one machine can be transferred to and used on the other machine.

### 7.3 BinFHEContext

A BinFHEContext is the equivalent of a CryptoContext for Boolean-circuit FHE. All operations are performed usng an instance of the BinFHEContext class. The high-level use of an BinFHEContext to perform FHE operations is as follows:

1. Choose a predefined configuration to instantiate the context. The options are:
- TOY (Toy parameter set for unit tests and debugging),
- MEDIUM (≥ 100 bits of security for both classical and quantum computer attacks),
- STD128 (HE standard set with more than 128 bits of security w.r.t. classical computer attacks),
- STD192 (HE standard set with more than 192 bits of security w.r.t. classical computer attacks),
- STD256 (HE standard set with more than 256 bits of security w.r.t. classical computer attacks),
- STD128Q (HE standard set with more than 128 bits of security w.r.t. quantum computer attacks),
- STD192Q (HE standard set with more than 192 bits of security w.r.t. quantum computer attacks),
- STD256Q (HE standard set with more than 256 bits of security w.r.t. quantum computer attacks).
2. Generate a secret key (an instance of LWEPrivateKey).
3. Generate the bootstrapping keys, including a refreshing and switching keys. The bootstrapping keys are stored inside the context.
4. Encrypt a plaintext (LWEPlaintext) to form a ciphertext (an instance of LWECiphertext).
5. Perform any of the following operations as many times as needed: NOT (no boostrapping), OR, AND, NAND, NOR, XOR, or XNOR. The last six require bootstrapping and
take the same time to execute.
6. Decrypt the result using the secret key.

### 7.4 ABEContext

An ABEContext is the equivalent of a CryptoContext for attribute-based and identity-based encryption functionality. All CP-ABE and GPV IBE related operations are done using an ABEContext. The high-level use of an ABEContext to encrypt a Plaintext is as follows:

1. Choose a set of parameters to create appropriate set of ElementParams for the Element to be used.
2. Select a Scheme to use (GPV IBE or CP-ABE).
3. Construct a ABEContext for your selected scheme and parameters. Note that the
steps up to this point are similar to CryptoContext, with the exception of EncodingParams. This is due to the fact that ABEContext at its current implementation only supports
the plaintext modulus of 2 for encoding, hence it is done internally.
4. Create an AccessPolicy for the parties that will be able to decrypt.
5. Use ABEContext methods to create Keys.
6. Encrypt a Plaintext under an AccessPolicy into a Ciphertext.
7. Decrypt a Ciphertext back to a Plaintext.

The standard security tables developed during the Homomorphic Encryption standardization process described at http://homomorphicencryption.org also apply to
ABEContext.

It is also worth to mention that ABEContext does not support DCRTPoly at its current state. However, for most cases NativePoly is enough. For the time being, ABE does not have homomorphic operations within ciphertexts defined. Because of this the ciphertext modulus required for the security/correctness of regular encryption functionality is below 64 bits.

### 7.5 SignatureContext

A SignatureContext is the equivalent of a CryptoContext for digital signature schemes. All GPV signature scheme-related operations are done using a SignatureContext. The high-level use of a SignatureContext to sign a Plaintext is as follows:

1. Choose a set of parameters to create appropriate set of ElementParams for the Element to be used.
2. Select a Scheme to use (GPV only for the time being).
3. Construct a SignatureContext for your selected scheme and parameters. Note that the steps up to this point are similar to CryptoContext, with the exception of EncodingParams. This is due to the fact that the encoding is handled internally.
4. Use SignatureContext methods to create Keys.
5. Sign a Plaintext into a Signature.
6. Verify a Signaturewith a Plaintext.

It is also worth to mention that just like ABEContext, SignatureContext does not support DCRTPoly at its current state and NativePoly is enough for all cases. Homomorphic operations are not defined for signatures, which means there is no need for moduli larger than 64 bits.

### 7.6 Plaintext

A Plaintext is used in PALISADE to represent something that has not been encrypted. It is actually the base class for each of the possible plaintext encodings that are supported in PALISADE:

- ScalarEncoding
- IntegerEncoding
- FractionalEncoding
- PackedEncoding
- CKKSPackedEncoding
- CoefPackedEncoding
- StringEncoding

A Plaintext is created by invoking the appropriate CryptoContext method, passing it the unencrypted information as a parameter.

Once created, a Plaintext can be encrypted into a Ciphertext using the CryptoContext Encrypt routine.

A Plaintext can also be used as a parameter to several of the CryptoContext homomorphic operations.

When a Ciphertext is decrypted, the decryption method creates a new Plaintext to contain the decryption.

The Plaintext has several methods that provide access to the information in the Plaintext, as shown in listing 2:

const std::string& | GetStringValue();
const int64_t | GetIntegerValue();
const int64_t | GetScalarValue();
const vector<int64_t>& | GetCoefPackedValue();
const vector<uint64_t>& | GetPackedValue();
const vector<complex<double>>& | GetCKKSPackedValue();

Listing 2: Values in Plaintext

Note that the only one of these Plaintext methods that will return a value is the one that corresponds to the actual type of the Plaintext. For example, GetStringValue() will return a std::string if the Plaintext is actually a StringEncoding, and will throw an exception otherwise.

While ABEContext also uses Plaintext for unencrypted information, SignatureContext uses its own plaintext definition.

### 7.7 Ciphertext

A Ciphertext is used in PALISADE to represent encrypted information. A Ciphertext is created from a Plaintext by an encrypt method, and is converted back to a Plaintext by a decrypt method. The encrypt and decrypt methods also require Keys that have been generated by the CryptoContext.

Homomorphic operations between pairs of Ciphertext, or between a Ciphertext and a Plaintext, are supported, provided that the encodings of the operands match, and provided that those encodings support homomorphic operations (for example, homomorphic operations are not supported for string encodings, and will be rejected if attempted).

The CP-ABE/GPV IBE schemes utilizing ABEContext have their own unique classes for ciphertext implementations, which do not have homomorphic operations supported at this time.

### 7.8 Access Policy

An AccessPolicy is a rule/set of rules dictating the decrypting party of the communication. User holding the appropriate rights can generate the relevant Keys for decryption and decrypt the information encrypted under an AccessPolicy.

In the context of GPV IBE, AccessPolicy refers to the unique user identifier.

In the context of CP-ABE, AccessPolicy can refer to both attributes defined for the access policy as well as user’s own attribute set.

### 7.9 Signature

A Signature is used in PALISADE for authentication. A Signature is created from a Plaintext by a sign method, and used in conjunction with the Plaintext for verification. The sign and verify methods also require Keys that have been generated by the
SignatureContext.

### 7.10 Keys

Many PALISADE functions make use of Keys. These objects are created using CryptoContext,
ABEContext or SignatureContext methods.

Encryption and decryption functionality requires a public key/private key pair. The CryptoContext KeyGen method generates this key pair and returns it to the caller.

CP-ABE and GPV IBE operations require a master public key/private key pair for the encryption and derivation of personal secret keys. This is done using Setup method of ABEContext. For decryption, a secret key corresponding to an access policy/user is required, which is done using the ABEContext KeyGen method.

Signing and verification operations for digital signature schemes require a sign(private)/verify(public) key pair. This pair can be generated using the SignatureContext KeyGen method.

Re-Encryption requires an Evaluation key. This key is generated using the ReKeyGen method.

Certain homomorphic operations may require the application of evaluation keys to complete
the operation. The CryptoContext EvalMultKeyGen and EvalAddKeyGen methods are used to generate the requisite keys needed for the EvalMult and EvalAdd operations, respectively.

### 7.11 Capability

A Capability refers to sets of CryptoContext methods that must be enabled before they can be used. A Capability must be enabled by calling the CryptoContext Enable method and passing it the name of the Capability as an argument. Multiple values for Capability can be or-ed together and passed as a single argument to Enable.

Section 5 discusses in the detail the available choices for Capability, and the functionality enabled when a particular Capability is Enabled.

### 7.12 Scheme

A Scheme (the full class name is LPPublicKeyEncryptionScheme) contains the algorithms used for key generation, encryption/decryption, and homomorphic operations.

Table 6 outlines the different supported schemes in PALISADE.

In order to use a particular Scheme, its configuration parameters must be specified. The particular configuration parameters for each scheme are stored in a CryptoParameters class (the full class name is LPCryptoParameters) that is particular for that scheme. The classes for CryptoParameters for each scheme are unique, but they all share several characteristics:

1. Each CryptoParameters class has a constructor that allows for the specification of all configuration parameters.

2. The CryptoParameters may have a ParamsGen feature that generates a full set of configuration parameters from a small specification as to how many homomorphic operations will be performed.
3. The CryptoParameters class is part of the CryptoContext

ABEContext and SignatureContext also use their equivalent parameter classes like
CryptoParameters.

### 7.13 Element

The math layer performs operations on different kinds of Element. This is a representation of a vector in lattice space.

### 7.13.1 Poly

A Poly is a vector of polynomial coefficients. The coefficients are whatever the BigInteger type is for the selected math back-end, and the vector is simply a vector of these BigInteger, and an associated modulus. All operations on a Poly are done modulo this modulus.

### 7.13.2 NativePoly

A NativePoly is a vector of polynomial coefficients where each of the coefficients is of type 64-bit unsigned integer. The NativePoly also has a modulus of at most 64 bits (though our math implementations are most efficient for moduli of 60 bits or less). Again,all operations are done modulo the modulus.

### 7.13.3 DCRTPoly

A DCRTPoly implements a large Poly decomposed via residue arithmetic into a tower (set) of NativePoly elements.

### 7.14 ElementParams

An ElementParams is a container for the configuration parameters of whatever Element is being used. The configuration parameters include the ring dimension, cyclotomic order, and primitive root of unity.

### 7.15 EncodingParams

An EncodingParams is a container for all of the parameters needed to encode a Plaintext. In most cases, this consists solely of a plaintext modulus; however, some encodings require more detailed parameters.

### 7.16 Matrix

PALISADE supports general operations Matrix objects with elements of the types described above in this section, as well as operations on these matrices. A user can create a matrix of Plaintext, encrypt it into a matrix of Ciphertext, and perform operations on matrices.

In addition to homomorphic matrix multiplication, higher level statistical operations such as inner product and linear regression are available. Some operations result in a matrix of RationalCiphertext, where each entry in the matrix is a rational number such that the numerator and denominator of the entry is a Ciphertext. For matrices of RationalCiphertext, separate decryption of the numerators and denominators of each entry are provided.

## 8 Sample Implementations: PKE Module

### 8.1 Creating a CryptoContext

All PALISADE operations in the PKE module are associated with a CryptoContext; therefore, the first step in using PALISADE is to acquire a CryptoContext. A CryptoContext can be created in a number of different ways through the use of static CryptoContextFactory methods. The factory methods return a shared_ptr to a CryptoContext.

It is useful to note that PALISADE keeps track all of the CryptoContexts that have been created, and will not create duplicate contexts. If a user requests that the factory create a context that already exists, the factory simply returns a shared_ptr to the existing context rather than creating a duplicate of that existing context.

A CryptoContext is uniquely identified by the parameters for the underlying lattice layer element that is to be used, the encoding parameters to be used with Plaintext, and the Scheme (and any associated configuration parameters for the Scheme).

The underlying lattice layer element is either a Poly, a NativePoly, or a DCRTPoly. These type names are used as template parameters with the CryptoContext and its methods. The lattice layer elements share a set of element parameters that are given to the CryptoContextFactory methods.

Encoding parameters may be a simple Plaintext modulus, or they may be a broader set of EncodingParms that are used. Encoding parameters are passed to the CryptoContextFactory methods.

Different Schemes have wildly different configuration parameters, and so the Scheme is selected by calling a CryptoContextFactory method for the desired Scheme.

Each Scheme actually has several factory methods:

- A method that accepts values for all configuration parameters for the scheme.
- A method that accepts some values for configuration parameters, and that invokes a scheme-specific parameter generation operation.

There are two other mechanisms available for creating a CryptoContext:

- Deserialize a previously serialized CryptoContext.
- Construct a CryptoContext from one of the set of predefined scheme parameters.

Once a CryptoContext has been created, the appropriate capabilities should be enabled. Once this is complete, the CryptoContext is ready for use.

Below are some code samples for creating contexts. Listing 3 demonstrates creating a CryptoContext by specifying all of the scheme’s parameters.

/// Example showing creating a BGV CryptoContext /// By specifying all Scheme parameters
/// Element is Poly with non power-of-two cyclotomics

usint m = 22;
PlaintextModulus p = 2333;
BigInteger ptm(p);

BigInteger ctm("955263939794561");
BigInteger srr("941018665059848");
BigInteger bigmod("80899135611688102162227204937217"); BigInteger bigroot("77936753846653065954043047918387");

auto cycloPoly = GetCyclotomicPolynomial<BigVector>(m, ctm); ChineseRemainderTransformArb<BigInteger, BigVector>::SetCylotomicPolynomial( cycloPoly, ctm);

float stdDev = 3.19;
usint bSize = 8;

shared_ptr<Poly::Params> params(new ILParams(m, ctm, srr, bigmod, bigroot));

EncodingParams ep(new EncodingParamsImpl(p, PackedEncoding:: GetAutomorphismGenerator(p), bSize));

CryptoContext<Poly> cc = CryptoContextFactory<Poly>::genCryptoContextLTV( params, ep, bSize, stdDev);

cc->Enable(ENCRYPTION);
cc->Enable(SHE);

Listing 3: Creating a CryptoContext with parameters

Listing 4 demonstrates the use of the factory method that uses parameter generation.

Listing 5 shows the use of preconfigured parameter sets.

/// Example showing creating a BFV Cryptocontext /// using parameter generation
/// Element is DCRTPoly (configured by ParamsGen)

int relWindow = 1;
PlaintextModulus ptm = 256;
double sigma = 4;
double rootHermiteFactor = 1.006;

//Set Crypto Parameters
CryptoContext<Poly> cryptoContext = CryptoContextFactory<Poly>::genCryptoContextBFV( ptr, rootHermiteFactor, relWindow, sigma, 0, 5, 0, OPTIMIZED, 6);

// enable features that you wish to use cryptoContext->Enable(ENCRYPTION); cryptoContext->Enable(SHE);

Listing 4: Creating a CryptoContext with parameter generation

/// Example showing CryptoContext generation // from a preconfigured parameter set

CryptoContext<Poly> cryptoContext = CryptoContextHelper::getNewContext("BGV3");

if( !cryptoContext ) {
cout << "Error creating CryptoContext" << endl; return 0;
}

cryptoContext->Enable(ENCRYPTION);

Listing 5: Creating a preconfigured CryptoContext

Listing 6 shows the use of parameter sets defined by the Homomorphic Encryption standardization process, as defined in http://homomorphicencryption.org.

/// Example showing CryptoContext generation
// using standard tables from the homomorphic encryption standardization project

PlaintextModulus ptm = 536903681;
double sigma = 3.2;
SecurityLevel securityLevel = HEStd_128_classic;

// support 7 multiplies (ciel(log2(7)))
usint nMults = 3;

// generate keys for s^2 and s^3
usint maxDepth = 3;

CryptoContext<DCRTPoly> cryptoContext = CryptoContextFactory<DCRTPoly>::genCryptoContextBFVrns(
ptm, securityLevel, sigma, 0, nMults, 0, OPTIMIZED, maxDepth);

if( !cryptoContext ) {
cout << "Error creating CryptoContext" << endl;
return 0;
}

cryptoContext->Enable(ENCRYPTION);

Listing 6: Creating a CryptoContext using standard paranerers

Listing 7 shows creation from a serialization.

/// Example showing CryptoContext generation /// from a serialization

// Deserialize the crypto context
CryptoContext<DCRTPoly> cc;
if ( !Serial::DeserializeFromFile(DATAFOLDER + "/cryptocontext.txt", cc, SerType::BINARY) ) {
cerr << "I cannot read serialization from " << DATAFOLDER + "/ cryptocontext.txt" << endl;
}
else
cout << "The cryptocontext has been deserialized." << std::endl;

Listing 7: Creating a CryptoContext from a serialization

### 8.2 Creating A Plaintext

PALISADE users are able to convert integers, vectors of integers, vectors of complex numbers, and strings into Plaintext objects.

Plaintext objects can be used as input to Encryption, can be used as part of homomorphic operations, and are produced as a result of decryption.

All Plaintexts are created by static factory methods within the CryptoContext. Each style of Plaintext encoding has its own factory method.

The Plaintexts are all type safe. A Ciphertext knows the encoding used by the original Plaintext that it came from. Decryption creates a Plaintext with the proper encoding. All homomorphic operations check types before performing the operation, and will fail if either the encodings do not match, or if a particular encoding does not support homomorphic operations.

### 8.2.0.1 ScalarEncoding

ScalarEncoding is used to encode a single integer by simply copying the integer into the polynomial starting at index 0 and zero-filling remaining unused indices of the polynomial. Listing 8 shows an example of creating a Scalar Plaintext.

int64_t val = 12;

Plaintext sPtx = ctx->MakeScalarPlaintext(val);

Plaintext sPtx2 = ctx->MakeScalarPlaintext(-val);

Listing 8: Creating a Scalar Plaintext

### 8.2.0.2 IntegerEncoding

IntegerEncoding is used to encode a single unsigned integer into a polynomial such that each bit (0 or 1) in the integer is copied into its corresponding slot in the polynomial. For example, the integer 14, which is binary 1110, is encoded by emplacing 1, 1, 1 and 0 into the first four positions of the polynomial. This is shown in listing 9.

Plaintext intPtx = ctx->MakeIntegerPlaintext(14);

Listing 9: Creating an Integer Plaintext

Important Note: IntegerEncoding encodes each bit of the integer into a separate coefficient of the polynomial. This implies that the ring dimension (degree of polynomial) should be large enough to store all bits, especially in scenarios where each homomorphic multiplication doubles the number of polynomial coefficients with each multiplication. This is typically a non-issue for secure schemes/settings (as the ring dimension is already large enough) but can be an issue for the Null scheme, where the cyclotomic order is provided as an input argument.

### 8.2.0.3 FractionalEncoding

FractionalEncoding is a generalization of IntegerEncoding that can encode both integers and fractions. Currently it is limited in its functionaly and is only used to add support for right shifting (moving least significant bits to the fractional part). Examples of FractionalEncoding for encoding an integer 3 and a fraction 1/8 are shown in listing 10.

Plaintext intPtx = ctx->MakeFractionalPlaintext(3); Plaintext intPtx = ctx->MakeFractionalPlaintext(0,3);

Listing 10: Creating a Fractional Plaintext

Important Note: FractionalEncoding encodes each bit of the integer into a separate coefficient of the polynomial. This implies that the ring dimension (degree of polynomial) should be large enough to store all bits, especially in scenarios where each homomorphic multiplication doubles the number of polynomial coefficients with each multiplication. This is typically a non-issue for secure schemes/settings (as the ring dimension is already large enough) but can be an issue for the Null scheme, where the cyclotomic order is provided as an input argument.

### 8.2.0.4 CoefPackedEncoding

CoefPackedEncoding is used to encode a vector of integers, or an initializer list of integers, into a polynomial such that each integer is emplaced into a coefficient of the polynomial. This is illustrated in listing 11.

std::vector<int64_t> inputs( { 2, 3, 5, 7} );

// construction from vector
Plaintext c1 = ctx->MakeCoefPackedPlaintext(inputs);

// construction from initializer list
Plaintext c2 = ctx->MakeCoefPackedPlaintext({-6,1,4,8});

Listing 11: Creating a CoefPackedEncoding Plaintext

### 8.2.0.5 PackedEncoding

PackedEncoding is an implementation of an efficient encoder packing multiple integers into a single plaintext polynomial (single ciphertext) that enables SIMD (Single Instruction, Mutiple Data) operations on these integers. Currently PALISADE supports addition, multiplication, and rotation capabilities for packed ciphertexts. The cyclotomic order m has to divide p − 1, where p is the plaintext modulus. This is shown in listing 12.

std::vector<int64_t> val( {37, 22, 18, 4, 3, 2, 1, 9} );

Plaintext packedPtx = ctx->MakePackedPlaintext(val);

Listing 12: Creating a PackedEncoding Plaintext

### 8.2.0.6 CKKSPackedEncoding

CKKSPackedEncoding is an implementation of an efficient encoder packing multiple complex/real numbers into a single plaintext polynomial (single ciphertext) that enables SIMD (Single Instruction, Mutiple Data) operations on these complex/real numbers. Currently PALISADE supports addition, multiplication, and rotation capabilities for packed ciphertexts. An exampple is shown in listing 13.

// a vector of real numbers
std::vector<complex<double>> val( {0.1111, 0.2222, 0.3333, 0.4444, 0.5555, 0.6666, 0.7777, 0.8888} );
Plaintext packedPtx = ctx->MakeCKKSPackedPlaintext(val);

// a vector of complex numbers
std::vector<complex<double>> valComplex( {0.1111 + 0.1i, 0.2222 + 0.2i, 0.3333 + 0.1i, 0.4444 + 0.1i, 0.5555 + 0.1i, 0.6666 + 0.1i, 0.7777 + 0.1i, 0.8888 + 0.1i} );
Plaintext packedPtxComplex = ctx->MakeCKKSPackedPlaintext(valComplex);

Listing 13: Creating a CKKSPackedEncoding Plaintext

### 8.2.0.7 StringEncoding

StringEncoding is used to encode a string into a polynomial. For this encoding, each 8-bit character in the input is encoded directly into a coefficient of the polynomial. This encoding is constrained to only use 256 as a plaintext modulus. Listing 14 shows the use of this encoding.

Future implementations that support other character encodings, such as Unicode, are possible but are not currently supported.

Homomorphic operations will NOT work with this encoding.

string s("Here is my string!");

Plaintext stringPtx = ctx->MakeStringPlaintext(s);

Listing 14: Creating a String Plaintext

### 8.3 Encryption

In order to encrypt a Plaintext into a Ciphertext, create a CryptoContext and a Plaintext as illustrated above.

The code in listing 15 illustrates this. It assumes that you have created a CryptoContext named "cc" and have created a Plaintext named ptxt within cc.

Observe that the code uses the KeyGen method to create a key pair, and uses the publicKey portion of that key pair for the encryption. The encryption will fail if the keys were generated in a different CryptoContext than cc.

/////////////////////////////////////////////////////// // Perform Key Generation Operation ///////////////////////////////////////////////////////

LPKeyPair<Poly> keyPair = cc->KeyGen();

if( !keyPair.good() ) {
cout << "Key generation failed!" << endl; exit(1);
}

/////////////////////////////////////////////////////// // Encryption
///////////////////////////////////////////////////////

Ciphertext<Poly> ciphertext;

ciphertext = cc->Encrypt(keyPair.publicKey, ptxt);

Listing 15: Encrypting

### 8.4 Decryption

In order to decrypt a Ciphertext into a Plaintext, a CryptoContext, Ciphertext and KeyPair must exist. The keys and the Ciphertext must have been created within the CryptoContext. An example is shown in listing 16.

/////////////////////////////////////////////////////// //Decryption of Ciphertext ///////////////////////////////////////////////////////

Plaintext decrypted;

cc->Decrypt(keyPair.secretKey, ciphertext, &decrypted);

Listing 16: Decrypting

### 8.5 Re-Encryption

Re-Encryption involves converting a Ciphertext that is decryptable with key "A" into a Ciphertext that is decryptable with key "B" by creating a re-encryption key and using it to re-encrypt the ciphertext.

The code sample in listing 17 illustrates this capability. It assumes a CryptoContext cc, an initial keypair A, and a Ciphertext cipher that has been created using A. We show the generation of key pair B, the generation of the re-encryption key, the re-encryption operation, and the subsequent decryption of the re-encrypted Ciphertext with B’s secret key.

Two variants of re-encryptions are shown. The first one corresponds to the Chosen Plaintext Attack (CPA) model. The second variant corresponds to the model secure under Honest Re-encryption Attacks (HRA) [Coh17]. We recommend the HRA model for practical use.

Note that in order to use Re-Encryption, the PRE capability must be enabled for the CryptoContext.

/////////////////////////////////////////////////////// // Perform Key Generation Operation ///////////////////////////////////////////////////////

// Initialize Key Pair Containers
LPKeyPair<Poly> B = cc->KeyGen();

if( !B.good() ) {
cout << "Key generation failed!" << endl; exit(1);
}

/////////////////////////////////////////////////////// //Perform Re-encryption key generation operation. ///////////////////////////////////////////////////////

LPEvalKey<Poly> rekey =
cc->ReKeyGen(B.publicKey, A.secretKey);

/////////////////////////////////////////////////////// // Re-Encryption
// CPA-secure variant
///////////////////////////////////////////////////////

auto re_cipher = cc->ReEncrypt(rekey, cipher);

/////////////////////////////////////////////////////// //Decryption of Ciphertext ///////////////////////////////////////////////////////

/////////////////////////////////////////////////////// // Re-Encryption with Ciphertext Re-randomization
// HRA-secure variant
///////////////////////////////////////////////////////

auto re_cipherHRA = cc->ReEncrypt(rekey, cipher,A.publicKey);

/////////////////////////////////////////////////////// //Decryption of Ciphertext ///////////////////////////////////////////////////////

Plaintext ptxtHRA;

cc->Decrypt(B.secretKey, re_cipherHRA, &ptxtHRA);

Listing 17: Re-Encrypting

### 8.6 Serialization and Deserialization

When used in client/server and other distributed application settings, PALISADE objects need to be saved to persistent storage or streams, and then loaded back to instantiate the PALISADE objects in memory. PALISADE provides a serialization capability based on the industry-standard C++ cereal library (see https://github.com/USCiLab/cereal). The objects can be serialized either as binary objects (fastest option) or as JSON files (in cross-platform scenarios).

PALISADE objects can be serialized to streams (Serialize/Deserialize methods) or files (SerializeToFile/DeserializeFromFile methods).

Many of the objects to be serialized are associated with a particular CryptoContext. In order for such objects to be correctly serialized and deserialized, the serialization saves the Crypto-Context that the object belongs to as part of the serialization, and the deserialization makes sure that the CryptoContext for the object being deserialized matches the CryptoContext in the serialization.

A simple of example of serialization to files is provided in src/pke/examples/simple-integers-serial.cpp. A simple example of serialization to streams is provided in pke/unittest/UnitTestSer.h.

### 8.7 Homomorphic Addition of Ciphertexts

Homomorphic addition of two Ciphertext is performed by invoking the EvalAdd method of the CryptoContext. Both of the operands to the EvalAdd must have been created in the same CryptoContext, encrypted with the same Key, and encoded in the same way for this operation to work.

The code sample in listing 18 illustrates how to encode two vectors of integers into Plaintext, encrypt them into Ciphertext, perform homomorphic addition, and decrypt the result back into a Plaintext.

This code assumes a CryptoContext named cc and a keypair named kp.

// Encode source data

std::vector<int64_t> v1 = {3,2,1,3,2,1,0,0,0,0,0,0}; std::vector<int64_t> v2 = {2,0,0,0,0,0,0,0,0,0,0,0}; std::vector<int64_t> v3 = {1,0,0,0,0,0,0,0,0,0,0,0}; Plaintext p1 = cc->MakeCoefPackedPlaintext(v1); Plaintext p2 = cc->MakeCoefPackedPlaintext(v2); Plaintext p3 = cc->MakeCoefPackedPlaintext(v3);

// Encryption

auto c1 = cc->Encrypt(kp.publicKey, p1); auto c2 = cc->Encrypt(kp.publicKey, p2); auto c3 = cc->Encrypt(kp.publicKey, p3);

// EvalAdd Operation

auto c12 = cc->EvalAdd(c1,c2);
auto csum = cc->EvalAdd(c12,c3);

//Decryption after Accumulation Operation

Plaintext plaintextAdd;

cc->Decrypt(kp.secretKey, csum, &plaintextAdd);

plaintextAdd->SetLength(p1->GetLength());

cout << "Original Plaintext:" << endl; cout << p1 << endl;
cout << p2 << endl;
cout << p3 << endl;

cout << "Resulting Added Plaintext:" << endl; cout << plaintextAdd << endl;

Listing 18: Adding Ciphertexts

### 8.8 Homomorphic Multiplication of Ciphertexts

Homomorphic multiplication of two Ciphertext is performed by invoking the EvalMult method of the CryptoContext. Both of the operands to the EvalMult must have been created in the same CryptoContext, encrypted with the same Key, and encoded in the same way for this operation to work.

The code sample in listing 19 illustrates how to encode two vectors of integers into Plaintext, encrypt them into Ciphertext, perform homomorphic multiplication, and decrypt the result back into a Plaintext.

This code assumes a CryptoContext named cc and a keypair named kp.

Note the creation of an EvalMult key using EvalMultKeyGen at the beginning of the sample.

cc->EvalMultKeyGen(kp.secretKey);

// Encode source data

std::vector<int64_t> v1 = {3,2,1,3,2,1,0,0,0,0,0,0}; std::vector<int64_t> v2 = {2,0,0,0,0,0,0,0,0,0,0,0}; std::vector<int64_t> v3 = {1,0,0,0,0,0,0,0,0,0,0,0}; Plaintext p1 = cc->MakeCoefPackedPlaintext(v1); Plaintext p2 = cc->MakeCoefPackedPlaintext(v2); Plaintext p3 = cc->MakeCoefPackedPlaintext(v3);

// Encryption

auto c1 = cc->Encrypt(kp.publicKey, p1); auto c2 = cc->Encrypt(kp.publicKey, p2); auto c3 = cc->Encrypt(kp.publicKey, p2);

// EvalMult Operation

auto m12 = cc->EvalMult(c1,c2);
auto cprod = cc->EvalMult(m12,c3);

//Decryption after Multiplication Operation

Plaintext plaintextMul;

cc->Decrypt(kp.secretKey, cprod, &plaintextMul);

plaintextMul->SetLength(p1->GetLength());

cout << "Original Plaintext:" << endl; cout << p1 << endl;
cout << p2 << endl;
cout << p3 << endl;

cout << "Resulting Plaintext:" << endl; cout << plaintextMul << endl;

Listing 19: Multiplying Ciphertexts

## 9 Sample Implementations: FHE

PALISADE implements several fully homomorphic encryption schemes. Different schemes work with different input data types, and this is why this Section is organized based on three data types: integer numbers, real numbers, and binary bits (i.e., Boolean circuits). Each subsection describes which cryptographic schemes are appropriate for the respective data type, and how to start using the schemes in PALISADE.

### 9.1 Integer arithmetic

PALISADE provides two schemes that work with integer numbers, namely BFV and BGV. PALISADE includes RNS variants for both schemes. Here, we discuss BFV as an example.

In order to use BFV, users need to create a CryptoContext through the static factory method called genCryptoContextBFV. Among other arguments, this factory method takes the plaintext modulus, the security level, and the additive, multiplicative, and key-switching depths of the computation. The plaintext modulus determines an upper bound for the integer inputs in the BFV scheme. The security level is a parameter whose possible values correspond to 128-, 192-, or 256-bit security; PALISADE picks the appropriate underlying security parameters by consulting the relevant tables of the current FHE standard. Depending on the computation the user wants to carry out, she can set either the additive, multiplicative, or key-switching depth, and set all others to 0. Users who want to start using BFV can try running the examples at the following locations:

1. src/pke/examples/simple-integers.cpp - simple example showing how to instantiate the BFV scheme, generate keys, encrypt the data, perform homomorphic operations, and decrypt the result.
2. src/pke/examples/simple-integers-serial.cpp - shows how to serialize/deserialize objects when using the BFV scheme.

### 9.2 Real-number arithmetic

PALISADE supports real- and complex-number arithmetic through the use of the CKKS scheme. CKKS is implemented in RNS for better performance, so its CryptoContext can only be created with DCRTPoly as the template argument.

Creating a CryptoContext is done by an invocation of the static factory method gen-CryptoContextCKKS. Listing 20 shows all different arguments for genCryptoContextCKKS.

static CryptoContext<Element> genCryptoContextCKKS( usint multiplicativeDepth,
usint scalingFactorBits,
usint batchSize,
SecurityLevel stdLevel = HEStd_128_classic, usint ringDim = 0,
enum RescalingTechnique rsTech = EXACTRESCALE, enum KeySwitchTechnique ksTech = HYBRID, uint32_t numLargeDigits = 0,
int maxDepth = 1,
usint firstModSize = 60,
usint relinWindow = 0,
MODE mode = OPTIMIZED);

Listing 20: List of arguments of CKKS context generation method.

The CKKS scheme supports three different key switching algorithms, specifically digit decomposition by Brakerski and Vaikuntanathan (BV) [BV14], ciphertext modulus doubling by Gentry, Halevi and Smart (GHS) [GHS12], and the hybrid technique (HYBRID) [HK19] which combines ideas from the other two. Users can choose which algorithm the CKKS scheme will use by specifying the corresponding argument when creating the CryptoContext.

Besides choosing key switching algorithms, users can also choose between three variants called EXACTRESCALE, APPROXRESCALE, and APPROXAUTO. The former is simplest to use because it performs automatic rescaling, and introduces smaller rescaling error to computations of high multiplicative depth. This comes at a moderate performance cost of about 5-30% compared to APPROXRESCALE, which requires the user to track the depth of different ciphertexts and call Rescale() appropriately. The APPROXAUTO mode has the same rescaling approximation error as APPROXRESCALE but does the rescaling automatically.

CKKS provides proxy re-encryption and multiparty capabilities, but for PRE only the BV key switching algorithm is available. The multiparty capability supports all three key switching techniques.

Because of the way CKKS works, inputs have to be complex double numbers. CKKS also supports SIMD-like operations on packed data. Listing 21 shows how to create CKKS plaintexts. Users can also specify the depth and level of the plaintexts they want to create, by supplying these arguments to MakeCKKSPackedPlaintext().

vector<complex<double>> x2 = { 5.0, 4.0, 3.0, 2.0, 1.0, 0.75, 0.5, 0.25 };

Plaintext ptxt1 = cc->MakeCKKSPackedPlaintext(x1);

Listing 21: Creating a CKKS plaintext.

The best way to start working with encrypted real numbers is to read the source code and related comments of the following examples:

1. src/pke/examples/simple-real-numbers.cpp - Simple example showing how to instantiate the CKKS scheme and perform basic homomorphic operations (addition, subtraction, multiplication, rotation).
2. src/pke/examples/advanced-real-numbers.cpp - Advanced examples illustrating usage of HYBRID key switching, EXACTRESCALE versus APPROXRESCALE, and hoisted rotations.

### 9.3 Boolean Circuit Arithmetic

PALISADE provides an implementation of FHEW to evaluate homorphically arbitrary Boolean circuits. Currently, PALISADE supports only the symmetric key encryption. The binary gates that are currently supported are OR, AND, NOR, NAND, XOR, and XNOR. All these gates take the same time, and internally call bootstrapping. The unary gate NOT is also supported; it’s very fast (negligibly fast as compared to binary gate operations) and does not require any bootstrapping.

The following code samples are provided in the examples folder of the binfhe module:

1. src/binfhe/examples/boolean.cpp - simple example showing how to instantiate a BinFHEContext, generate keys, encrypt the data, evaluate a Boolean circuit, and decrypt the result.
2. src/binfhe/examples/boolean-serial-json.cpp - shows how to serialize/deserialize a crypto context, ciphertext, and keys in JSON representation. This representation is about one order of magnitude slower than the binary representation, and is typically useful only during debugging (or in special cross-platform scenarios).
3. src/binfhe/examples/boolean-serial-binary.cpp - shows how to serialize/deserialize a crypto context, ciphertext, and keys in the binary representation. This representation is recommeded for most practical scenarios.

## 10 Sample Implementations: ABE

### 10.1 Creating an ABEContext

An ABEContext can be created by either choosing the relevant security level or basic parameters related to security level.

/// Example showing creating an CP-ABE ABEContext
/// By specifying security level and number of attributes only
/// Element is NativePoly
/// First parameter is for security level, next parameter is the number of attributes

ABEContext<NativePoly> context; context.GenerateCPABEContext(HEStd_192_classic,6);

Listing 22: Creating a ABEContext with Security Level

/// Example showing creating a GPV IBE ABEContext
/// By specifying relevant parameters: ring size and base of the gadget matrix /// Element is NativePoly
/// First parameter is for ring size, second one is for base

ABEContext<NativePoly> context; context.GenerateIBEContext(1024,64);

Listing 23: Creating a ABEContext with Parameters

### 10.2 Generating Master Keys

/// Example showing master key pair generation for GPV IBE ABEContext /// Element is NativePoly

IBEMasterPublicKey<NativePoly> mpk;
IBEMasterSecretKey<NativePoly> msk; context.Setup(&mpk,&msk);

Listing 24: Generating Master Public Key Pair with ABEContext

### 10.3 Creating Access Policies

/// Example showing user identifier generation for GPV IBE ABEContext /// Element is NativePoly

IBEUserIdentifier<NativePoly> id(context.GenerateRandomElement());

Listing 25: Creating a User Identifier with GPV IBE ABEContext

/// Example showing user attribute set/access policy creating for CP-ABE ABEContext
/// Element is NativePoly

std::vector<unsigned int> userattributes = {1,0,1,0,1,1}; std::vector <int> accesspolicy = {0,-1,1,0,1,0);

CPABEUserAccess<NativePoly> ua(userattributes); CPABEAccessPolicy<NativePoly> ap(accesspolicy);
Listing 26: Creating a User Attribute Set/Access Policy with CP-ABE ABEContext

### 10.4 Key Generation

The secret key generated is tailored to the identifier or attribute set of the user

/// Example showing secret key generation for GPV IBE ABEContext
/// Element is NativePoly
/// msk is the master secret key, mpk is the master public key, id is the user identifier

IBESecretKey<NativePoly> sk;
context.KeyGen(msk,mpk,id,&sk);

Listing 27: Generating a Secret Key with ABEContext

Additionally, it is possible to split the key generation process into two phases: Online and offline. Offline phase consists of creation of perturbation vector which is independent from the user’s id or attribute set.

/// Example showing the offline phase of secret key generation for GPV IBE ABEContext
/// Element is NativePoly
/// msk is the master secret key

PerturbationVector<NativePoly> pv;
context.KeyGenOfflinePhase(msk,pv);
Listing 28: Generating a Secret Key with ABEContext (Offline Phase - Perturbation Generation)

The online phase in this scenario consists of actual key generation based on user’s id or attribute set without the perturbation subroutine.

/// Example showing the online phase of secret key generation for GPV IBE ABEContext
/// Element is NativePoly
/// msk is the master secret key, mpk is the master public key, id is the user ’s identifier and pv is the perturbation vector

IBESecretKey<NativePoly> sk;
context.KeyGenOnlinePhase(msk,mpk,id,pv,&sk);
Listing 29: Generating a Secret Key with ABEContext (Online Phase - Key Generation)

### 10.5 Encryption

A Plaintext is encrypted with a target party, which means the target user’s identifier in GPV IBE or access policy for CP-ABE.

/// Example showing encryption for CP-ABE ABEContext /// Element is NativePoly
///mpk is the master public key, ap is the access policy

///Creation of plaintext. The format is intentionally used for support std::vector<int64_t> vectorOfInts = { 1,0,0,1,1,0,1,0, 1, 0}; Plaintext pt = context.MakeCoefPackedPlaintext(vectorOfInts);

///Actual encryption
CPABECiphertext<NativePoly> ct; context.Encrypt(mpk,ap,pt,&ct);

Listing 30: Encryption with CP-ABE ABEContext

### 10.6 Decryption

/// Example showing decryption for CP-ABE ABEContext
/// Element is NativePoly
///sk is the secret key of the user, ua is the user’s attributes, ap is the access policy defined and ct is the ciphertext

Plaintext dt = context.Decrypt(ap,ua,sk,ct);

Listing 31: Decryption with CP-ABE ABEContext

/// Example showing decryption for GPV IBE ABEContext
/// Element is NativePoly
///sk is the secret key of the user and ct is the ciphertext

Plaintext dt = context.Decrypt(sk,ct);

Listing 32: Decryption with GPV IBE ABEContext

## 11 Sample Implementations: Digital Signature

### 11.1 Creating a SignatureContext

A SignatureContext can be created by either choosing one of the predefined ring sizes or a set of parameters.

/// Example showing creating a GPV SignatureContext
/// By specifying some specific parameters
/// First parameter is the ring size, second parameter is the bit width of modulus and third one is the base of the gadget matrix
/// Element is NativePoly

SignatureContext<NativePoly> context; context.GenerateGPVContext(1024,61,64);

Listing 33: Creating a SignatureContext with Parameters

### 11.2 Key Generation

/// Example showing creating sign/verification keys with a GPV SignatureContext
/// Element is NativePoly

GPVVerificationKey<NativePoly> vk; GPVSignKey<NativePoly> sk; context.KeyGen(&sk,&vk);

Listing 34: Key Generation with SignatureContext

### 11.3 Signing

/// Example showing signing with a GPV SignatureContext /// Element is NativePoly
///sk is the signing key and vk is the verification key

///Creation of plaintext
string pt = "This is a test";
GPVPlaintext<NativePoly> plaintext(pt);

///Actual signing
GPVSignature<NativePoly> signature; context.Sign(plaintext,sk,vk,&signature);

Listing 35: Signing with SignatureContext

Additionally, it is possible to split the signing process into two phases: Online and offline. Offline phase consists of creation of perturbation vector which is independent from message to be signed.

/// Example showing offline phase of signing with a GPV SignatureContext /// Element is NativePoly
///sk is the signing key

PerturbationVector<NativePoly> pv;
context.SignOfflinePhase(sk,pv);
Listing 36: Signing with SignatureContext (Offline Phase - Perturbation Generation)

The online phase in this scenario consists of actual signing process without the perturbation subroutine.

/// Example showing online phase of signing with a GPV SignatureContext /// Element is NativePoly
///sk is the signing key, vk is the verification key and pv is the perturbation vector generated in offline phase

///Creation of plaintext
string pt = "This is a test"; GPVPlaintext<NativePoly> plaintext(pt);

///Actual signing
GPVSignature<NativePoly> signature; context.SignOnlinePhase(plaintext,sk,vk,pv,&signature);
Listing 37: Signing with SignatureContext (Online Phase - Signing)

### 11.4 Verification

/// Example showing verification with a GPV SignatureContext /// Element is NativePoly
/// vk is the verification key

bool verificationResult = context.Verify(plaintext,signature,vk);

Listing 38: Verification with SignatureContext

## 12 Building and Installing PALISADE

PALISADE git repository includes an up-to-date wiki with detailed instructions on building and running PALISADE on various platforms. We use CMake to build PALISADE, and support Linux, Windows, and macOS. The library requires a C++ compiler that implements the C++11 standard, with support for the OpenMP library. Make, cmake, and autoconf also need to be installed. While not required, it is also recommended that you install and use doxygen.

## 13 Programming Style

PALISADE coding style is based on the official Google C++ coding style. (https://google.github.io/styleguide/cppguide.html)

Of particular note on the documentation style:

- We use doxygen commenting style on classes, methods and constants.
- We given meaningful variable names to all variables.
- Every reused discrete block of code has its own method.
- Every discrete line or code or discrete group of code lines for each task has its own comment.

With regards to naming conventions:

- Variable names: camelCase.
- Class, struct, typedef, and enum names: CamelCase.
- Class data members: m_camelCase.
- Class accessor names: GetProperty() and SetProperty().
- Class method names: CamelCase.
- Global variable names: g_camelCase.
- Constant names and macros: UPPER_CASE_WITH_UNDERSCORES (example: BIT_LENGTH).
- Operator overloading is used for binary operations.

We also follow the additional design principles that:

- cout should never be used for exception handling and should never be used in committed code in the core PALISADE library.
- a set of PALISADE exceptions is defined in utils/exception.h. The library is being migrated to throw only these exceptions.

## A PALISADE License

PALISADE is available under the following license:

Copyright (c) 2019, New Jersey Institute of Technology (NJIT)

All rights reserved.

Redistribution and use in source and binary forms, with or without modification, are permitted provided that the following conditions are met:

1. Redistributions of source code must retain the above copyright notice, this list of conditions and the following disclaimer.
2. Redistributions in binary form must reproduce the above copyright notice, this list of conditions and the following disclaimer in the documentation and/or other materials provided with the distribution.

THIS SOFTWARE IS PROVIDED BY THE COPYRIGHT HOLDERS AND CONTRIB-UTORS "AS IS" AND ANY EXPRESS OR IMPLIED WARRANTIES, INCLUDING, BUT NOT LIMITED TO, THE IMPLIED WARRANTIES OF MERCHANTABILITY AND FITNESS FOR A PARTICULAR PURPOSE ARE DISCLAIMED. IN NO EVENT SHALL THE COPYRIGHT HOLDER OR CONTRIBUTORS BE LIABLE FOR ANY DI-RECT, INDIRECT, INCIDENTAL, SPECIAL, EXEMPLARY, OR CONSEQUENTIAL DAMAGES (INCLUDING, BUT NOT LIMITED TO, PROCUREMENT OF SUBSTI-TUTE GOODS OR SERVICES; LOSS OF USE, DATA, OR PROFITS; OR BUSINESS IN-TERRUPTION) HOWEVER CAUSED AND ON ANY THEORY OF LIABILITY, WHETHER IN CONTRACT, STRICT LIABILITY, OR TORT (INCLUDING NEGLIGENCE OR OTH-ERWISE) ARISING IN ANY WAY OUT OF THE USE OF THIS SOFTWARE, EVEN IF ADVISED OF THE POSSIBILITY OF SUCH DAMAGE.

## B Support

The following organizations and projects have been providing generous sponsorship for the PALISADE project:

- DARPA SAFEWARE (2015-present) : Sponsored by the Defense Advanced Research Projects Agency (DARPA) and the Army Research Laboratory (ARL) under Contract Numbers W911NF-15-C-0226 and W911NF-15-C-0233. The views expressed are those of the authors and do not necessarily reflect the official policy or position of the Department of Defense or the U.S. Government.
- DARPA MARSHAL (2017-2019): Sponsored by the Defense Advanced Research Projects Agency (DARPA) and the US Navy SPAWAR Systems Center Pacific (SSCPAC) under Contract Number N66001-17-1-4043. The views expressed are those of the authors and do not necessarily reflect the official policy or position of the Department of Defense or the U.S. Government.
- NSA CAE (2015-2016) : Project sponsored by the National Security Agency under Grant H98230-15-1-0274. The United States Government is authorized to reproduce and distribute reprints notwithstanding any copyright notice herein.
- IARPA RAMPARTS (2016-2018) : This research is based upon work supported in part by the Office of the Director of National Intelligence (ODNI), Intelligence Advanced Research Projects Activity (IARPA). The views and conclusions contained herein are those of the authors and should not be interpreted as necessarily representing the official policies, either express or implied, of ODNI, IARPA, or the U.S. Government. The U.S. Government is authorized to reproduce and distribute reprints for governmental purposes notwithstanding any copyright annotation therein.
- NIH SBIR GEARS (2017-2018): Research reported in this publication was supported by National Human Genome Research Institute of the National Institutes of Health under award number 1R43HG010123.
- Simons Foundation (2015-2016)
- Sloan Foundation (2017-present)

## References

[BEHZ16] Jean-Claude Bajard, Julien Eynard, M Anwar Hasan, and Vincent Zucca. A full rns variant of fv like somewhat homomorphic encryption schemes. In International Conference on Selected Areas in Cryptography, pages 423–442. Springer, 2016.

[BGP⁺19] Marcelo Blatt, Alexander Gusev, Yuriy Polyakov, Kurt Rohloff, and Vinod Vaikuntanathan. Optimized homomorphic encryption solution for secure genomewide association studies. Cryptology ePrint Archive, Report 2019/223, 2019.
https://eprint.iacr.org/2019/223.

[BGV14] Zvika Brakerski, Craig Gentry, and Vinod Vaikuntanathan. (leveled) fully homomorphic encryption without bootstrapping. ACM Transactions on Computation Theory (TOCT), 6(3):13, 2014.

[BPA⁺18] Ahmad Al Badawi, Yuriy Polyakov, Khin Mi Mi Aung, Bharadwaj Veeravalli, and Kurt Rohloff. Implementation and performance evaluation of rns variants of the bfv homomorphic encryption scheme. Cryptology ePrint Archive, Report
2018/589, 2018. https://eprint.iacr.org/2018/589.
[Bra12] | Zvika Brakerski. Fully homomorphic encryption without modulus switching from classical gapsvp. In Advances in Cryptology–CRYPTO 2012, pages 868–886. Springer, 2012.
[BV14] | Zvika Brakerski and Vinod Vaikuntanathan. Efficient fully homomorphic encryp- tion from (standard) lwe. SIAM Journal on Computing, 43(2):831–871, 2014.

[CGGI18] Ilaria Chillotti, Nicolas Gama, Mariya Georgieva, and Malika Izabachène. TFHE:
| fast fully homomorphic encryption over the torus. IACR Cryptology ePrint Archive, 2018:421, 2018.

[CHK⁺18] Jung Hee Cheon, Kyoohyung Han, Andrey Kim, Miran Kim, and Yongsoo Song.
| A full rns variant of approximate homomorphic encryption. Cryptology ePrint Archive, Report 2018/931, 2018. https://eprint.iacr.org/2018/931.

[CKKS16] Jung Hee Cheon, Andrey Kim, Miran Kim, and Yongsoo Song. Homomorphic
| encryption for arithmetic of approximate numbers. Cryptology ePrint Archive, Report 2016/421, 2016. https://eprint.iacr.org/2016/421.
[Coh17] | Aloni Cohen. What about bob? the inadequacy of cpa security for proxy reencryption. Cryptology ePrint Archive, Report 2017/785, 2017. https: //eprint.iacr.org/2017/785.
[DM14] | Léo Ducas and Daniele Micciancio. Fhew: Bootstrapping homomorphic encryp- tion in less than a second. Cryptology ePrint Archive, Report 2014/816, 2014. https://eprint.iacr.org/2014/816.

[FV12] | Junfeng Fan and Frederik Vercauteren. Somewhat practical fully homomorphic encryption. IACR Cryptology ePrint Archive, 2012:144, 2012.
[GHS12] | Craig Gentry, Shai Halevi, and Nigel P Smart. Homomorphic evaluation of the aes circuit. In Advances in Cryptology–CRYPTO 2012, pages 850–867. Springer,
| 2012.

[GINX16] Nicolas Gama, Malika Izabachène, Phong Q. Nguyen, and Xiang Xie. Struc-
| tural lattice reduction: Generalized worst-case to average-case reductions and homomorphic cryptosystems. In Advances in Cryptology - EUROCRYPT 2016 - 35th Annual International Conference on the Theory and Applications of Cryp- tographic Techniques, Vienna, Austria, May 8-12, 2016, Proceedings, Part II, pages 528–558, 2016.

[GPR⁺17] Kamil Doruk Gür, Yuriy Polyakov, Kurt Rohloff, Gerard W. Ryan, Hadi Saj-
| jadpour, and Erkay Savaş. Practical applications of improved gaussian sam- pling for trapdoor lattices. Cryptology ePrint Archive, Report 2017/1254, 2017. https://eprint.iacr.org/2017/1254.

[GPV08] Craig Gentry, Chris Peikert, and Vinod Vaikuntanathan. Trapdoors for hard
| lattices and new cryptographic constructions. In STOC, pages 197–206, 2008.
[HK19] | Kyoohyung Han and Dohyeong Ki. Better bootstrapping for approximate ho- momorphic encryption. Cryptology ePrint Archive, Report 2019/688, 2019. https://eprint.iacr.org/2019/688.
[HPS18] | Shai Halevi, Yuriy Polyakov, and Victor Shoup. An improved rns variant of the bfv homomorphic encryption scheme. 2018. https://eprint.iacr.org/ 2018/117. (https://eprint.iacr.org/2018/117)

[KPP20] Andrey Kim, Antonis Papadimitriou, and Yuriy Polyakov. A more usable RNS
| variant of CKKS homomorphic encryption scheme, 2020. in preparation.
[KPZ20] | Andrey Kim, Yuriy Polyakov, and Vincent Zucca. A more usable RNS variant of BGV homomorphic encryption scheme, 2020. in preparation.
[LN14] | Tancrede Lepoint and Michael Naehrig. A comparison of the homomorphic en- cryption schemes fv and yashe. In International Conference on Cryptology in Africa, pages 318–335. Springer, 2014.
[MP20] | Daniele Micciancio and Yuriy Polyakov. Bootstrapping in fhew-like cryptosys- tems. Cryptology ePrint Archive, Report 2020/086, 2020. https://eprint. iacr.org/2020/086. (https://eprint.iacr.org/2020/086)
[SS11] | Damien Stehlé and Ron Steinfeld. Making ntru as secure as worst-case problems over ideal lattices. In KennethG. Paterson, editor, Advances in Cryptology – EUROCRYPT 2011, volume 6632 of Lecture Notes in Computer Science, pages 27–47. Springer Berlin Heidelberg, 2011.
[ZZG12] | Jiang Zhang, Zhenfeng Zhang, and Aijun Ge. Ciphertext policy attribute-based encryption from lattices. In Heung Youl Youm and Yoojae Won, editors, 7th ACM

Symposium on Information, Compuer and Communications Security, ASIACCS ’12, Seoul, Korea, May 2-4, 2012, pages 16–17. ACM, 2012.

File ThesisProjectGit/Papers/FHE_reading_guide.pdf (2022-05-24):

# FHE reading guide

August 26, 2020

Vinod Vaikuntanathan and Daniele Micciancio both keep a webpage with important (theoretical) FHE papers https://people.csail.mit.edu/vinodv/FHE/FHE-refs.html (https://people.csail.mit.edu/vinodv/FHE/FHE-refs.html) & http://cseweb.ucsd.edu/~daniele/LatticeLinks/FHE.html. (http://cseweb.ucsd.edu/~daniele/LatticeLinks/FHE.html) The following ones are ones I am reading, I tried to substitute theoretical papers with ones that look at the schemes from an implementational point of view wherever possible.

## 1 Papers

### 1.1 Pre-FHE & Gen-I FHE

This is mostly historical. The assumptions and techniques used are different than those used today, and these schemes are very inefficient.

### 1.2 Gen-II FHE

These are still widely-used and implemented. They are based on (R)LWE assumptions.

- BGV [BGV12] (based on ideas from [BV11])
- (B)FV [FV12] (a port from LWE to RLWE of [Bra12])

These schemes allow packing (also batching, SIMD) of multiple plaintexts in ciphertext slots for higher throughput. There is an approach based on the CRT for RLWE schemes [SV14] and a different approach for LWE schemes [BGH12].

1

BGV was used to homomorphically evaluate the AES circuit [GHS12]. The paper describes some optimisations of BGV that are implemented in most libraries.

There are two separate approaches to implement (B)FV in full-RNS representation. This paper [BPA⁺18] talks about implementing both of them in PAL-ISADE.

The LTV [LATV12] and YASHE [BLLN13] second generation schemes based on NTRU were quite popular as well, but have since been broken. This paper [LN14] compares (B)FV with YASHE from an implementational point of view.

### 1.3 Gen-III FHE

The third-generation starts with GSW, which uses a different approach than the second-generation schemes. GSW is quite inefficient, but remarkably simple and allows advanced constructions. GSW is often used in tutorials on FHE due to its simplicity. GSW ciphertexts are used by FHEW and TFHE during bootstrapping.

FHEW introduced the ”gate bootstrapping” idea which allows for fast bootstrapping by bootstrapping after every single gate. In a way, TFHE can be seen as porting FHEW, which uses both normal LWE and ring-GSW, to the Torus. One of the merits of FHEW is that is quite easy to understand and implement, whereas TFHE appears to be much more complicated.

- GSW [GSW13]
- FHEW [DM15]
- TFHE ([CGGI18], journal version combining multiple works)

A recent paper compares FHEW with TFHE (if TFHE would use the ternary instead of binary secrets) and implements this in PALISADE [MP20]. The PALISADE team seems really opposed to the binary secret distribution used in TFHE.

### 1.4 Gen-IV FHE

The HEAAN/CKKS approach [CKKS17], which encrypts approximate numbers, is either seen as a new generation or a variant of Gen-II.

There have been several RNS and bootstrapping optimisations [CHK⁺18, CHK⁺19, CCS19].

2

## 2 Tutorials

There are a number of more tutorial-like resources for FHE.

The most extensive one is probably this one from Halevi [Hal17], it describes GSW in detail. There is also this overview by Brakerski [Bra], also describes GSW in detail. There is this general introduction to lattice-based crypto from Peikert [Pei16], also describes GSW near the end.

### 2.1 Videos

There are a lot of video lectures and seminars on FHE out there. Some of the best ones I found.

- The videos from the Simons lattice semester in 2020. They are quite down-to-earth.

– A talk about BV11 (the precursor of BGV) (https://simons.berkeley.edu/talks/advanced-lattice-based-cryptography-fheabe-etc) (https://simons.berkeley.edu/talks/advanced-lattice-based-cryptography-fhe-abe-etc)

– Tutorial on GSW (https://simons.berkeley.edu/talks/tutori al-encrypted-computation-lattices) (https://simons.berkeley.edu/talks/tutorial-encrypted-computation-lattices)

– Ilaria on FHE and TFHE (https://simons.berkeley.edu/talks/intro-fhe-and-tfhe) (https://simons.berkeley.edu/talks/intro-fhe-and-tfhe)

– CKKS/HEAAN (https://simons.berkeley.edu/talks/heaan-fh
e) (https://simons.berkeley.edu/talks/heaan-fhe)

– PALISADE (https://simons.berkeley.edu/talks/palisade-l attice-library) (https://simons.berkeley.edu/talks/palisade-lattice-library)

– ... much more on lattice-based crypto

- See (http://cseweb.ucsd.edu/~daniele/LatticeLinks/FHE.html, at the bottom) for a collection of more videos.

## 3 Standard

The FHE standard describes BGV, (B)FV and GSW https://homomorphicencryption.org/standard/. (https://homomorphicencryption.org/standard/)

3

## 4 Libraries

A full list of all the FHE libraries is maintained here [Sch19]. Looking at the manual of the libraries can sometimes quickly give you an understanding of the implementational aspects of a scheme. These are the most popular ones.

- Microsoft SEAL implements BFV and CKKS. There is only a real manual for an older version 2.3.1 of the library [Lai]
- HElib implements BGV and CKKS. Comes with two reports that describe the algorithms and bootstrapping used in the library [HS14a, HS14b]
- PALISADE implements BFV, BGV, CKKS, TFHE, FHEW. There is a manual at [noaa]
- FHEW. This is more like a proof-of-concept. It is a very small library, due to the simplicity of FHEW. [Duc20]
- TFHE [noab]

## 5 Hardware

The following is copied from my FWO proposal.

Naturally, the first FHE hardware architectures implement first-generation FHE schemes. Cao et al. [CMO⁺14] implement a variant of the van Dijk scheme using integer-NTT on FPGA, but assume unlimited bandwidth to off-chip memory. Wang et al. develop a 768K-bit multiplier¹
for a variant of Gentry’s scheme and implement the result on both FPGA and ASIC [WH13, WHEW14]. Doröz et al. similarly proposed a million-bit integer multiplier [D13], and integrate it into an ASIC implementation of the same scheme [D15]. There are several implementations of the second-generation NTRU-based YASHE and LTV schemes [SRJV⁺15, PNPM15, DS15, CRS17], but the underlying FHE schemes have since been broken.

(R)LWE-based implementations remain secure to date. Migliore et al. [MSR⁺17] implemented a Karatsuba variant of the second-generation FV scheme. While computationally slower than NTT, this approach benefits from easier integration of second-generation packing techniques. The design is presented as a software library using AVX2 instructions, coupled with a fully pipelined hardware accelerator over PCIe. In a series of two works, Roy et al. [SRJV⁺18, SRTJ⁺19] accelerate the NTT variant of FV. The first work targets a large parameter

1The multiplier can take inputs up to 2⁷⁶⁸. In comparison, modern CPUs can efficiently handle inputs up to 2⁶⁴

4

set, incurring massive off-chip data transfers. In the second work, the authors target less complex cloud applications, such that sufficient on-chip memory is available and data transfers are minimized. This last design is implemented on an ARM+FPGA MPSoC. Finally, HEAX [RLPD19] is an NTT implementation of HEAAN on FPGA. The employed platform connects a host CPU and FPGA over PCIe, as well as requiring off-chip DRAM memory. To the best of our knowledge, no hardware implementations of third-generation schemes have appeared in the open literature.

## References

[BGH12] | Zvika Brakerski, Craig Gentry, and Shai Halevi. Packed Cipher- texts in LWE-based Homomorphic Encryption. Technical Report 565, 2012.
[BGV12] | Zvika Brakerski, Craig Gentry, and Vinod Vaikuntanathan. (Lev- eled) Fully Homomorphic Encryption Without Bootstrapping. In Proceedings of the 3rd Innovations in Theoretical Computer Sci- ence Conference, ITCS ’12, pages 309–325, New York, NY, USA, 2012. ACM. event-place: Cambridge, Massachusetts.
[BLLN13] | Joppe W. Bos, Kristin Lauter, Jake Loftus, and Michael Naehrig. Improved Security for a Ring-Based Fully Homomorphic Encryp- tion Scheme. In Martijn Stam, editor, Cryptography and Coding, Lecture Notes in Computer Science, pages 45–64, Berlin, Heidel- berg, 2013. Springer.
[BPA⁺18] | Ahmad Al Badawi, Yuriy Polyakov, Khin Mi Mi Aung, Bharad- waj Veeravalli, and Kurt Rohloff. Implementation and perfor- mance evaluation of rns variants of the bfv homomorphic encryp- tion scheme. Cryptology ePrint Archive, Report 2018/589, 2018. https://eprint.iacr.org/2018/589.
[Bra] | Brakerski. Fundamentals of Fully Homomorphic Encryption. Tech- nical report.
[Bra12] | Zvika Brakerski. Fully Homomorphic Encryption without Modulus Switching from Classical GapSVP. In Reihaneh Safavi-Naini and Ran Canetti, editors, Advances in Cryptology – CRYPTO 2012, Lecture Notes in Computer Science, pages 868–886, Berlin, Heidel- berg, 2012. Springer.
[BV11] | Zvika Brakerski and Vinod Vaikuntanathan. Efficient Fully Homo- morphic Encryption from (Standard) LWE. In 2011 IEEE 52nd Annual Symposium on Foundations of Computer Science, pages 97–106, October 2011. ISSN: 0272-5428.

5

[CCS19] | Hao Chen, Ilaria Chillotti, and Yongsoo Song. Improved Boot- strapping for Approximate Homomorphic Encryption. In Yuval Ishai and Vincent Rijmen, editors, Advances in Cryptology – EU- ROCRYPT 2019, Lecture Notes in Computer Science, pages 34–54, Cham, 2019. Springer International Publishing.
[CGGI18] | Ilaria Chillotti, Nicolas Gama, Mariya Georgieva, and Malika Iz- abachène. TFHE: Fast Fully Homomorphic Encryption over the Torus. Technical Report 421, 2018.

[CHK⁺18] Jung Hee Cheon, Kyoohyung Han, Andrey Kim, Miran Kim, and
| Yongsoo Song. Bootstrapping for Approximate Homomorphic En- cryption. In Jesper Buus Nielsen and Vincent Rijmen, editors, Advances in Cryptology – EUROCRYPT 2018, Lecture Notes in Computer Science, pages 360–384, Cham, 2018. Springer Interna- tional Publishing.

[CHK⁺19] Jung Hee Cheon, Kyoohyung Han, Andrey Kim, Miran Kim, and
| Yongsoo Song. A Full RNS Variant of Approximate Homomorphic Encryption. In Carlos Cid and Michael J. Jacobson Jr., editors, Selected Areas in Cryptography – SAC 2018, Lecture Notes in Com- puter Science, pages 347–368, Cham, 2019. Springer International Publishing.

[CKKS17] Jung Hee Cheon, Andrey Kim, Miran Kim, and Yongsoo Song. Ho-
| momorphic Encryption for Arithmetic of Approximate Numbers. In Tsuyoshi Takagi and Thomas Peyrin, editors, Advances in Cryp- tology – ASIACRYPT 2017, Lecture Notes in Computer Science, pages 409–437, Cham, 2017. Springer International Publishing.

[CMO⁺14] Xiaolin Cao, Ciara Moore, Máire O’Neill, Neil Hanley, and Eliza-
| beth O’Sullivan. High-Speed Fully Homomorphic Encryption Over the Integers. In Rainer Böhme, Michael Brenner, Tyler Moore, and Matthew Smith, editors, Financial Cryptography and Data Secu- rity, Lecture Notes in Computer Science, pages 169–180, Berlin, Heidelberg, 2014. Springer.
[CRS17] | David Bruce Cousins, Kurt Rohloff, and Daniel Sumorok. Design- ing an FPGA-Accelerated Homomorphic Encryption Co-Processor. IEEE Transactions on Emerging Topics in Computing, 5(2):193– 206, April 2017.
[DM15] | Léo Ducas and Daniele Micciancio. FHEW: Bootstrapping Ho- momorphic Encryption in Less Than a Second. In Elisabeth Os- wald and Marc Fischlin, editors, Advances in Cryptology – EURO- CRYPT 2015, Lecture Notes in Computer Science, pages 617–640, Berlin, Heidelberg, 2015. Springer.

6

[Duc20] Léo Ducas. lducas/FHEW, July 2020. original-date: 2014-12-03T22:07:13Z.

[D13] | Yarkin Doröz, Erdinç Oztürk, and Berk Sunar. Evaluating the ¨
Hardware Performance of a Million-Bit Multiplier. In 2013 Euromicro Conference on Digital System Design, pages 955–962, Septem-
| ber 2013. ISSN: null.
[D15] | Yarkın Doröz, Erdinç Oztürk, and Berk Sunar. Accelerating Fully ¨
Homomorphic Encryption in Hardware. IEEE Transactions on
| Computers, 64(6):1509–1521, June 2015.
[DS15] | Yarkın Doröz, Erdinç Oztürk, Erkay Savaş, and Berk Sunar. Ac- ¨
celerating LTV Based Homomorphic Encryption in Reconfigurable Hardware. In Tim Güneysu and Helena Handschuh, editors, Cryptographic Hardware and Embedded Systems – CHES 2015, Lecture Notes in Computer Science, pages 185–204, Berlin, Heidelberg,
| 2015. Springer.
[FV12] | Junfeng Fan and Frederik Vercauteren. Somewhat Practical Fully
Homomorphic Encryption. Technical Report 144, 2012.

[GHS12] Craig Gentry, Shai Halevi, and Nigel P. Smart. Homomorphic Evaluation of the AES Circuit. In Reihaneh Safavi-Naini and Ran Canetti, editors, Advances in Cryptology – CRYPTO 2012, Lecture Notes in Computer Science, pages 850–867, Berlin, Heidelberg,
| 2012. Springer.
[GSW13] | Craig Gentry, Amit Sahai, and Brent Waters. | Homomorphic
Encryption from Learning with Errors: Conceptually-Simpler, Asymptotically-Faster, Attribute-Based. In Ran Canetti and Juan A. Garay, editors, Advances in Cryptology – CRYPTO 2013, Lecture Notes in Computer Science, pages 75–92, Berlin, Heidel-
| berg, 2013. Springer.
[Hal17] | Shai Halevi. Homomorphic Encryption. In Yehuda Lindell, editor,
Tutorials on the Foundations of Cryptography: Dedicated to Oded Goldreich, Information Security and Cryptography, pages 219–276.
| Springer International Publishing, Cham, 2017.
[HS14a] | Shai Halevi and Victor Shoup. Algorithms in HElib. In Juan A.
Garay and Rosario Gennaro, editors, Advances in Cryptology – CRYPTO 2014, Lecture Notes in Computer Science, pages 554–
| 571, Berlin, Heidelberg, 2014. Springer.
[HS14b] | Shai Halevi and Victor Shoup. Bootstrapping for HElib. Technical
| Report 873, 2014.
[Lai] | Kim Laine. Simple Encrypted Arithmetic Library 2.3. page 34.

7

[LATV12] Adriana López-Alt, Eran Tromer, and Vinod Vaikuntanathan. Onthe-fly Multiparty Computation on the Cloud via Multikey Fully Homomorphic Encryption. In Proceedings of the Forty-fourth Annual ACM Symposium on Theory of Computing, STOC ’12, pages 1219–1234, New York, NY, USA, 2012. ACM. event-place: New York, New York, USA.

[LN14] Tancrède Lepoint and Michael Naehrig. A Comparison of the Homomorphic Encryption Schemes FV and YASHE. Technical Report 062, 2014.

[MP20] Daniele Micciancio and Yuriy Polyakov. Bootstrapping in FHEWlike Cryptosystems. Technical Report 086, 2020.

[MSR⁺17] Vincent Migliore, Cédric Seguin, Maria Méndez Real, Vianney Lapotre, Arnaud Tisserand, Caroline Fontaine, Guy Gogniat, and Russell Tessier. A High-Speed Accelerator for Homomorphic Encryption using the Karatsuba Algorithm. ACM Transactions on Embedded Computing Systems (TECS), 16(5s):138:1–138:17, September 2017.

[noaa] | doc/palisade manual.pdf · release-v1.10.2 · PALISADE / PAL-
ISADE Development. Library Catalog: gitlab.com.
[noab] | TFHE Fast Fully Homomorphic Encryption over the Torus.
[Pei16] | Chris Peikert. A Decade of Lattice Cryptography. Foundations and
Trends

R in Theoretical Computer Science, 10(4):283–424, 2016.

[PNPM15] Thomas Pöppelmann, Michael Naehrig, Andrew Putnam, and Adrian Macias. Accelerating Homomorphic Evaluation on Reconfigurable Hardware. In Tim Güneysu and Helena Handschuh, editors, Cryptographic Hardware and Embedded Systems – CHES 2015, Lecture Notes in Computer Science, pages 143–163, Berlin, Heidelberg, 2015. Springer.

[RLPD19] M. Sadegh Riazi, Kim Laine, Blake Pelton, and Wei Dai. HEAX: High-Performance Architecture for Computation on Homomorphically Encrypted Data in the Cloud. arXiv:1909.09731 [cs], September 2019. arXiv: 1909.09731.

[Sch19] Jonathan Schneider. Awesome HE : Homomorphic Encryption Libraries, Software and Resources, November 2019. original-date: 2018-02-21T02:38:07Z.

[SRJV⁺15] Sujoy Sinha Roy, Kimmo Järvinen, Frederik Vercauteren, Vassil Dimitrov, and Ingrid Verbauwhede. Modular Hardware Architecture for Somewhat Homomorphic Function Evaluation. In Tim Güneysu and Helena Handschuh, editors, Cryptographic Hardware

8

and Embedded Systems – CHES 2015, Lecture Notes in Computer Science, pages 164–184, Berlin, Heidelberg, 2015. Springer.

[SRJV⁺18] Sujoy Sinha Roy, Kimmo Järvinen, Jo Vliegen, Frederik Vercauteren, and Ingrid Verbauwhede. HEPCloud: An FPGA-Based Multicore Processor for FV Somewhat Homomorphic Function Evaluation. IEEE Transactions on Computers, 67(11):1637–1650, November 2018.

[SRTJ⁺19] Sujoy Sinha Roy, Furkan Turan, Kimmo Jarvinen, Frederik Vercauteren, and Ingrid Verbauwhede. FPGA-Based High-Performance Parallel Architecture for Homomorphic Computing on Encrypted Data. In 2019 IEEE International Symposium on High Performance Computer Architecture (HPCA), pages 387–398, February 2019. ISSN: 1530-0897.

[SV14] N. P. Smart and F. Vercauteren. Fully homomorphic SIMD operations. Designs, Codes and Cryptography, 71(1):57–81, April 2014.

[WH13] Wei Wang and Xinming Huang. FPGA implementation of a large-number multiplier for fully homomorphic encryption. In 2013 IEEE International Symposium on Circuits and Systems (ISCAS), pages 2589–2592, May 2013. ISSN: 2158-1525.

[WHEW14] Wei Wang, Xinming Huang, Niall Emmart, and Charles Weems. VLSI Design of a Large-Number Multiplier for Fully Homomorphic Encryption. IEEE Transactions on Very Large Scale Integration (VLSI) Systems, 22(9):1879–1887, September 2014.

9

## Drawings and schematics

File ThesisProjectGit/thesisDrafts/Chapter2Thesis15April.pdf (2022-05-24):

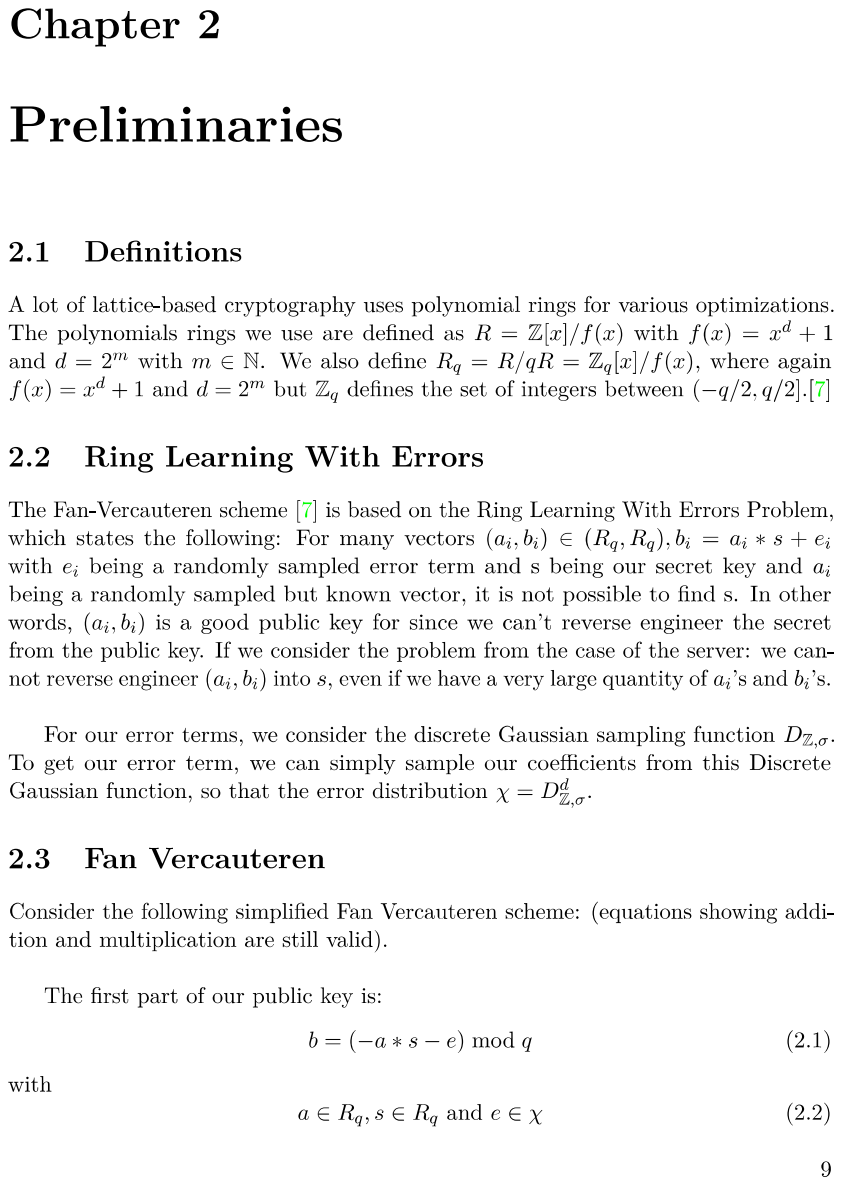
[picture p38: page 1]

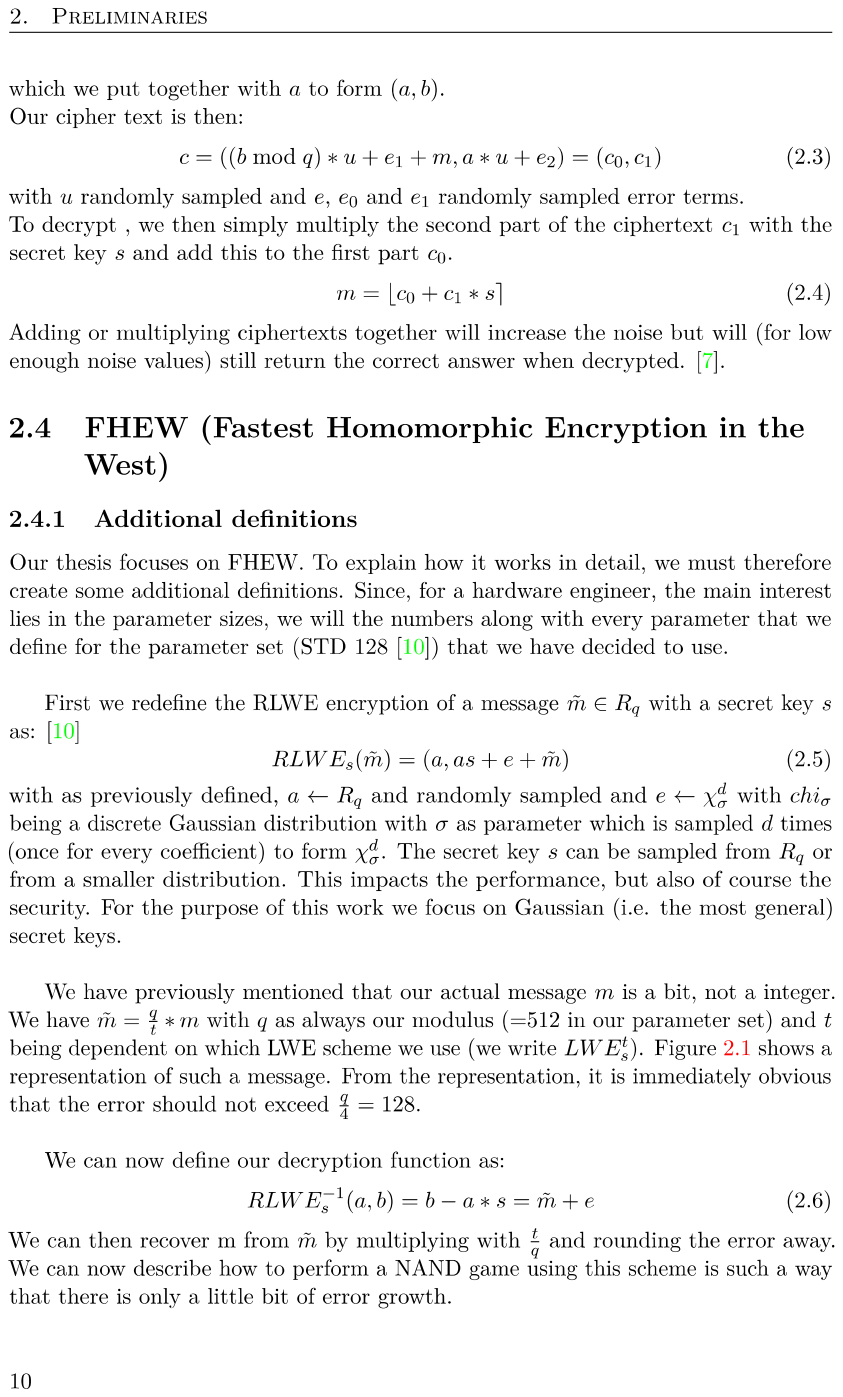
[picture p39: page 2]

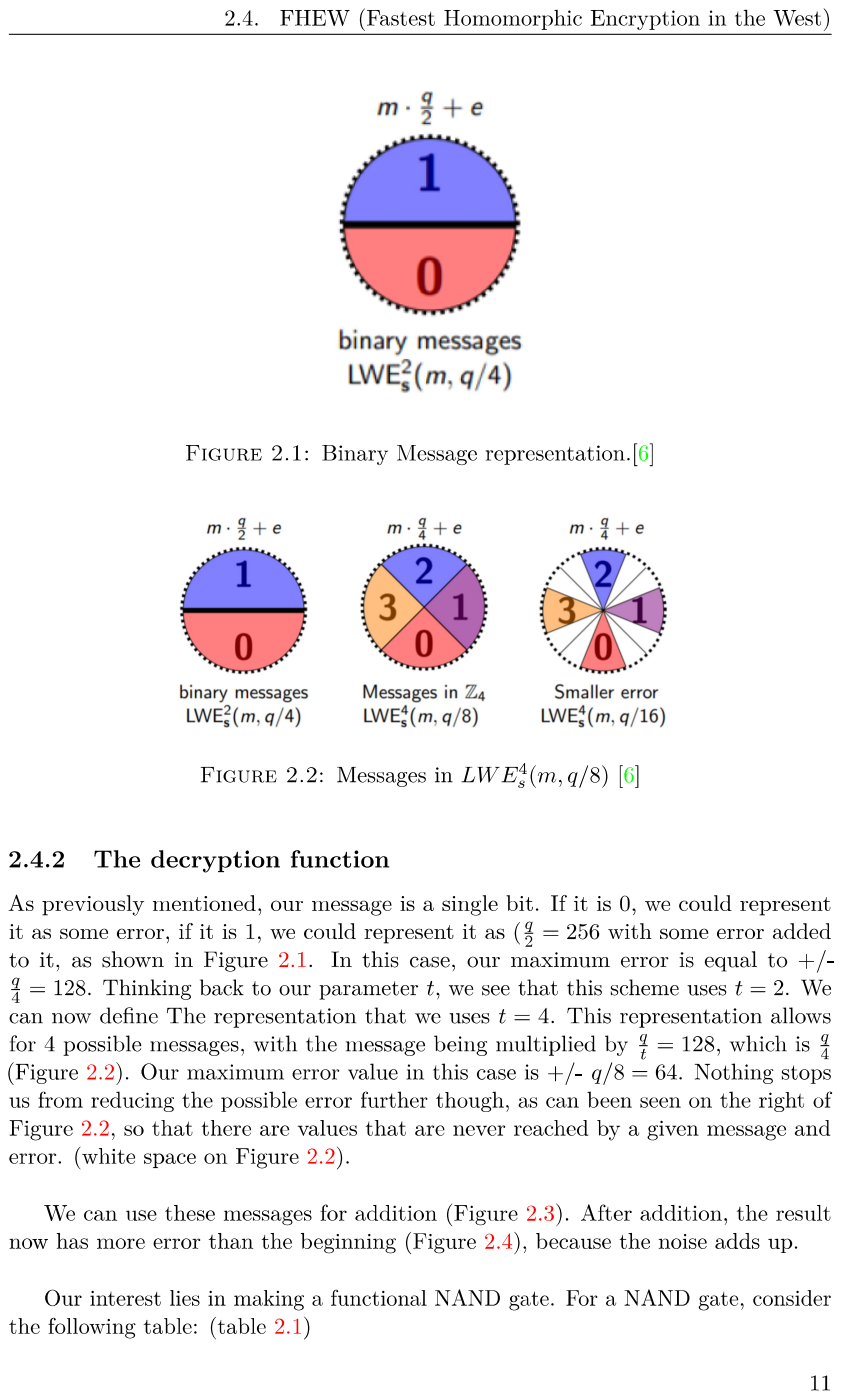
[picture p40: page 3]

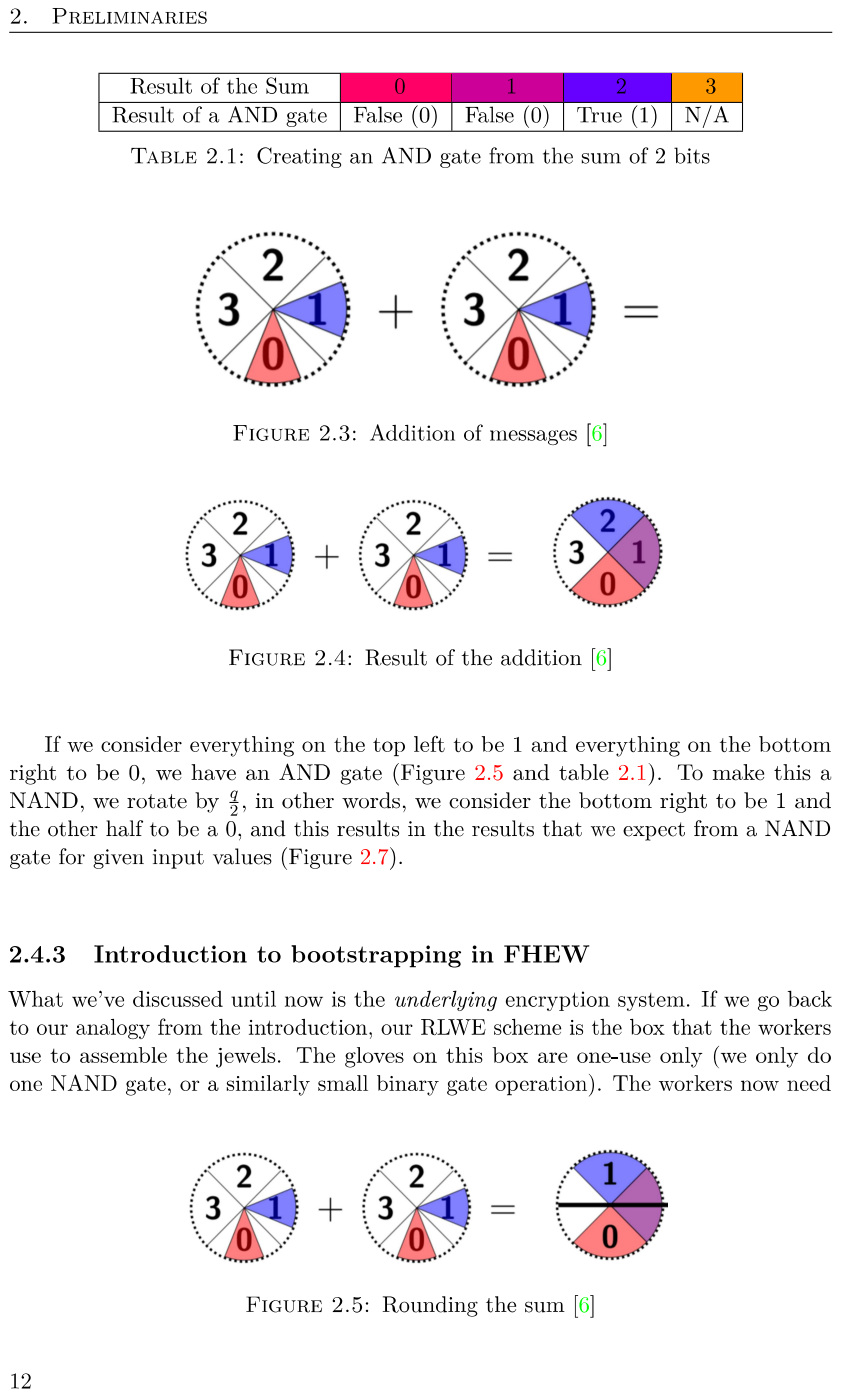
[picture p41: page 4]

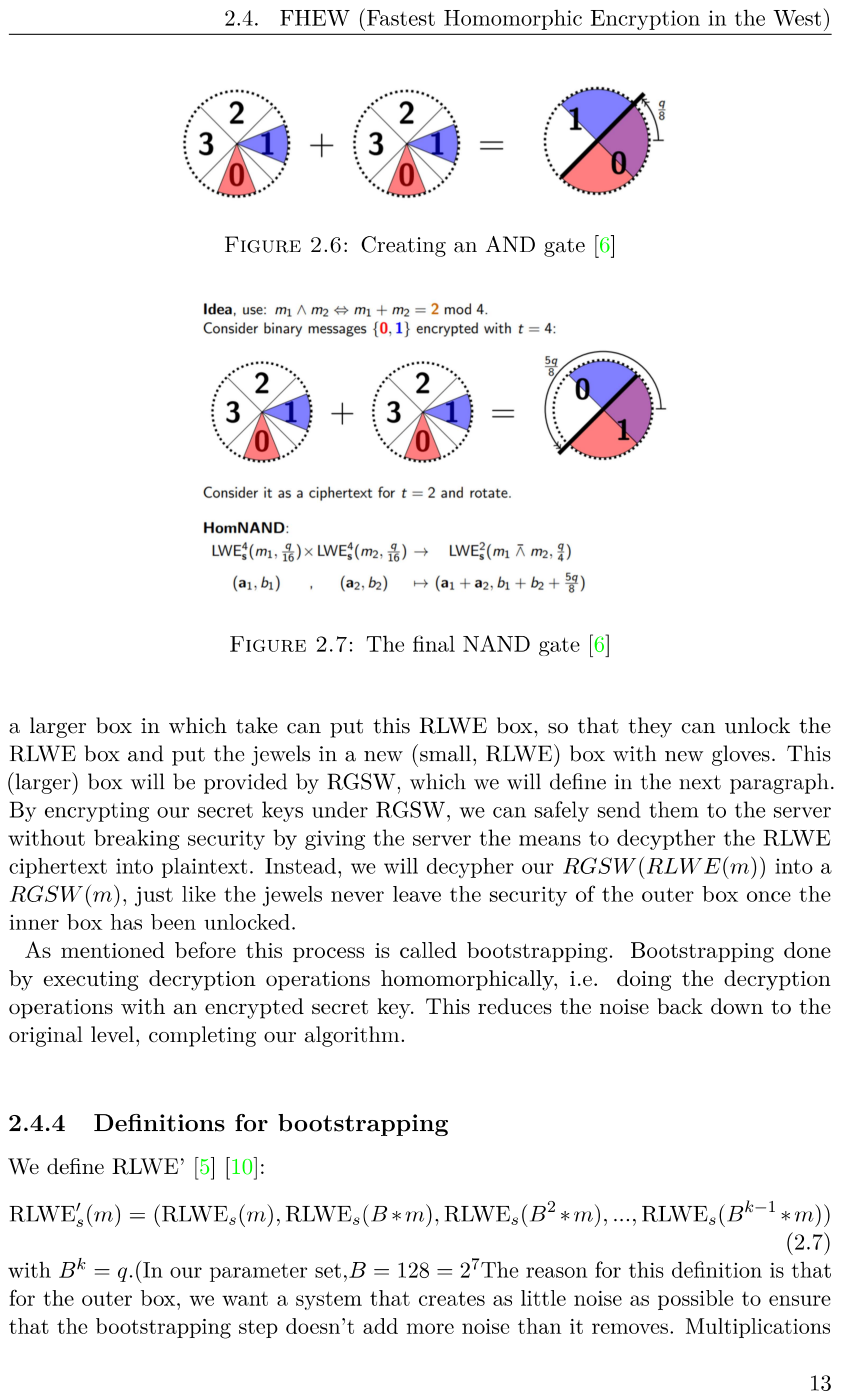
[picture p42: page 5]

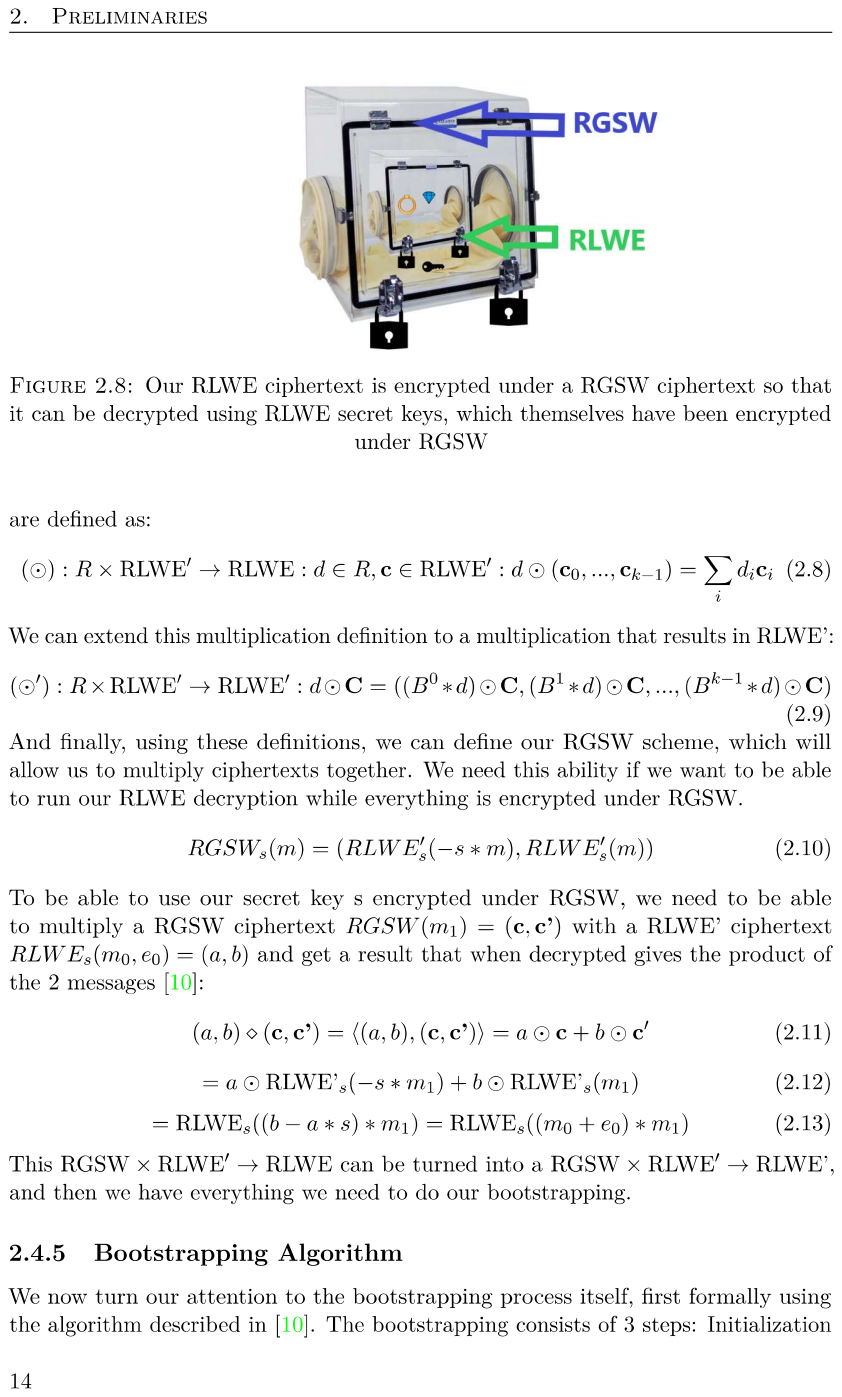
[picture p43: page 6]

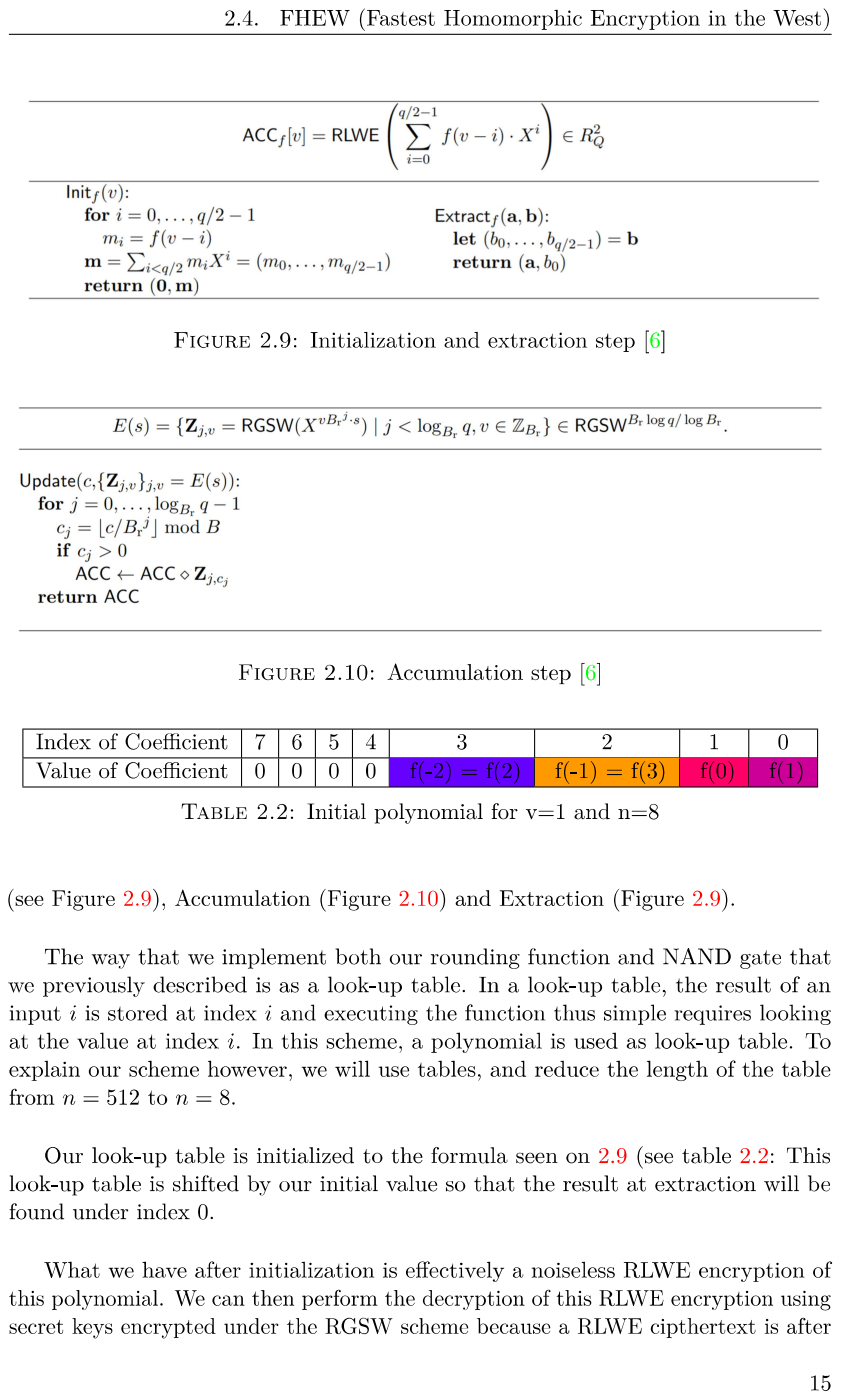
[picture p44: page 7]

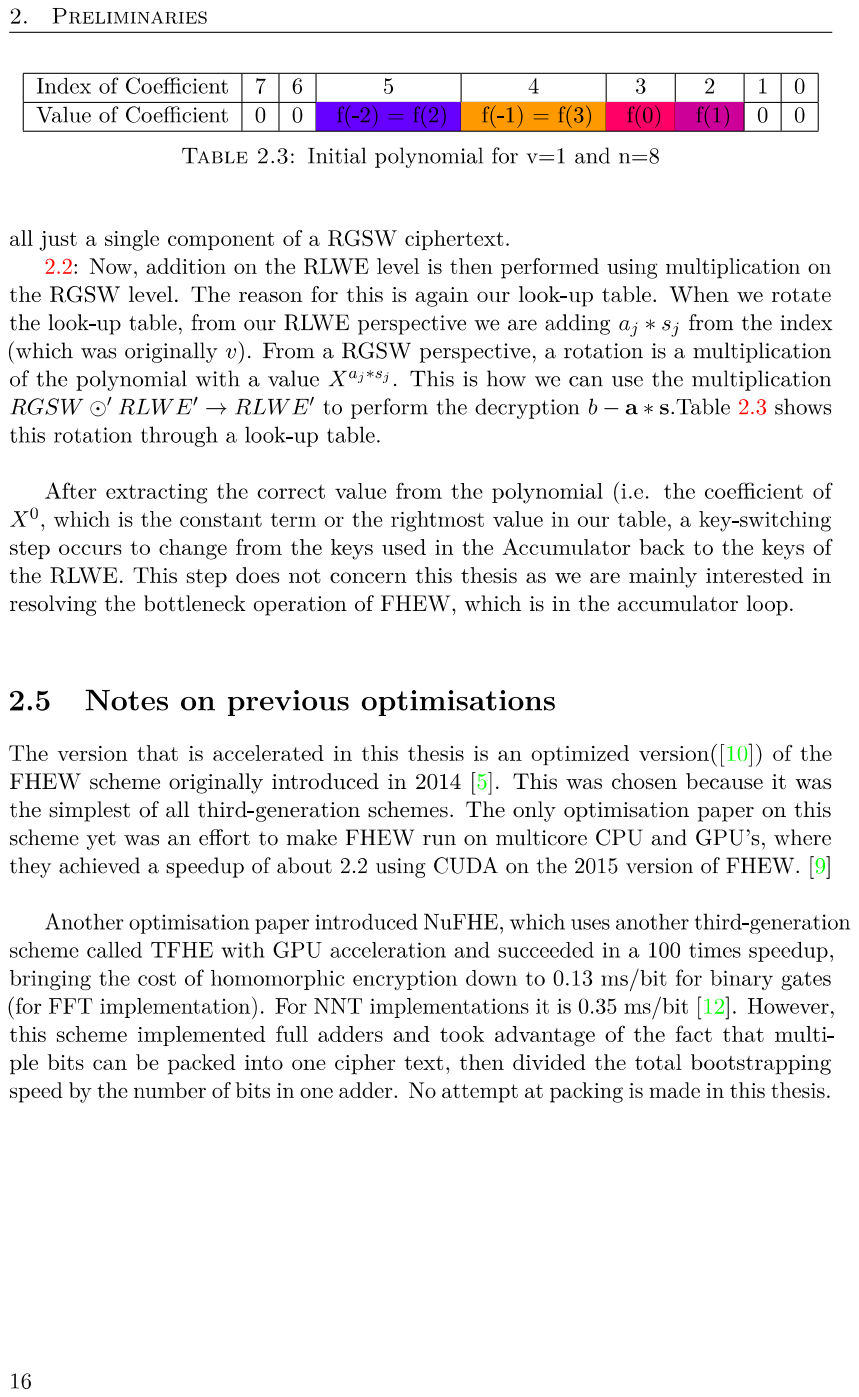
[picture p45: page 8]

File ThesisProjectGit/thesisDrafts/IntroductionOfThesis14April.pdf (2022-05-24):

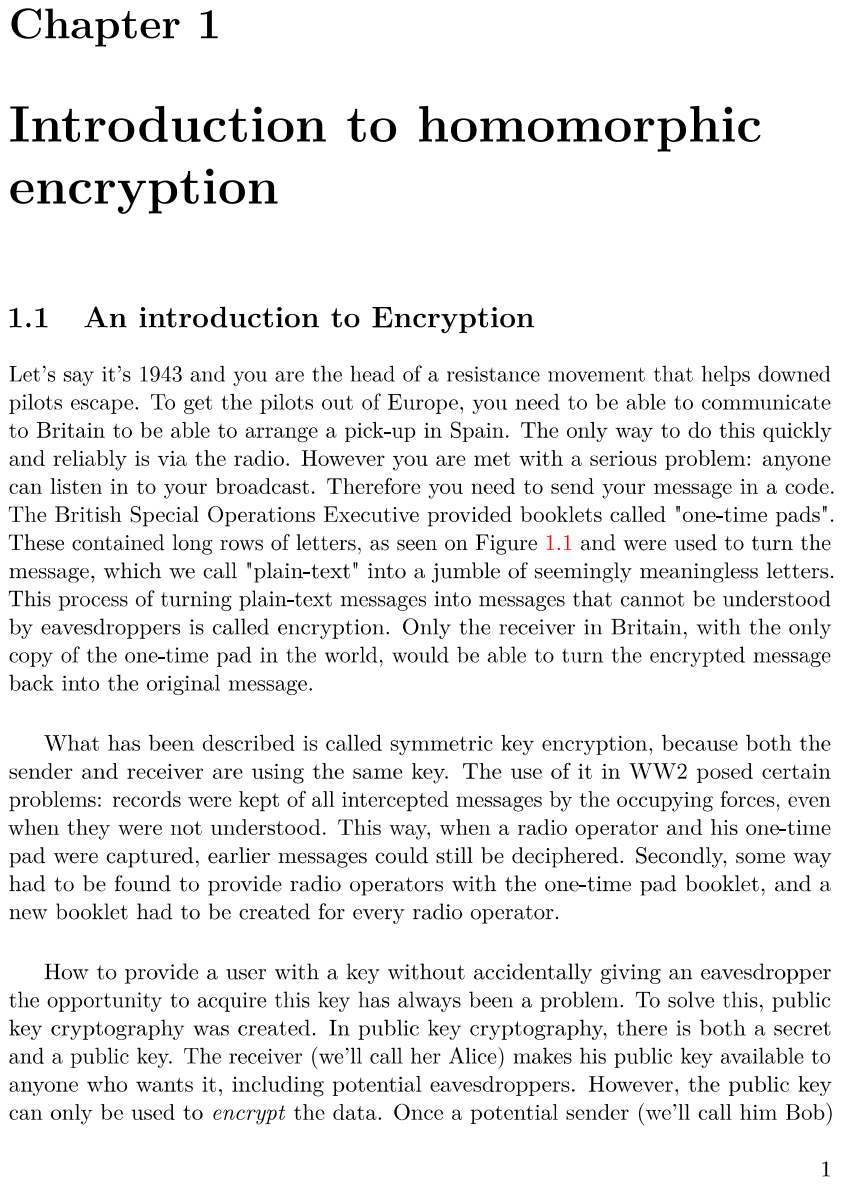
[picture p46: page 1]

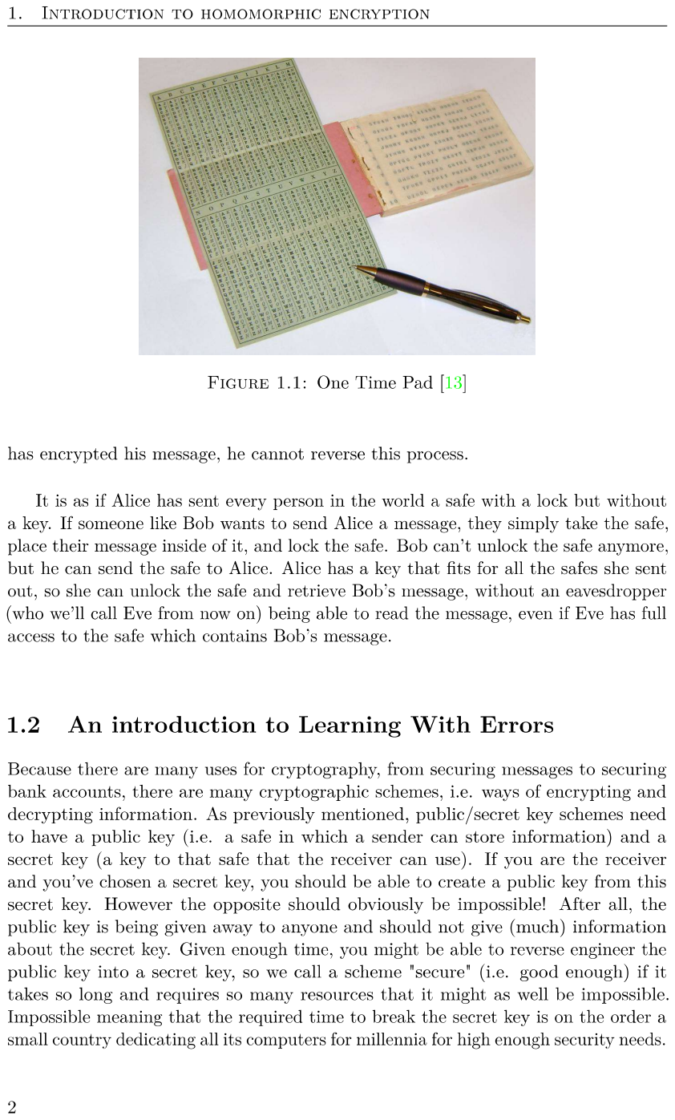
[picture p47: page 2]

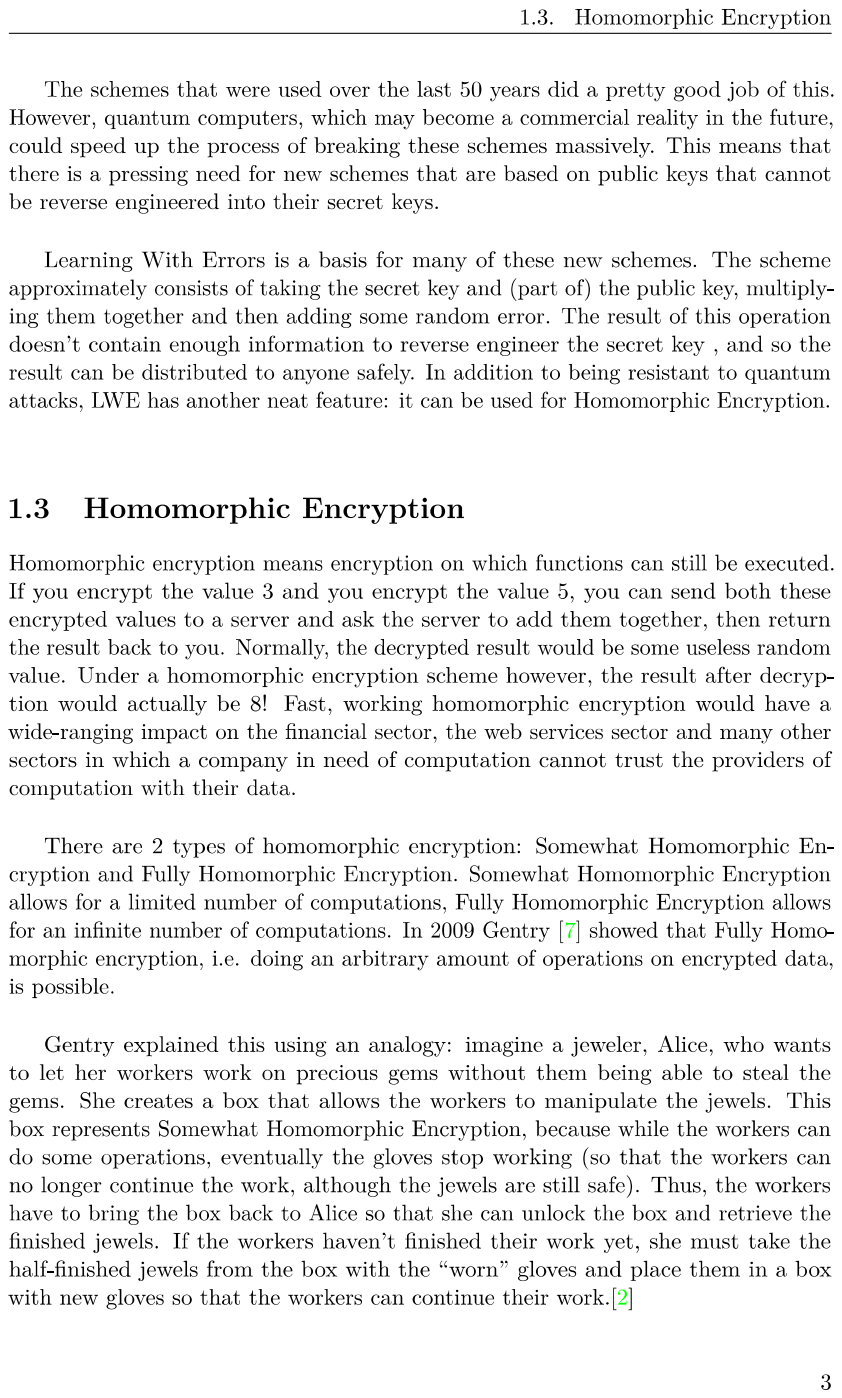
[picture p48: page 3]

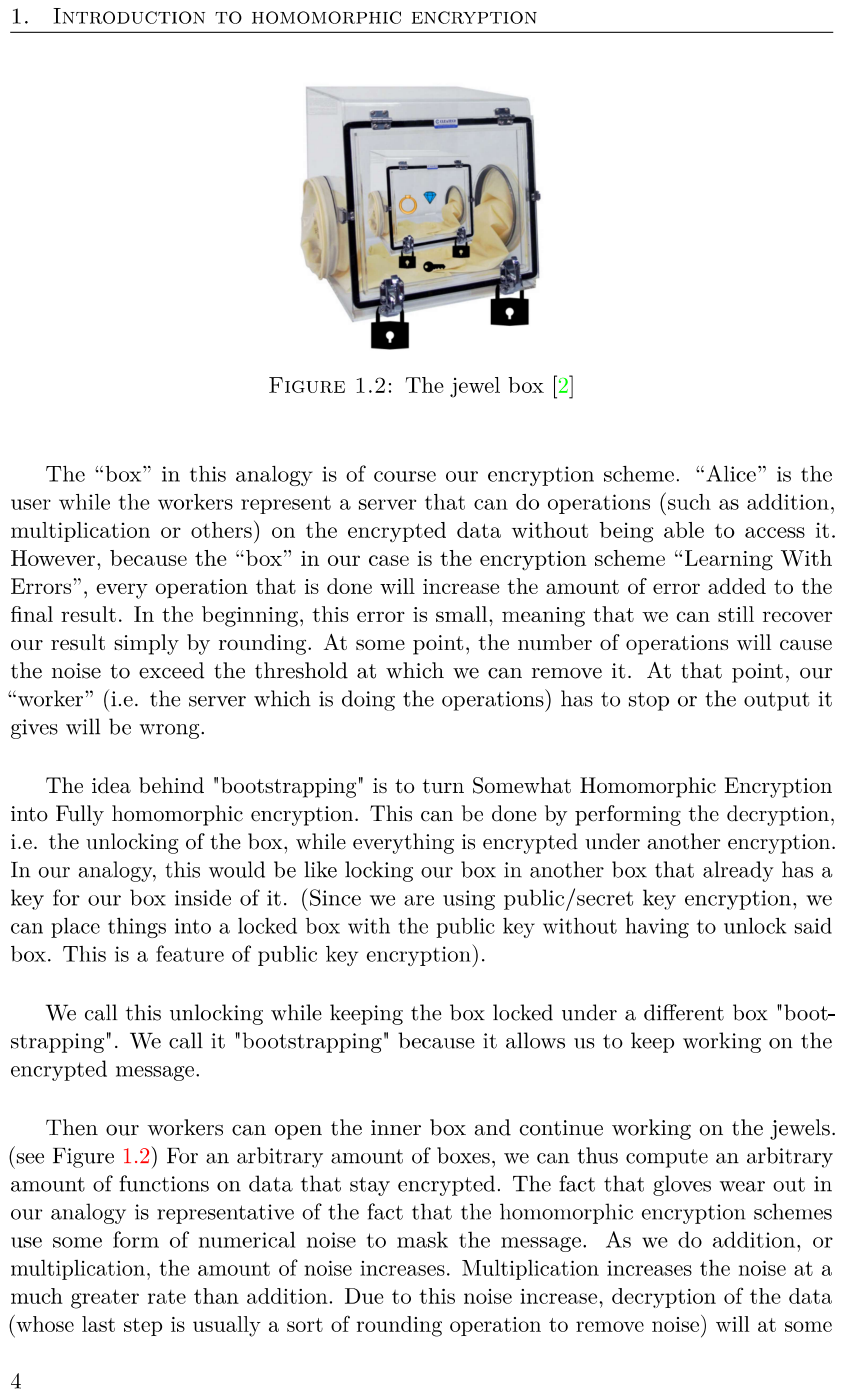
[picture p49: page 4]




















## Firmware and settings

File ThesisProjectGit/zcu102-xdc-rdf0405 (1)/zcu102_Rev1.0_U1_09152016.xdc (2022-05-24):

#################################################
### ZCU102 Rev1.0 Master XDC file 09-15-2016 ####
#################################################
#Other net   PACKAGE_PIN W17      - SYSMON_DXN                Bank   0 - DXN
#Other net   PACKAGE_PIN T18      - FPGA_SYSMON_AVCC          Bank   0 - VCCADC
#Other net   PACKAGE_PIN T17      - SYSMON_AGND               Bank   0 - GNDADC
#Other net   PACKAGE_PIN W18      - SYSMON_DXP                Bank   0 - DXP
#Other net   PACKAGE_PIN V18      - SYSMON_VREFP              Bank   0 - VREFP
#Other net   PACKAGE_PIN U17      - SYSMON_AGND               Bank   0 - VREFN
#Other net   PACKAGE_PIN U18      - SYSMON_VP_R               Bank   0 - VP
#Other net   PACKAGE_PIN V17      - SYSMON_VN_R               Bank   0 - VN
#Other net   PACKAGE_PIN AD15     - 3N5822                    Bank   0 - PUDC_B_0
#Other net   PACKAGE_PIN AD14     - 3N5824                    Bank   0 - POR_OVERRIDE
set_property PACKAGE_PIN J15      [get_ports "L12N_AD8N_50_N"] ;# Bank  50 VCCO - VCC3V3   - IO_L12N_AD8N_50
set_property IOSTANDARD  LVCMOS33 [get_ports "L12N_AD8N_50_N"] ;# Bank  50 VCCO - VCC3V3   - IO_L12N_AD8N_50
set_property PACKAGE_PIN J16      [get_ports "L12P_AD8P_50_P"] ;# Bank  50 VCCO - VCC3V3   - IO_L12P_AD8P_50
set_property IOSTANDARD  LVCMOS33 [get_ports "L12P_AD8P_50_P"] ;# Bank  50 VCCO - VCC3V3   - IO_L12P_AD8P_50
set_property PACKAGE_PIN G16      [get_ports "L11N_AD9N_50_N"] ;# Bank  50 VCCO - VCC3V3   - IO_L11N_AD9N_50
set_property IOSTANDARD  LVCMOS33 [get_ports "L11N_AD9N_50_N"] ;# Bank  50 VCCO - VCC3V3   - IO_L11N_AD9N_50
set_property PACKAGE_PIN H16      [get_ports "L11P_AD9P_50_P"] ;# Bank  50 VCCO - VCC3V3   - IO_L11P_AD9P_50
set_property IOSTANDARD  LVCMOS33 [get_ports "L11P_AD9P_50_P"] ;# Bank  50 VCCO - VCC3V3   - IO_L11P_AD9P_50
set_property PACKAGE_PIN H14      [get_ports "L10N_AD10N_50_N"] ;# Bank  50 VCCO - VCC3V3   - IO_L10N_AD10N_50
set_property IOSTANDARD  LVCMOS33 [get_ports "L10N_AD10N_50_N"] ;# Bank  50 VCCO - VCC3V3   - IO_L10N_AD10N_50
set_property PACKAGE_PIN J14      [get_ports "L10P_AD10P_50_P"] ;# Bank  50 VCCO - VCC3V3   - IO_L10P_AD10P_50
set_property IOSTANDARD  LVCMOS33 [get_ports "L10P_AD10P_50_P"] ;# Bank  50 VCCO - VCC3V3   - IO_L10P_AD10P_50
set_property PACKAGE_PIN G14      [get_ports "L9N_AD11N_50_N"] ;# Bank  50 VCCO - VCC3V3   - IO_L9N_AD11N_50
set_property IOSTANDARD  LVCMOS33 [get_ports "L9N_AD11N_50_N"] ;# Bank  50 VCCO - VCC3V3   - IO_L9N_AD11N_50
set_property PACKAGE_PIN G15      [get_ports "L9P_AD11P_50_P"] ;# Bank  50 VCCO - VCC3V3   - IO_L9P_AD11P_50
set_property IOSTANDARD  LVCMOS33 [get_ports "L9P_AD11P_50_P"] ;# Bank  50 VCCO - VCC3V3   - IO_L9P_AD11P_50
set_property PACKAGE_PIN G13      [get_ports "L8N_HDGC_50_N"] ;# Bank  50 VCCO - VCC3V3   - IO_L8N_HDGC_50
set_property IOSTANDARD  LVCMOS33 [get_ports "L8N_HDGC_50_N"] ;# Bank  50 VCCO - VCC3V3   - IO_L8N_HDGC_50
set_property PACKAGE_PIN H13      [get_ports "L8P_HDGC_50_P"] ;# Bank  50 VCCO - VCC3V3   - IO_L8P_HDGC_50
set_property IOSTANDARD  LVCMOS33 [get_ports "L8P_HDGC_50_P"] ;# Bank  50 VCCO - VCC3V3   - IO_L8P_HDGC_50
set_property PACKAGE_PIN H12      [get_ports "HDMI_SI5324_LOL"] ;# Bank  50 VCCO - VCC3V3   - IO_L7N_HDGC_50
set_property IOSTANDARD  LVCMOS33 [get_ports "HDMI_SI5324_LOL"] ;# Bank  50 VCCO - VCC3V3   - IO_L7N_HDGC_50
set_property PACKAGE_PIN J12      [get_ports "HDMI_SI5324_RST"] ;# Bank  50 VCCO - VCC3V3   - IO_L7P_HDGC_50
set_property IOSTANDARD  LVCMOS33 [get_ports "HDMI_SI5324_RST"] ;# Bank  50 VCCO - VCC3V3   - IO_L7P_HDGC_50
set_property PACKAGE_PIN F11      [get_ports "HDMI_SI5324_INT_ALM"] ;# Bank  50 VCCO - VCC3V3   - IO_L6N_HDGC_50
set_property IOSTANDARD  LVCMOS33 [get_ports "HDMI_SI5324_INT_ALM"] ;# Bank  50 VCCO - VCC3V3   - IO_L6N_HDGC_50
set_property PACKAGE_PIN F12      [get_ports "34N8121"] ;# Bank  50 VCCO - VCC3V3   - IO_L6P_HDGC_50
set_property IOSTANDARD  LVCMOS33 [get_ports "34N8121"] ;# Bank  50 VCCO - VCC3V3   - IO_L6P_HDGC_50
set_property PACKAGE_PIN G11      [get_ports "34N8125"] ;# Bank  50 VCCO - VCC3V3   - IO_L5N_HDGC_50
set_property IOSTANDARD  LVCMOS33 [get_ports "34N8125"] ;# Bank  50 VCCO - VCC3V3   - IO_L5N_HDGC_50
set_property PACKAGE_PIN H11      [get_ports "34N8129"] ;# Bank  50 VCCO - VCC3V3   - IO_L5P_HDGC_50
set_property IOSTANDARD  LVCMOS33 [get_ports "34N8129"] ;# Bank  50 VCCO - VCC3V3   - IO_L5P_HDGC_50
#set_property PACKAGE_PIN D10      [get_ports "34N8133"] ;# Bank  50 VCCO - VCC3V3   - IO_L4N_AD12N_50
#set_property IOSTANDARD  LVCMOS33 [get_ports "34N8133"] ;# Bank  50 VCCO - VCC3V3   - IO_L4N_AD12N_50
set_property PACKAGE_PIN D11      [get_ports "MSP430_GPIO_PL_0"] ;# Bank  50 VCCO - VCC3V3   - IO_L4P_AD12P_50
set_property IOSTANDARD  LVCMOS33 [get_ports "MSP430_GPIO_PL_0"] ;# Bank  50 VCCO - VCC3V3   - IO_L4P_AD12P_50
set_property PACKAGE_PIN E10      [get_ports "MSP430_GPIO_PL_1"] ;# Bank  50 VCCO - VCC3V3   - IO_L3N_AD13N_50
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

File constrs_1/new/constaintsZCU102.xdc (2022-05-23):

set topname   [get_property top [current_fileset]]

if { $topname == "INTT_wrapper"} {
create_clock -period 5 -name clk_gen -add [get_ports clk];
set_property PACKAGE_PIN AL8      [get_ports clk];# Bank  64 VCCO - VCC1V2   - IO_L12P_T1U_N10_GC_64
set_property IOSTANDARD  DIFF_SSTL12 [get_ports clk];# Bank  64 VCCO - VCC1V2   - IO_L12P_T1U_N10_GC_64
set_property PACKAGE_PIN AM14     [get_ports reset] ;# Bank  44 VCCO - VCC3V3   - IO_L2P_AD10P_44
set_property IOSTANDARD  LVCMOS33 [get_ports reset] ;# Bank  44 VCCO - VCC3V3   - IO_L2P_AD10P_44
set_property PACKAGE_PIN AJ15     [get_ports done_to_pin] ;# Bank  44 VCCO - VCC3V3   - IO_L8P_HDGC_AD4P_44
set_property IOSTANDARD  LVCMOS33 [get_ports done_to_pin] ;# Bank  44 VCCO - VCC3V3   - IO_L8P_HDGC_AD4P_44
}

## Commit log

2020-10-14 You know, files
    [DraftPlanning.xlsx]
2021-03-30 Why didn't I commit this stuff yet?
    [PARAM.txt]
2021-03-30 This should have been commited ages ago
    [PARAM.txt]
2021-03-30 should have done this ages ago
    [PowerSide.dxf, SmallSideDrawingAndHeightPrintPlate.dxf, USBEthernetSide.dxf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]
2021-04-07 lots of comments, new parameters
    [PARAM.txt]
2021-04-07 Newly Generated Files
    [PARAM.txt]
2021-04-25 This is what you'd call an intermediate stage: but after this I'm commiting to integrating bitReverse into the INTT
2021-05-17 Back where we were last evening: current status: one cycle finishes succesfully
2021-05-21 Getting close to correct readout, we already have correct execution
    [INTT.v]
2021-05-22 Sim now does same reset as is done for interface
    [testACAP_HW.v]
2022-05-23 Added test files and rest of sources to the vivado design.
    [PARAM.txt]
2022-05-24 Move all files
    [PARAM.txt]
2022-05-24 rename folder
    [PARAM.txt]
2022-05-24 move files
    [CPPLINT.cfg]
